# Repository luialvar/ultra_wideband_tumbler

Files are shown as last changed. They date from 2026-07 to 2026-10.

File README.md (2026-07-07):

# Tumbler UWB Subsystem Workspace

This repository organizes the hardware, mechanical-design, power-analysis, embedded-driver, and firmware material for the Tumbler UWB node in the AMADEE-27 university robotics project. The software migration from the older SKITH/DWM1000 platform to a newer STM32L4/DWM3000 PCB is a central part of the work, but it is not the whole project: the repository also captures the PCB, mechanical-integration, power-budget, and bring-up context needed to make the Tumbler subsystem usable.

The project is intentionally split by layer. The legacy folders are kept as engineering references, while the new CubeMX firmware and the Tumbler PCB are the active migration target.

## Project Context: AMADEE-27

This work was developed in the context of a university robotics project preparing a contribution for AMADEE-27, an international Mars analog mission managed by the Austrian Space Forum (OeWF).

AMADEE-27 is designed to emulate selected aspects of a human-robotic Mars mission. The mission concept combines analog astronauts, robotic systems, field experiments, and a Mission Support Center in Austria to recreate operational constraints similar to planetary exploration. The official AMADEE-27 call focuses on areas such as engineering and robotics, planetary surface operations, geoscience, life sciences, and human factors.

Within that broader university project, my responsibility was the Tumbler UWB subsystem rather than only a code port. That included understanding the old UWB localization stack, contributing to mechanical design and integration ideas, helping around the new PCB by studying the schematic/layout and matching it to firmware pin names, learning the practical hardware constraints, documenting the PCB and power-budget context, and preparing the new STM32CubeMX/HAL firmware structure for the upgraded PCB.

External context:

- Austrian Space Forum AMADEE-27 overview: https://oewf.org/en/amadee-27/
- AMADEE-27 Announcement of Opportunity: https://oewf.org/en/2025/12/amadee-27-ao/

## Tumbler Subsystem Scope

The important object in this repository is the Tumbler UWB subsystem as an integrated robot component. In practice, that means the work spans several connected areas:

- mechanical design exploration for fitting the electronics into the Tumbler concept,
- support and learning around the new PCB design, including how schematic/layout choices become firmware pin definitions,
- power-budget tracking for tag and anchor operating assumptions,
- low-level STM32L4/DWM3000 bring-up,
- migration of the old UWB ranging ideas onto a new CubeMX/HAL and Qorvo DW3xxx base.

The firmware migration is therefore one part of a larger embedded-system integration effort.

## Migration Summary

| Layer | Legacy platform | New platform |
| --- | --- | --- |
| Hardware | DWM1000-based SKITH board | DWM3000-based Tumbler board |
| Microcontroller | STM32F407 | STM32L431 |
| Framework | RODOS and legacy board wrappers | STM32Cube HAL generated by CubeMX |
| UWB driver | Decawave DWM1000 API | Qorvo DW3xxx driver |
| Application | Legacy tag/anchor ranging code | New CubeMX firmware for the new PCB |

## Repository Map

| Folder | Purpose |
| --- | --- |
| `SKITH_old_PCB/` | Legacy PCB design for the old SKITH UWB node. It represents the old hardware side of the DWM1000/STM32F407 platform. |
| `Tumbler_new_PCB/` | New PCB design for the upgraded UWB node. It contains the KiCad project, schematic sheets, layout, 3D exports, and production outputs for the DWM3000/STM32L431 board. |
| `power_calculations/` | Spreadsheet-based power budgets. The files are grouped around the old and new PCB assumptions, including anchor/tag operating modes. |
| `old_uwb_reference_repo/` | Legacy university toolkit component used as a software reference. It contains the old embedded DWM1000 firmware plus robot-side ROS localization code. |
| `software_new_pcb/` | New STM32CubeMX/HAL firmware for the new PCB. This is the active new-board software area. |
| `tumbler_images/` | Mechanical concept images and visual material for the Tumbler integration work. |
| `useful_links.txt` | Extra project links and references collected during development. |

## What Is Reused

The useful software inheritance is at the protocol level, not at the low-level driver level. The legacy code is valuable because it already contains the tag/anchor ranging flow, message types, timestamp packing, and two-way-ranging state machine. Those concepts can be ported to the new firmware.

The old Decawave DWM1000 driver, the RODOS scheduling code, the old SPI/GPIO wrappers, and the old board calibration constants should not be copied directly into the new STM32L431/DWM3000 firmware.

## Current Engineering Focus

The new firmware is built around STM32Cube HAL and the Qorvo DW3xxx driver. CubeMX describes the real wiring from the new PCB, including SPI, IRQ, reset, wakeup, power-control, and BMS-related pins. The firmware then uses those generated names in the board-port layer so that the UWB driver can talk to the DWM3000 through the actual hardware connections.

The practical bring-up path is:

1. Validate the CubeMX pin map against the Tumbler PCB schematic.
2. Bring up SPI, reset, wakeup, chip-select, and IRQ in the STM32 port layer.
3. Read the DW3xxx device ID through the Qorvo driver.
4. Test raw TX/RX frames.
5. Port the old tag/anchor ranging logic onto the new driver and HAL base.
6. Recalibrate antenna delays and timing for the new board.

## Engineering Highlights

This repository demonstrates a full embedded migration across hardware, firmware, and tooling boundaries:

- connecting mechanical integration constraints with the electronics layout,
- helping translate the new PCB design into a firmware-facing pin map,
- translating real PCB wiring into CubeMX/HAL pin definitions,
- replacing a legacy DWM1000 driver stack with the Qorvo DW3xxx driver,
- separating reusable ranging logic from non-reusable board/framework code,
- keeping only the required DW3xxx driver sources inside the firmware tree instead of storing the full vendor SDK,
- connecting firmware operating modes to spreadsheet-based power estimates.

## Notes for Reviewers

This repository is a migration and integration workspace, so it intentionally contains both original references and new implementation work. The separation is important: hardware design files document the boards, the power spreadsheets document expected operating modes, and the CubeMX firmware is where the new embedded software and DW3xxx driver integration are implemented.

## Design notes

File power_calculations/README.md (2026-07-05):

# Power Calculations

This folder contains spreadsheet-based power estimates for the UWB node designs.

The files cover two hardware generations:

| Power-budget family | Hardware context | Notes |
| --- | --- | --- |
| Legacy/earlier calculations | Older SKITH-style UWB assumptions | Kept as reference material for the DWM1000/STM32F407 generation. |
| `AmadeePannel3000.ods` | New DWM3000/Tumbler PCB assumptions | Main reference for the new DWM3000/STM32L431 design and its tag/anchor modes. |

## Files

| File | Purpose |
| --- | --- |
| `AmadeePannel3000.ods` | Power budget for the newer DWM3000-based board. It includes operating-mode assumptions such as TX, RX, idle, and sleep, and separates tag-style and anchor-style behavior. |
| `AmadeePannel_1.ods` | Earlier power-calculation reference. |
| `AmadeePannel_2.ods` | Earlier power-calculation reference. |
| `Power Calculation.xlsx` | Additional spreadsheet reference for the power budget. |
| `.~lock.AmadeePannel.ods#` | LibreOffice lock/temporary file. It is not an engineering input and should not normally be committed. |

## How to Read the Estimates

The power model combines two things:

1. The current consumed by the hardware in each mode.
2. The amount of time the firmware expects to spend in each mode.

The basic calculation is:

```text
energy = voltage * current * time
```

For a complete day, the spreadsheet adds the energy of the relevant modes:

```text
total energy = TX energy + RX energy + idle energy + sleep energy
```

This matters because tag and anchor roles do not behave the same way. A tag can often sleep for most of the time and wake up only for ranging exchanges. An anchor usually consumes more because it must listen for incoming UWB messages for much longer periods.

## Link to Firmware

The firmware cannot change the physical current of the DWM3000 or STM32 by itself, but it can control how long the system stays in TX, RX, idle, and sleep. That is why the power spreadsheets and the embedded state machine need to be reviewed together.

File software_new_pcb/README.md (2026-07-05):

# New PCB Software

This folder contains the firmware work for the new Tumbler PCB. This is the active software area for the new board.

## Target Platform

| Layer | New target |
| --- | --- |
| Hardware | Tumbler PCB |
| UWB module | DWM3000 family |
| Microcontroller | STM32L431 |
| Framework | STM32Cube HAL generated from CubeMX |
| UWB driver | Qorvo DW3xxx driver |
| Application goal | Port the legacy tag/anchor ranging logic onto the new board |

## Folder

| Folder | Purpose |
| --- | --- |
| `stm32l4/` | STM32CubeMX/CMake firmware project for the STM32L431-based PCB. |

The firmware target is described in more detail in `stm32l4/README.md`.

## Relationship to the Other Folders

The new firmware uses:

- `../Tumbler_new_PCB/` as the hardware pinout and board-design reference.
- `stm32l4/Drivers/dwt_uwb_driver/` and `stm32l4/Drivers/dwt_uwb_src/` as the local DW3xxx driver integration.
- `../old_uwb_reference_repo/embedded_uwb/` as the old application/protocol reference.
- `../power_calculations/` to understand expected current draw for tag and anchor operating modes.

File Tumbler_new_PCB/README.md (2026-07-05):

# Tumbler New PCB

This folder contains the new PCB design for the upgraded UWB node. It is the hardware target for the STM32CubeMX/HAL firmware in `../software_new_pcb/`.

In the overall migration, this is the new hardware platform:

| Layer | Value |
| --- | --- |
| UWB module | DWM3000 family |
| Microcontroller | STM32L431 |
| Firmware stack | STM32Cube HAL plus Qorvo DW3xxx driver |
| Role in this repository | Active hardware target for the new firmware |

## Contents

| File or folder | Purpose |
| --- | --- |
| `Amadee.kicad_pro` | Main KiCad project entry point. Open this file first in KiCad. |
| `Amadee.kicad_sch` | Top-level schematic. |
| `mcu.kicad_sch` | Microcontroller schematic sheet. |
| `B2Bconn.kicad_sch` | Board-to-board connector sheet. |
| `bms.kicad_sch` | Battery-management subsystem sheet. |
| `buck.kicad_sch` | Buck-regulator/power-conversion sheet. |
| `usb.kicad_sch` | USB-related circuitry. |
| `back-to-back-fets.kicad_sch` | Power-path/protection FET sheet. |
| `Amadee.kicad_pcb` | PCB layout. |
| `AmadeeTumbler.step` | 3D mechanical export for CAD review. |
| `AmadeeTumbler.stl` | 3D mesh export. |
| `AmadeeTumbler.pdf` | PDF design export for quick review. |
| `production/` | Manufacturing outputs. |
| `PowerCalc/` | Power-calculation spreadsheets colocated with the PCB project. |
| `lib/` | KiCad footprint/library assets used by the board. |

## Firmware-Relevant Signals

The PCB defines the real electrical wiring. CubeMX must mirror that wiring so the firmware can use the correct MCU pins for:

| Signal group | Why it matters in firmware |
| --- | --- |
| SPI | Data path between the STM32L431 and the DWM3000. |
| Chip select | Selects the UWB chip during SPI transactions. |
| IRQ | Lets the DWM3000 notify the MCU about TX/RX events. |
| Reset | Allows the MCU to reset the UWB module during bring-up. |
| Wakeup | Lets the MCU bring the UWB module out of low-power states. |
| Power and BMS pins | Control and monitor board power behavior. |

This is why the PCB and CubeMX project must agree. The PCB is the physical truth; CubeMX translates that physical wiring into generated C names used by the HAL and by the Qorvo driver port layer.

## Relationship to the Old PCB

The old `../SKITH_old_PCB/` design represents the DWM1000/STM32F407 generation. This folder represents the DWM3000/STM32L431 generation.

The migration is therefore not just a source-code copy. It changes the radio module, the MCU, the framework, the low-level driver, and the board pinout.

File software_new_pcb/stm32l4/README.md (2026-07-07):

# STM32L4 Firmware for the New PCB

This is the STM32CubeMX/CMake firmware project for the new STM32L431-based UWB PCB. It is the active software target for the migration from the old SKITH/DWM1000 platform to the new DWM3000-based board.

<p align="center">
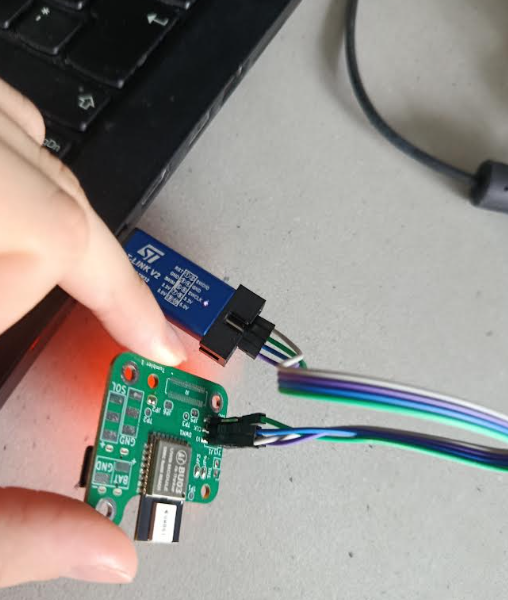
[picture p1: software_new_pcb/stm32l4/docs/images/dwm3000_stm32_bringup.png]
DWM3000 and STM32L4 bring-up wiring on the bench
  
</p>

<p align="center"><em>Bench wiring used while checking the DWM3000/STM32L4 bring-up path.</em></p>

## Migration Context

| Layer | Legacy stack | New stack in this folder |
| --- | --- | --- |
| Hardware | SKITH board with DWM1000 | Tumbler PCB with DWM3000 family module |
| Microcontroller | STM32F407 | STM32L431 |
| Framework | RODOS and legacy wrappers | STM32Cube HAL |
| UWB driver | Decawave DWM1000 API | Qorvo DW3xxx driver |
| Application | Old tag/anchor firmware | New CubeMX firmware for the new PCB |

The goal is to keep the useful ranging protocol concepts from the old firmware while replacing the hardware-dependent layers with CubeMX/HAL and the Qorvo DW3xxx driver.

## Project Structure

| Path | Purpose |
| --- | --- |
| `stm32l4.ioc` | CubeMX project file. It defines the STM32L431 device, clock tree, peripherals, and pin names. |
| `Core/` | STM32CubeMX-generated application skeleton and HAL initialization code. |
| `Drivers/CMSIS/` | ARM/ST CMSIS support generated/copied by STM32CubeMX. |
| `Drivers/STM32L4xx_HAL_Driver/` | STM32L4 HAL driver sources from the STM32Cube firmware package. |
| `Drivers/dwt_uwb_driver/` | Local Qorvo DW3xxx driver sources used by this firmware. |
| `Drivers/dwt_uwb_src/` | Local Qorvo support/example source files used by the DW3xxx driver integration. |
| `platform/` | Board-port layer connecting the Qorvo driver to STM32 HAL SPI, GPIO, reset, wakeup, and IRQ functions. |
| `Communication/` | Early send/receive helper functions for DW3xxx frame exchange. |
| `cmake/` | Toolchain and CubeMX CMake integration files. |
| `CMakeLists.txt` | Main firmware build definition. |

## CubeMX Pin Mapping

CubeMX translates the physical PCB wiring into generated C symbols. The important firmware-facing signals are:

| MCU pin | CubeMX label | Role |
| --- | --- | --- |
| `PA0` | `DWM_IRQ` | Interrupt from the UWB module. |
| `PA4` | `SPI1_NSS` | Software-controlled chip select for SPI. |
| `PA5` | `SPI1_SCK` | SPI clock. |
| `PA6` | `SPI1_MISO` | SPI data from DWM3000 to STM32. |
| `PA7` | `SPI1_MOSI` | SPI data from STM32 to DWM3000. |
| `PB0` | `EXTON` | External enable/control signal. |
| `PB1` | `WAKEUP` | Wakeup signal for the UWB module. |
| `PB2` | `DWM_nRST` | Reset line for the UWB module. |
| `PA9` | `BMS_SCL` | I2C clock for battery-management communication. |
| `PA10` | `BMS_SDA` | I2C data for battery-management communication. |

The PCB is the electrical source of truth. CubeMX mirrors that wiring, and the generated names are then used by `platform/port.c` so the Qorvo driver can access the real SPI and GPIO lines.

## Driver Integration

The Qorvo driver is not generated by CubeMX. The full DW3xxx/QM33 SDK is not stored as a separate folder in this repository; only the driver and support sources needed by this firmware are kept locally:

- `Drivers/dwt_uwb_driver/`
- `Drivers/dwt_uwb_src/`

The local project glue is mainly in:

- `platform/port.c`
- `platform/port.h`
- `platform/dw3000_config.c`
- `platform/dw3000_config.h`
- `Communication/communication.c`
- `CMakeLists.txt`
- `Core/Inc/main.h`
- `Core/Src/main.c`

## Current Bench and Debug Evidence

A recent GDB/OpenOCD debug capture shows the current firmware state:

- `build/stm32l4.elf` can be loaded in GDB and attached through `target extended-remote localhost:3333`, so the host debugger path is usable.
- Execution reaches `main()` and the current test loop in `Core/Src/main.c`.
- The firmware then spends time in the large `HAL_Delay(100000000000)` placeholder; this is bring-up scaffolding, not final runtime scheduling.
- A breakpoint reaches `send_msg_polling()` in `Communication/communication.c` with the test payload before `dwt_writetxdata(...)`, so the active firmware test surface is still raw DW3xxx frame transmission.
- Before treating TX/RX as validated, the communication helpers still need cleanup: `send_msg_polling()` should receive an explicit payload length instead of using `sizeof(msg)` on a pointer, and the receive path should clear the caller-provided buffer rather than the local pointer variable.

## Build

```shell
cmake -S . -B build -DCMAKE_TOOLCHAIN_FILE=cmake/gcc-arm-none-eabi.cmake -DCMAKE_UWB_CONFIG_OPTION=5
cmake --build build
```

## Flash

Flash the ELF with an ST-Link:

```shell
st-flash --reset write build/stm32l4.elf 0x8000000
```

If the `st-flash` version has issues with ELF flashing, convert the output to a binary first:

```shell
arm-none-eabi-objcopy -O binary build/stm32l4.elf build/stm32l4.bin
st-flash --reset write build/stm32l4.bin 0x8000000
```

## Debug

Start OpenOCD in one terminal:

```shell
openocd -f /usr/share/openocd/scripts/interface/stlink-v2.cfg -f /usr/share/openocd/scripts/target/stm32l4x.cfg
```

Open GDB in another terminal:

```shell
gdb build/stm32l4.elf
```

Connect to the OpenOCD GDB server:

```shell
target extended-remote localhost:3333
```

## Bring-Up Path

The recommended order is:

1. Confirm the CubeMX pin map against `../../Tumbler_new_PCB/`.
2. Validate SPI chip-select, reset, wakeup, and IRQ behavior in `platform/port.c`.
3. Read the DW3xxx device ID through the Qorvo driver.
4. Replace the placeholder delay/test loop and pass explicit message lengths through the communication helpers.
5. Send and receive a raw UWB frame.
6. Port the old tag/anchor protocol from `../../old_uwb_reference_repo/embedded_uwb/`.
7. Calibrate antenna delays and timing on the new PCB.

This keeps the migration clean: protocol logic is reused, but the hardware driver and board layer are native to the new DWM3000/STM32L431 platform.

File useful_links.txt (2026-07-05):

documentation chip:
http://galileo2.informatik.uni-wuerzburg.de/wiki/index.php/SKITH
http://galileo2.informatik.uni-wuerzburg.de/wiki/index.php/SKITH-Mainboard-STM32F4_Ver.2

Proposed Hardware:
https://voltaicsystems.com/1-watt-6-volt-solar-panel-etfe/
https://ydlbattery.com/products/3-7v-4000mah-606090-lithium-polymer-ion-battery-1
https://www.adafruit.com/product/390

Datasheets hardware:
https://voltaicsystems.com/content/P124_ds.pdf
https://www.honcell.com/Public/Uploads/uploadfile/files/20240628/DATASHEETHCP6060903.7V4000mAhCELL2024.pdf
https://cdn-shop.adafruit.com/datasheets/MCP73871.pdf

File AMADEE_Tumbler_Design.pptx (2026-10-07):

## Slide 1

Team: Tumbler Design

AMADEE-27

Tumbler
Design

Final semester meeting

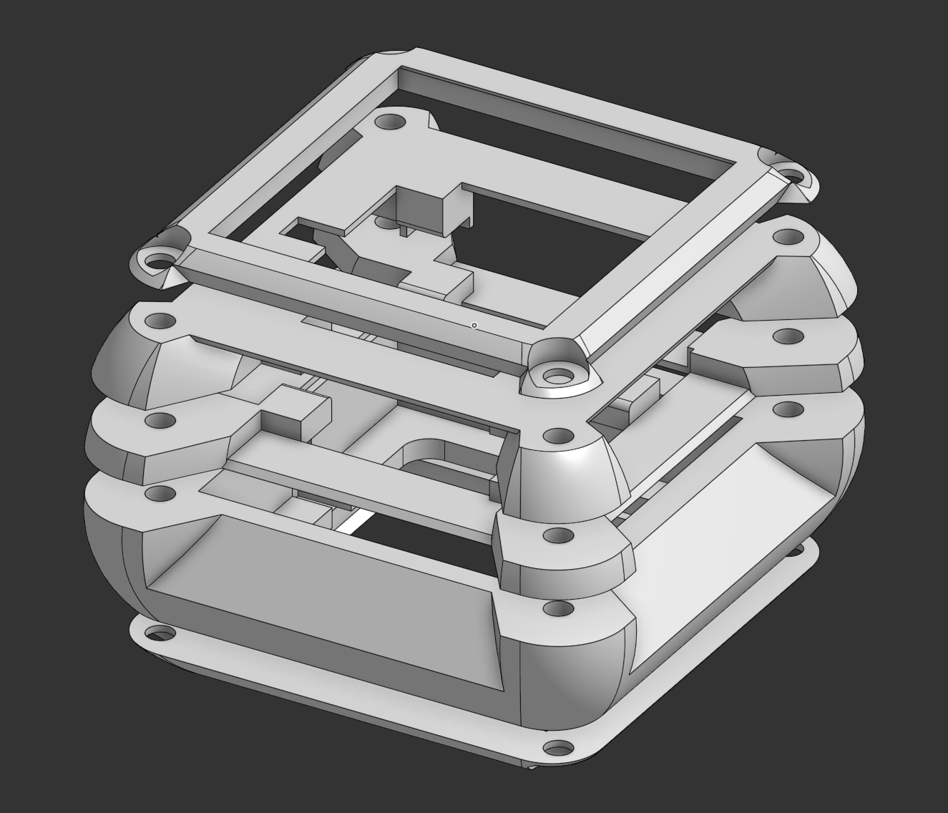
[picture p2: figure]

28 September 2026

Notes: Open the final meeting with a clear frame: team, work package, and format. Keep this under 15–20 seconds.

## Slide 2

TUMBLER DESIGN

What was the problem?

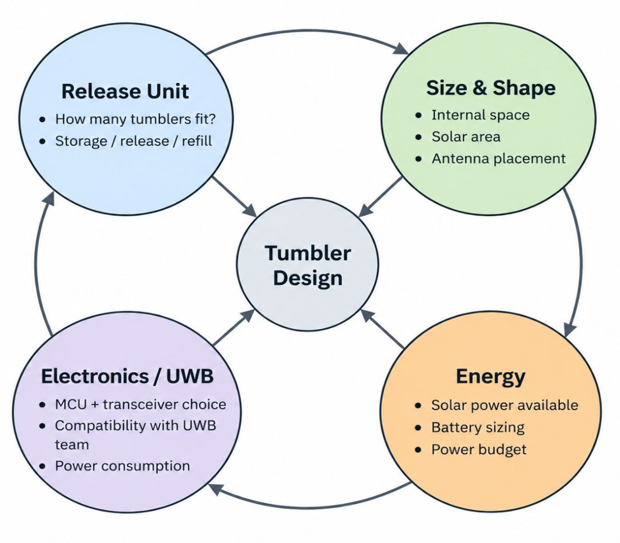
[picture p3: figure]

- autonomous Tumbler

- existing SKITH PCB

- STM32F407 + DWM1000

- RODOS-based UWB code

- Release Unit still open

Starting point

AMADEE-27 · Tumbler Design · Final Semester Meeting

2

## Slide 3

TUMBLER DESIGN

How did we structure the work?

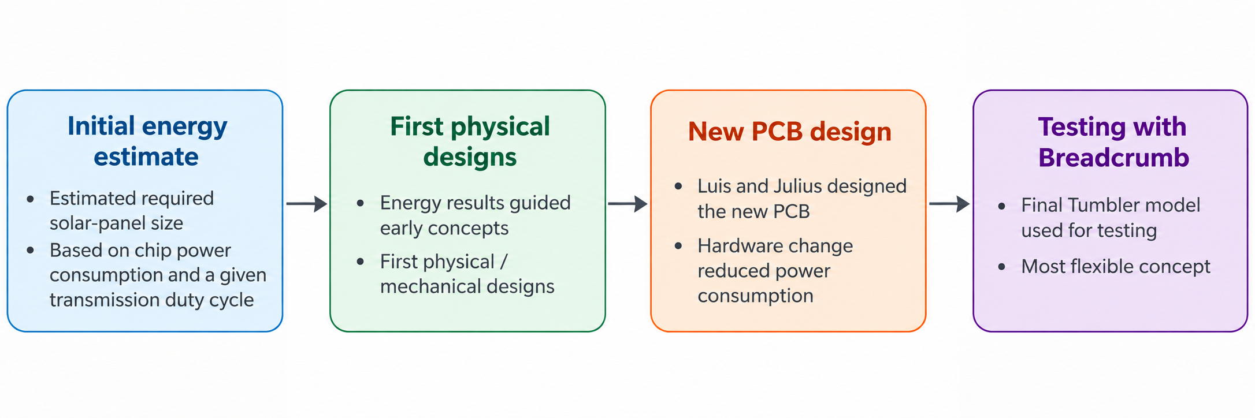
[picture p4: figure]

AMADEE-27 · Tumbler Design · Final Semester Meeting

3

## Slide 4

TUMBLER DESIGN

Power Requirement

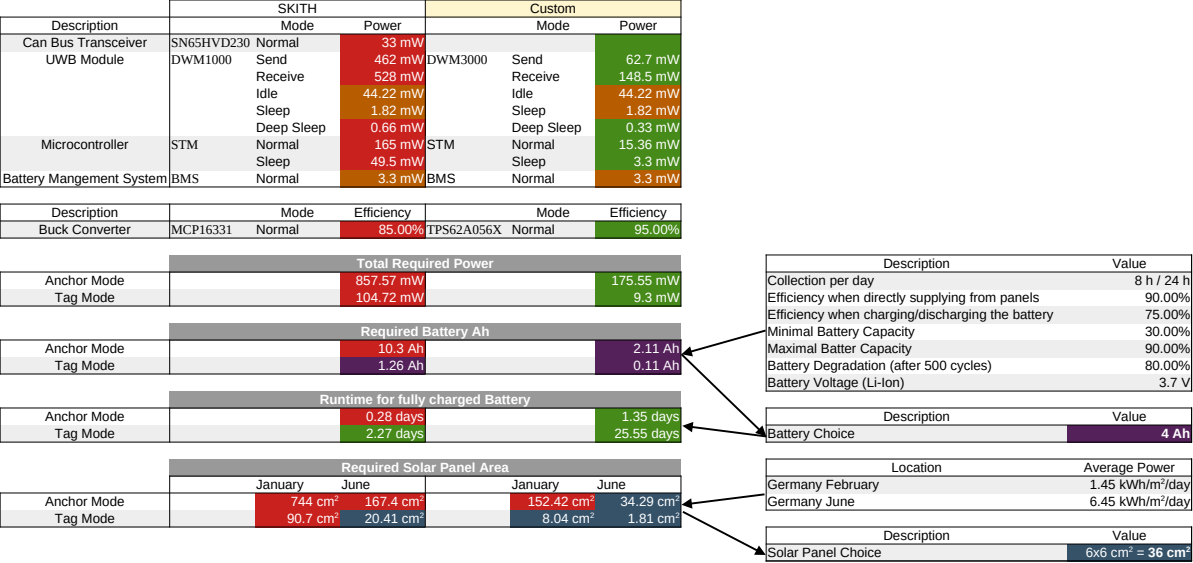
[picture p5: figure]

AMADEE-27 · Tumbler Design · Final Semester Meeting

4

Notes: Use this slide during the preparation call to decide the actual demo format.
For the final deck, either keep it as a short “Demonstration” slide or replace it with the actual demo material.
Assign responsibility: who brings the printed prototype, who opens CAD, who explains the test result.
Keep the demo short enough to leave time for Q&A.

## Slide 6

Tumbler Electronic Architecture

TUMBLER DESIGN

ETFE solar panel

a. P124 1.2W 6V ~ 5400 mm²
b. P122 0.3W 6V ~ 2500 mm²
- 24.4% high-efficiency
- Low friction, anti-dust surface
- IPX7 waterproof rated
Up to 5 panels can be soldered to the PCB
(in parallel)

Power Circuit

BQ25798 MPPT + Battery management
TPS62A056 High-Efficiency Buck Converter
4000mAh Lipo
Battery charging via USB-C interface

Microcontroller

STM32L431CCT6
- Ultra-low-power
- Arm Cortex-M4 MCU 80 MHz
- 256 Kbytes of Flash memory
- with FPU
- I2C and SPI
- standard ST-Link debugging

UWB Chip

DWM3000
Pin and pitch compatible with the DWM1000

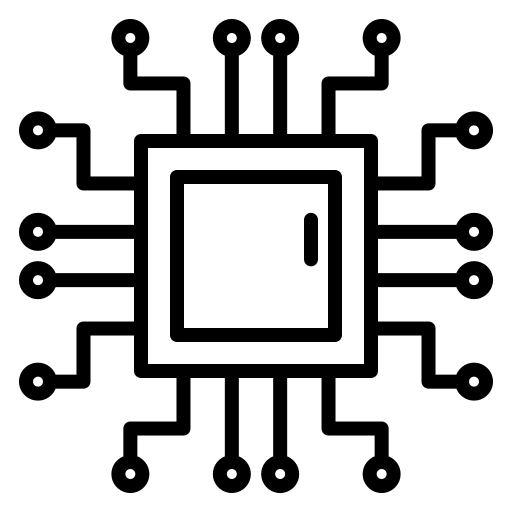
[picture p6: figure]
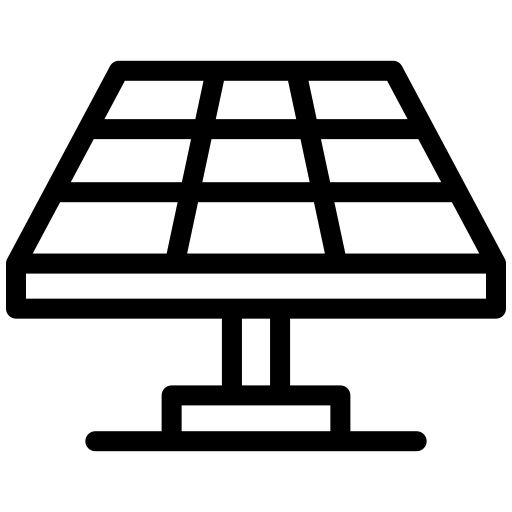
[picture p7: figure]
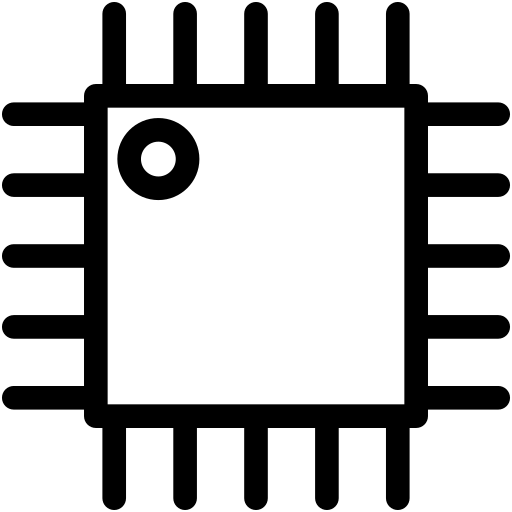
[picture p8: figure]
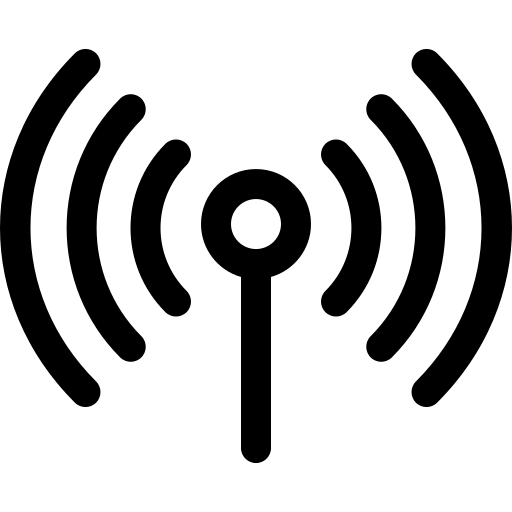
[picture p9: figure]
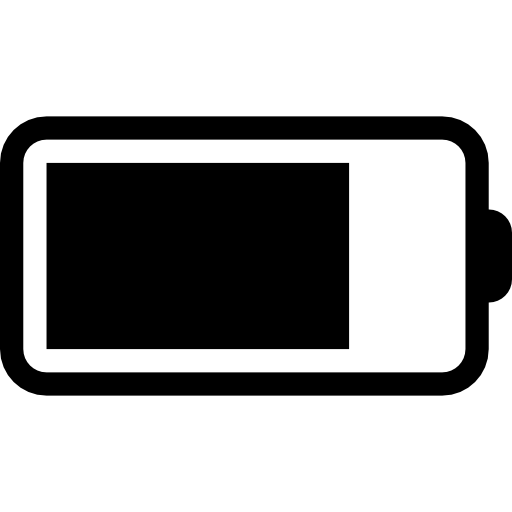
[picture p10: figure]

AMADEE-27 · Tumbler Design · Final Semester Meeting

5

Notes: Use this slide to show that the design was not arbitrary.
Mention that early discussions included release constraints, solar panel placement, internal layout and UWB signal considerations.
Do not overpromise exact requirements unless the team has numbers. Keep it qualitative unless someone fills in confirmed values.

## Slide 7

TUMBLER DESIGN

Tumbler PCB

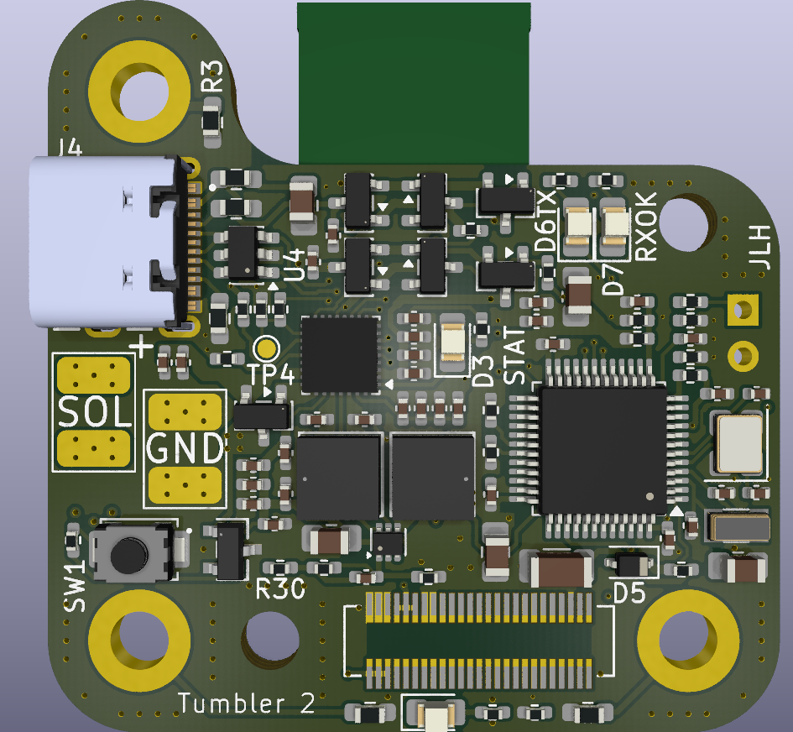
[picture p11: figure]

AMADEE-27 · Tumbler Design · Final Semester Meeting

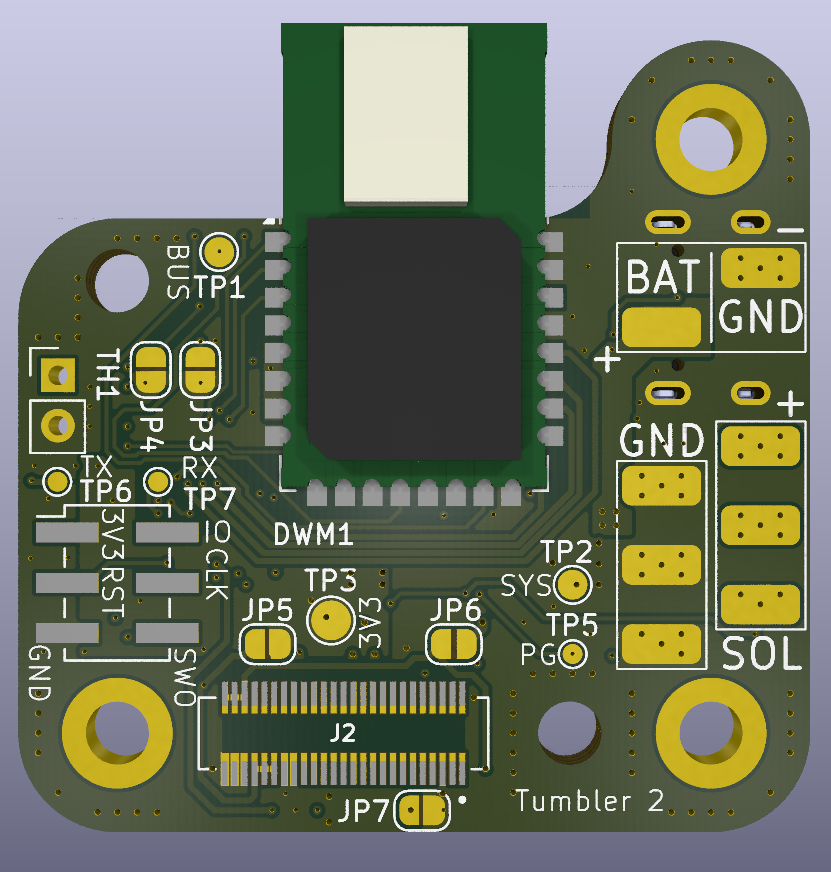
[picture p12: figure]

6

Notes: Use this slide to show that the design was not arbitrary.
Mention that early discussions included release constraints, solar panel placement, internal layout and UWB signal considerations.
Do not overpromise exact requirements unless the team has numbers. Keep it qualitative unless someone fills in confirmed values.

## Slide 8

Interface with the Release Unit

TUMBLER DESIGN

Release constraints

- stacking / pushing

- orientation-agnostic

Design response

- rigid alternatives

- release compatibility

AMADEE-27 · Tumbler Design · Final Semester Meeting

7

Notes: Mention that the release mechanism influenced the outer shape and handling of the Tumbler.
In the Release Unit chat, the initial assumption was that a compressible/foldable Tumbler might need to be held compressed and released by a mechanism.
I clarified that our group had also discussed rigid alternatives where compression would not be necessary.
Important message: the Tumbler was treated as part of a deployable system, not only as an isolated housing.
“Because the Tumbler is not an isolated object, the release mechanism was one of the first external interfaces we had to align with.”
Early interface alignment changed the design discussion from “one isolated housing” to a deployable sytsme component.
The Tumber geometry was iterated together with external deployment contraints – not chosen only for appearance.

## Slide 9

Concept comparison

TUMBLER DESIGN

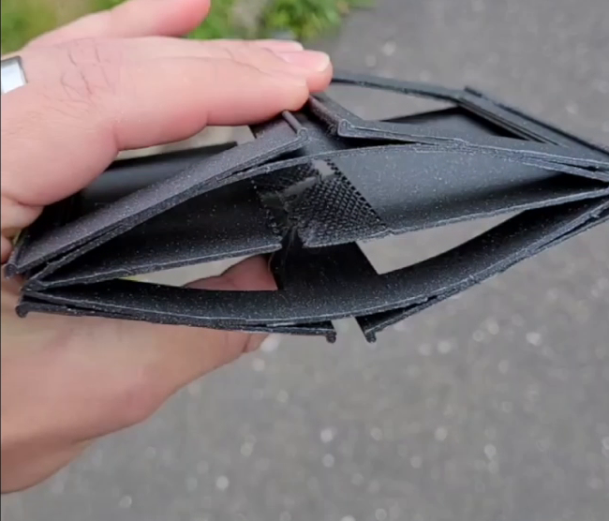
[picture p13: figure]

Flex / folded

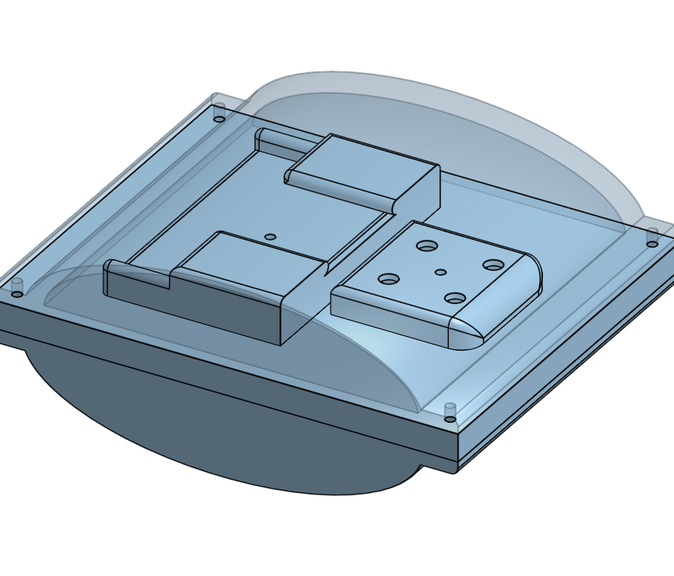
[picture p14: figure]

Oval

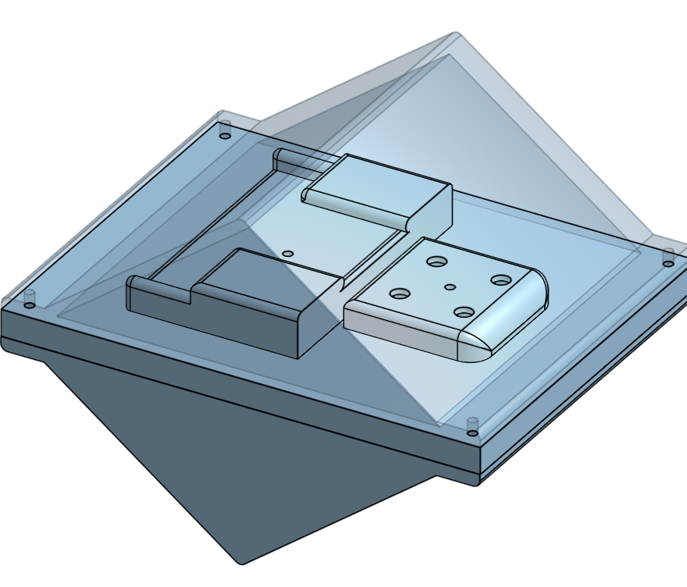
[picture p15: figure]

Prism

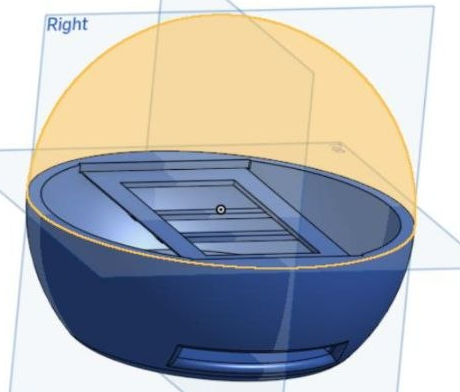
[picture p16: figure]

Sphere

AMADEE-27 · Tumbler Design · Final Semester Meeting

8

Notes: The designs developed in parallel and were compared as different solution directions, not as a competition between people.
Flex/folded: compact storage and compression idea, but more mechanically complex.
Oval/prism: rigid alternatives that avoided compression and were easier to reason about for release.
Spherical design: later became the basis for the current Breadcrumb direction.
The main selection dimensions were release compatibility, storage, solar-panel placement, internal volume, robustness and feasibility.
“We did not want to decide immediately on one perfect shape. Instead, we compared multiple concepts against the main constraints.”
Mention that the early rigid concepts helped clarify that a non-compressed, orientation-agnostic Tumbler would be easier for release.
The early phase intentionally kept several geometries open so the team could evaluate trade.offs before converging on the current Breadcrumb design.
The final direction was not a single first idea”; it results from the comparing deployment, panel area, internal layout, robustness and testability.

Nicht Sphere to breadcrumb, sondern Trends bei dem Prototyping die dann in Richtung Breadcrumb gingen.

Üvbergang zu dem Finalen Design:
Several issues were investigated during the semester; some became part of the final design, others were resolved through later geometry updates.
The design evolved through prototype-driven decisions. The geometry issue noticed during print preparation was trace to a wrong prat/revision selection and is fixed ion the current revision.
This slide should explain the real evolution: we did not start by picking one final design.
First, the group continued to work on all four directions in parallel.
Then the team focused on an improved spherical design because it combined strengths from the other approaches.
The sphere was flattened to improve storage in the Release Unit and make the geometry more space-efficient. This led to the Breadcrumb concept.

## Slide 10

TUMBLER DESIGN

Final mechanical design

Requirements:
- Compatible with the designs of the Tumbler release Unit..
- Ease of assembly in large numbers.
- Capable of good message reception and transmission.

AMADEE-27 · Tumbler Design · Final Semester Meeting

9

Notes: Likely owner: CAD/mechanical design owners.
Visible slide is intentionally clean: add final CAD images only.
Suggested content: what are the final parts, how are they assembled, how do solar panels sit in the housing, what changes were made after previous iterations.
If seals are no longer needed, explain calmly: “The updated geometry reduces/removes the sealing need that we had previously considered.”

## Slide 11

Status and next steps

TUMBLER DESIGN

completed / ready

- Tumbler geometry final

- PCB revision ordered

- mass-print ready

before next semester

- mass print: requested quantity

- order missing parts

- stock check

- storage preparation

before shipment

- final assembly

- handover

AMADEE-27 · Tumbler Design · Final Semester Meeting

10

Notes: The Tumbler design is finalized and can be mass-printed depending on the desired quantity.
The new PCBs have been ordered.
Before the next semester, the team should finish printing the required number of Tumbler parts, order any components that are not yet available in the required quantity, and store everything properly: Tumbler parts, batteries, solar panels and PCBs.
Before the hardware is shipped for the mission or later integration phase, the Tumblers can either be assembled by us, or if desired, an assembly guide could be provided so that assembly can happen later.
Avoid overclaiming: say the design work package is largely complete; the remaining tasks are procurement, production/storage and later assembly/integration.
The design work package is largely complete; the remaining work is focused on printing, procurement, storage and later assembly/integration.
The main design phase is finished; the next phase is turning the finalized parts into stroed, ready-to-assemble hardware for later AMADEE integration stage.
Mention the updated status: new PCBs are ordered and the Tumblers are finalized, so they can be printed in quantity.
Next concrete steps before the semester starts: final print, final orders, store components (Tumbler parts, batteries, solar panels, PCBs).
Later assembly is expected around November/December when the parts are actually needed.

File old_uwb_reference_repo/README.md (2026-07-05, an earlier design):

# Old UWB Reference Repository

This folder is the legacy UWB localization repository used as a reference for the migration. It comes from a university toolkit around UWB localization and includes both embedded firmware for the old SKITH boards and robot-side localization software.

It is not the target firmware for the new PCB. Its value is that it documents the old system architecture and contains reusable application-level ranging logic.

## Historical Context

This project gathers code connected to the UWB localization approach introduced in the included master-thesis PDF:

`An EKF-SLAM based Ultra Wideband Localization Approach for Unknown Anchor Distributions.pdf`

The repository is structured in two main parts:

| Folder | Purpose |
| --- | --- |
| `embedded_uwb/` | Embedded firmware for the old SKITH UWB boards. This is the main reference for the legacy tag/anchor ranging flow. |
| `robot/` | Robot-side ROS code, including UWB localization and EKF integration. |

## Role in the Migration

The old stack belongs to this generation:

| Layer | Legacy value |
| --- | --- |
| Hardware | SKITH board with DWM1000 |
| Microcontroller | STM32F407 |
| Framework | RODOS and legacy wrappers |
| Driver | Decawave DWM1000 API |
| Application | Tag/anchor ranging firmware and robot-side localization |

The new target is:

| Layer | New value |
| --- | --- |
| Hardware | Tumbler PCB with DWM3000 |
| Microcontroller | STM32L431 |
| Framework | STM32Cube HAL |
| Driver | Qorvo DW3xxx driver |
| Application | New CubeMX firmware for the new PCB |

## What Is Reusable

The useful reusable material is the application/protocol logic:

- tag/anchor message flow,
- `POLL`, `RESP`, `FINAL`, and distance-message structure,
- timestamp packing and unpacking,
- double-sided two-way-ranging timing math,
- node-state transitions and sequencing.

The old DWM1000 driver, RODOS scheduling code, ROS bridge, board wrappers, SPI/GPIO/reset plumbing, and antenna-delay constants are legacy-platform specific and should not be copied directly into the new STM32L431/DWM3000 firmware.

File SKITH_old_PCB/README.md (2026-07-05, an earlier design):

# SKITH Old PCB

This folder contains the legacy PCB design for the older SKITH UWB node used as the starting point of the migration.

In the overall project, this is the old hardware reference:

| Layer | Value |
| --- | --- |
| UWB module | DWM1000 |
| Microcontroller family | STM32F407 |
| Firmware stack used with this board | RODOS, legacy wrappers, Decawave DWM1000 API |
| Role in this repository | Hardware reference for the legacy platform |

## Contents

| File or folder | Purpose |
| --- | --- |
| `skithSTMv2.kicad_pro` | KiCad project entry point. Open this file in KiCad to inspect the board. |
| `skithSTMv2.kicad_pcb` | PCB layout. |
| `skithSTMv2.sch` | Legacy schematic file. |
| `Schaltplan_Skith_STM_2.pdf` | PDF schematic export for quick review. |
| `skithSTMv2.brd` | Board file from the older design flow. |
| `sym-lib-table` | KiCad symbol-library configuration. |
| `skithSTMv2.kicad_dru` | KiCad design-rule settings. |
| `skithSTMv2.kicad_prl` | KiCad local/session state; useful for KiCad, but not part of the engineering design itself. |

## How This Fits the Migration

This board is not the firmware target for the new implementation. It is included so the old DWM1000/STM32F407 hardware can be compared against the new DWM3000/STM32L431 design.

The old firmware associated with this hardware is kept separately in `../old_uwb_reference_repo/embedded_uwb/`. The PCB files here describe the electrical design: connectors, MCU pins, UWB module wiring, power rails, and board layout.

For the new board, see `../Tumbler_new_PCB/`.

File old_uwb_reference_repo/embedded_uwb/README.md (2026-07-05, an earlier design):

# Legacy Embedded UWB Firmware

This folder contains the embedded firmware for the old SKITH UWB boards. It is included as a reference for the new DWM3000/STM32L431 firmware, not as code that should be copied directly.

## Hardware

The original target is the SKITH UWB board from the University of Wuerzburg environment. The board combines:

| Part | Legacy platform |
| --- | --- |
| Microcontroller | STM32F4 family, specifically the STM32F407 generation in this project context |
| UWB transceiver | Decawave DWM1000 |
| Programming/debug | ST-Link over SWD |
| Framework | RODOS plus legacy board wrappers |

The hardware design files for the old board are stored separately in `../../SKITH_old_PCB/`.

## Software Structure

| Folder | Purpose |
| --- | --- |
| `decadriver/` | Legacy Decawave DWM1000 driver code. |
| `wrapper/` | Board-support wrappers around the old driver and platform. |
| `rodos/` | RODOS framework sources used by the old firmware. |
| `ros_lib/` | RODOS/ROS bridge support. |
| `include/` | Shared headers for the UWB application. |
| `src/common/` | Shared protocol, timestamp, and state-machine logic. |
| `src/anchor/` | Anchor role implementation. |
| `src/tag/` | Tag role implementation. |
| `src/id/` | Utility firmware for publishing/reading the chip identity. |
| `src/monitor/` | Monitoring firmware for observing UWB messages and bridging selected messages to ROS. |

## Reuse Boundary

Reusable for the new firmware:

- tag/anchor state-machine design,
- UWB message layout,
- `POLL`, `RESP`, `FINAL`, and `DISTANCE` sequencing,
- timestamp extraction and packing,
- double-sided two-way-ranging math.

Not reusable as-is:

- DWM1000 driver code,
- RODOS scheduling and thread structure,
- ROS bridge code,
- old SPI/GPIO/reset wrappers,
- old antenna-delay calibration constants.

The new firmware should port the application concepts onto the STM32Cube HAL and Qorvo DW3xxx driver base in `../../software_new_pcb/stm32l4/`.

## Legacy Build Notes

These commands describe the historical build flow for the old firmware:

```bash
sudo apt install -y apt-utils
sudo apt install -y clang clang-format clang-tools gdb
sudo apt install -y gcc-multilib g++-multilib
sudo apt install -y gcc-arm-none-eabi binutils-arm-none-eabi libnewlib-arm-none-eabi
sudo apt install -y cmake
```

```bash
cd build
cmake -DCMAKE_TOOLCHAIN_FILE=../rodos/cmake/port/skith.cmake ..
make all
```

Flashing was done over SWD with an ST-Link. The old workflow depends on the SKITH hardware setup and university-local documentation, so it should be treated as legacy reference material.

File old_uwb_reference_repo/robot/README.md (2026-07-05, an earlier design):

# Legacy Robot-Side UWB Localization

This folder contains the PC/robot-side software from the old UWB localization toolkit. It is included as context for the original system, especially the ROS-side localization and evaluation pipeline.

It is not part of the new STM32L431/DWM3000 firmware target.

## Runtime Entry Point

The `launch/robot.launch` file starts the robot-side stack and exposes several arguments:

| Argument | Purpose |
| --- | --- |
| `useRiegl` | Enables nodes for the Riegl scanner. Default: `false`. |
| `useHectorMapping` | Enables Hector SLAM. Default: `false`. |
| `useUwb` | Enables the UWB localization nodes, including `rosserial_server` and the EKF launch path. Default: `false`. |

The UWB serial setup includes configurable ports such as `/dev/UWB-back`, `/dev/UWB-front-right`, and `/dev/UWB-front-left`, with a default baud rate of `115200`.

## Package Map

| Package | Purpose |
| --- | --- |
| `lms100` | Interfaces with the SICK LMS100 2D laser scanner. |
| `rclock`, `riegl`, `riegl_scan_retriever`, `rivlib` | Interface with the Riegl VZ-400 laser scanner. |
| `rosserial_server` | Serial bridge to the UWB embedded boards. |
| `turtlesim_representation` | Python/turtlesim-based live visualization of localization systems. |
| `uwb` | UWB localization implementation and evaluation. |
| `volksbot` | Base robot code. |

## Migration Relevance

For the new PCB firmware, this folder is mainly useful for understanding how UWB measurements were consumed by the larger localization stack. The embedded migration itself should focus on `../embedded_uwb/` for the old tag/anchor protocol and on `../../software_new_pcb/stm32l4/` for the new firmware implementation.

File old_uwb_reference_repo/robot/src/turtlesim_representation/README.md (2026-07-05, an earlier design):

# Turtlesim Visualization

This package includes two real time visualization scripts, that use the python Turtle library.
The [anchorPoints](scripts/anchorPoints.py) script plots the position of the determined anchor positions for a given number of anchors. It also plots the mean and an ellipse representing the standard deviation along the x- and y-axis.
The [scenario](scripts/scenario.py) script plots varying localization methods in different colors (blue: only wheel odom, red: only UWB measurements, black: EKF, yellow: Hector-SLAM). It also shows a fixed ground truth for the location of the laser scans and the position of the anchors. This data must be manually written into the variable `truth_pos` in the script.

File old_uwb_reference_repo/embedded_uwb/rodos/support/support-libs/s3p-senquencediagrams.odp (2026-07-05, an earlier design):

## Synchronous mode

The application triggers the actions

When sending

Control Flow from Application to UART

Data Flow from Application to UART (Send & put)

When receiving

Control Flow from Application to UART

Data Flow from UART to Application (get)

## Send Synchronously

Triggered from Application. Data flow from application to UART (send*/put*)

S3P-Synchonous-Interface

S3pSenderSyncrhonous

UART/Radiolink

Driver

Application

sendMsg()

Waiting sendMsg() to conclude

putCommand(BOM)

putByte()

putDataByte(c)

putByte()

putDataByte(c)

putByte()

putCommand(EOM)

putByte()

sendMsg()

putCommand(BOM)

putByte()

putDataByte(c)

putByte()

## Receive Synchronously

Triggered from Application. Data flow from UART to application (get*)

S3P-Synchonous-Interface

S3pReceiverSyncrhonous

UART/Radiolink

Driver

Application

getMsg()

Waiting getMsg() to conclude

getByte()

getByte()

getByte()

getByte()

## Asynchronous mode

The UART/Radiolink triggers the actions

When sending

Control Flow from UART to Application

Data Flow from Application to UART (Send & put)

When receiving

Control Flow from UART to Application

Data Flow from UART to Application (Request & get)

## Receive Asynchronously

Triggered from UART. Data flow from UART to application (request*/put*)

S3P-Synchonous-Interface

S3pReceiverAsyncrhonous

UART/Radiolink

Driver

Application

putByte()

Interrupt

requestBufferToWrite()

BOM

Interrupt

data

Interrupt

Interrupt

endOfMessage()

data

data

EOM

Interrupt

requestBufferToWrite()

BOM

## Send Asynchronously (byte for Byte)

Triggered from UART. Data flow from application to UART (get*)

S3P-Synchonous-Interface

S3pSenderAsyncrhonous

Application

UART/Radiolink

Driver

Interrupt

getByteOrNODATA()

getByteOrNODATA()

Interrupt

respond BOM

getDualByte()

getDualByte()

respond data

getByteOrNODATA()

Interrupt

getDualByte()

respond data

getByteOrNODATA()

Interrupt

getDualByte()

Interrupt

respond EOM

getByteOrNODATA()

getDualByte()

Warning! When the UART stops sending

e.g. no data to send then we will get no more interrupts

from UART when ready to send! Solutions:

1. A timer interrupt checks periodically

2. The application calls retriggerSend() and we simulate an Interrupt

respond BOM

## Send Asynchronously (by messages)

Triggered from UART. Data flow from application to UART (request*/get*)

S3P-Synchonous-Interface

S3pMsgSenderAsyncrhonous

S3pSenderAsyncrhonous

UART/Radiolink

Driver

Application

getByteOrNODATA()

Interrupt

getDualByte()

getByteOrNODATA()

Interrupt

requestBufferToSend()

doing some thing else

BOM

Interrupt

data

getByteOrNODATA()

data

getDualByte()

getByteOrNODATA()

Interrupt

getDualByte()

Interrupt

EOM

getByteOrNODATA()

requestBufferToSend()

getDualByte()

Warning! When the UART stops sending

e.g. no data to send then we will get no more interrupts

from UART when ready to send! Solutions:

1. A timer interrupt checks periodically

2. The application calls retriggerSend() and we simulate an Interrupt

BOM

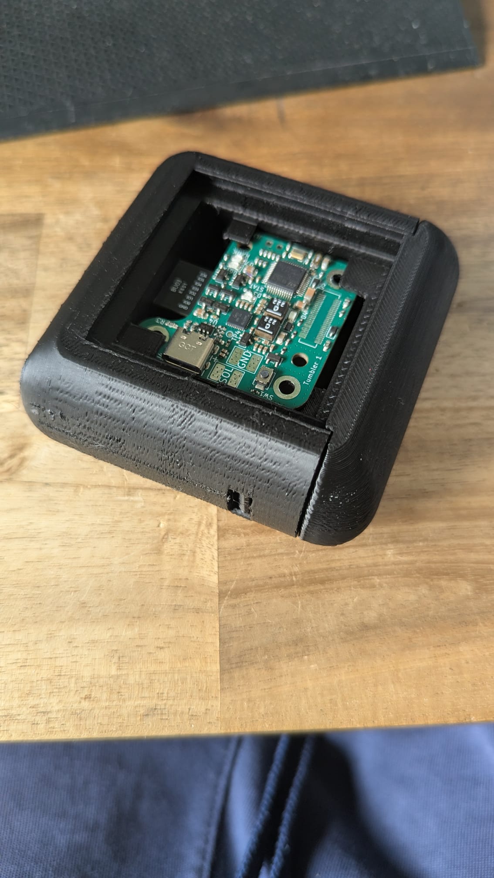
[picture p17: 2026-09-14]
tumbler_images/final_design_holes_2.jpg

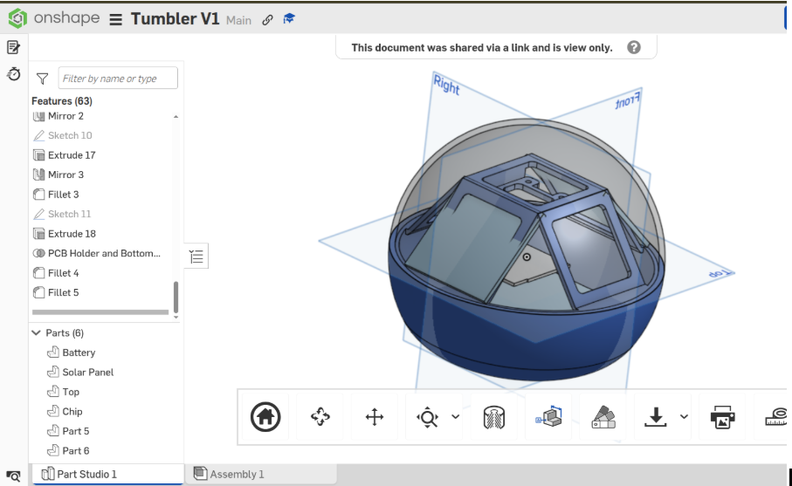
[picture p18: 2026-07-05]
tumbler_images/tumbler_design_2.png

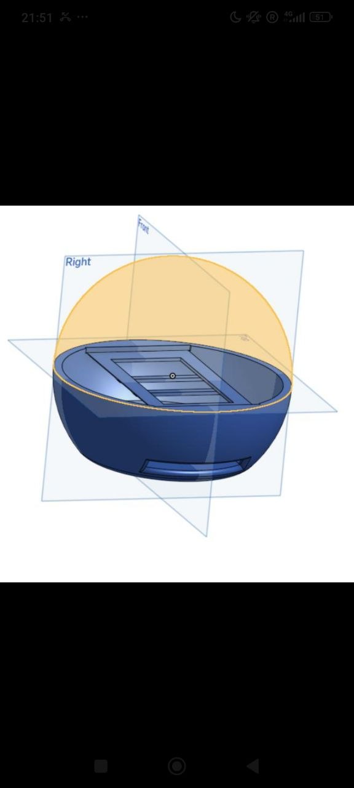
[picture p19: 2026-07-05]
tumbler_images/tumbler_design_3.jpg

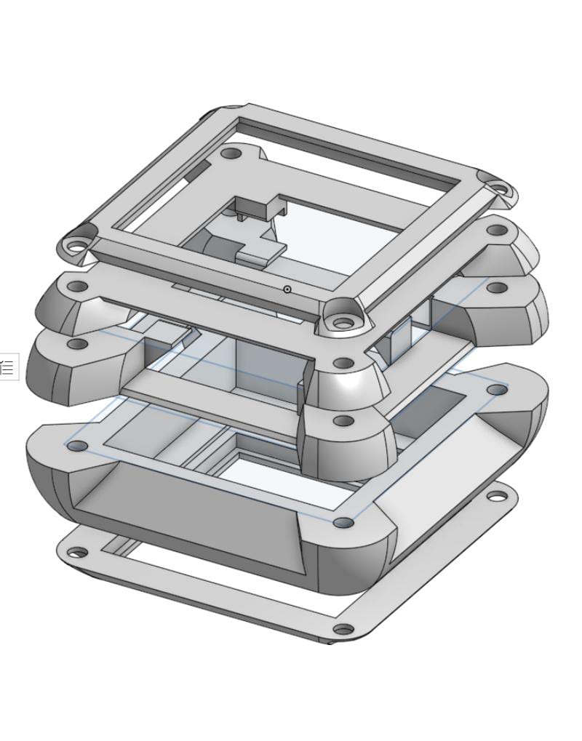
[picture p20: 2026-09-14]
tumbler_images/final_design_holes_1.jpg

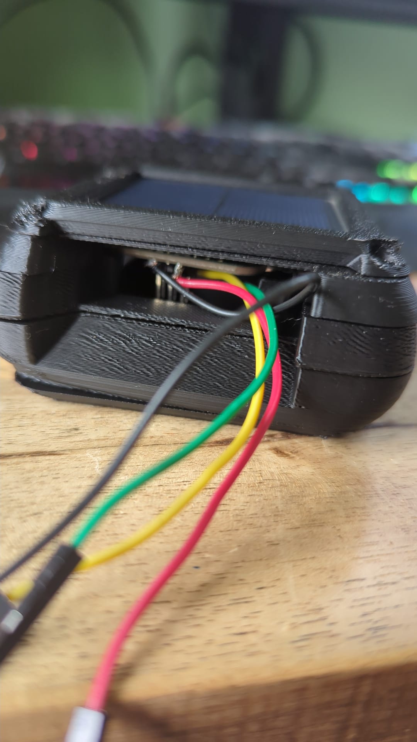
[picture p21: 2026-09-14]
tumbler_images/final_design_holes_3.jpg

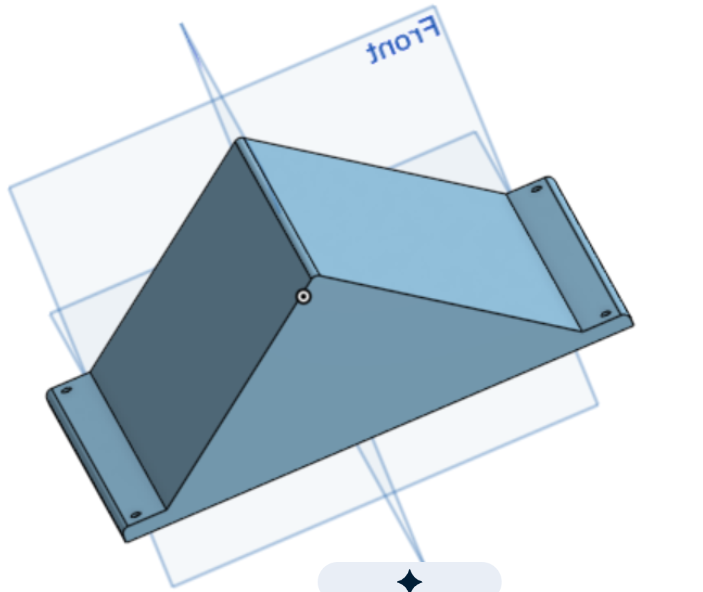
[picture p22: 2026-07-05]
tumbler_images/tumbler_design_1.png

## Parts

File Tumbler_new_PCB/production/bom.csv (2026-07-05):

Designator | Footprint | Quantity | Value | LCSC Part #
C1, C15, C2, C28, C31, C33, C34, C35, C38, C5, C9 | 0402 | 11 | 100nF
C10, C11, C12, C13, C14, C16, C17, C18, C19, C20, C3, C37, C4 | 0402 | 13 | 10uF
C21 | 0805 | 1 | 4.7uF X7R
C22, C36 | 0402 | 2 | 47pF
C23, C24 | 0805 | 2 | 22uF X7R
C25, C26 | 0402 | 2 | 15pF
C27 | 1206 | 1 | 100uF
C29 | 0805 | 1 | 4.7uF
C30, C32 | 0402 | 2 | 10pF
C39 | 0805 | 1 | 2.2uF
C6, C7 | 0402 | 2 | 47nF
C8 | 0402 | 1 | 4.7uF 10V
CR1 | CR_SOT-23_PTD | 1 | PSM712-LF-T7 | C32677
D1, D2 | SOT-23 | 2 | BZX84C10A | C5155278
D3, D4, D6, D7 | 0805 | 4 | LED 0805 | C2296
D5, D8 | D_SOD-323 | 2 | 1N5819WS
DWM1 | DWM1000 | 1 | DWM3000 | C42419011
J2 | HRS_DF12NC-50DS-0.5V_51_ | 1 | DF12NC-50DS-0.5V_51_ | C3647189
J3 | HRS_DF12NC_5.0_-50DP-0.5V_51_ | 1 | DF12NC_5.0_-50DP-0.5V_51_ | C3644230
J4 | GCT_USB4105-GF-A-120 | 1 | USB4105-GF-A-120 | C5184243
L1, L2 | IND_XGL4020_COC | 2 | XGL4020-222MEC
P1, P10, P11, P12, P2, P3, P4, P5, P6, P7, P8, P9 | SolderPad_4mm_2mm | 12 | SolderPad_4mm_2mm
Q1, Q2, Q3, Q4, Q5 | SOT-23 | 5 | AO3400A | C20917
R1, R2, R3 | 0603 | 3 | 1M
R10 | 0402 | 1 | 5.23k
R11 | 0402 | 1 | 30.1k
R12, R17 | 0402 | 2 | 100R
R13 | 0402 | 1 | 2k2
R14 | 0402 | 1 | 450k
R15, R25 | 0402 | 2 | 100k
R16, R24, R26 | 0402 | 3 | 510R
R18, R21, R22, R23 | 0402 | 4 | 10k
R19, R20, R4 | 0402 | 3 | 1M
R27, R28 | 0603 | 2 | 5.1k
R29 | 0603 | 1 | 2.2R
R5, R6 | 0402 | 2 | 300R
R7 | 0402 | 1 | 320k
R8 | 0402 | 1 | 680k
R9 | 0402 | 1 | 4.7k 1%-2%
SW1 | SW_SPST_TS-1088-xR020 | 1 | SW_Push | C720477
TP1, TP2, TP3 | TestPoint_Pad_D1.5mm | 3 | TestPoint
TP4 | TestPoint_Pad_D1.0mm | 1 | TestPoint
U1 | Texas_RQM0029A_VQFN-29_4x4mm_P0.4mm | 1 | BQ25798
U2 | SOT-563 | 1 | TPS62A056x
U3 | LQFP-48_7x7mm_P0.5mm | 1 | STM32L431CCT6 | C486681
U4 | SOT-23-6 | 1 | WE-TVS-82400102
Y1 | Crystal_SMD_3215-2Pin_3.2x1.5mm | 1 | 32.768kHz Q13FC13500004 | C32346
Y2 | Crystal_SMD_3225-4Pin_3.2x2.5mm | 1 | 16MHz X322516MLB4SI | C13738

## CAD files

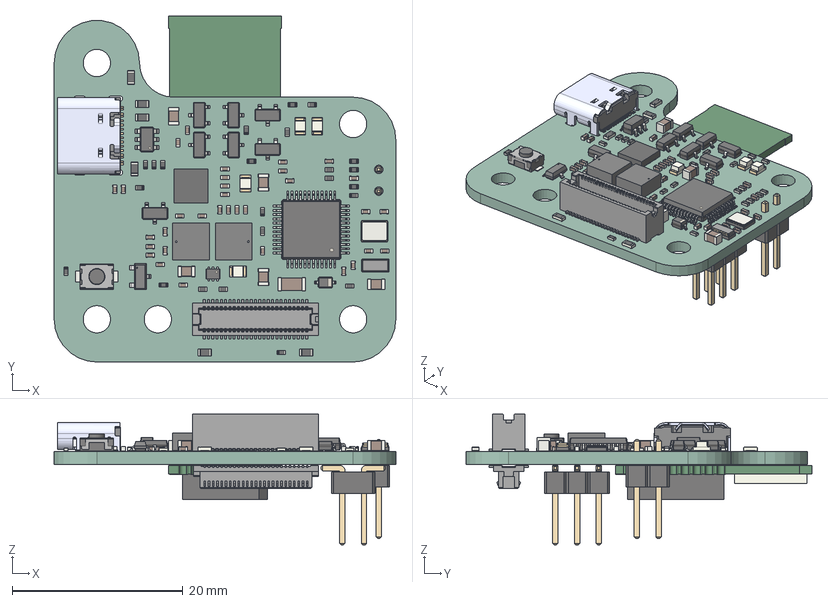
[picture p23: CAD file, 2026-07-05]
Tumbler_new_PCB/AmadeeTumbler.step
40.0 x 40.5 x 15.3 mm
C_0402_1005Metric x 33
SOT-23-6
C_0805_2012Metric x 5
LQFP-48_7x7mm_P0.5mm
R_0402_1005Metric x 23
R_0603_1608Metric x 6
SOT-23 x 7
LED_0805_2012Metric x 4
D_SOD-323
MOLD
C_1206_3216Metric
USB4105xxx_USB4105-GF-A-120
Crystal_SMD_3215-2Pin_3.2x1.5mm
SW_SPST_TS-1088-xR020
SOT_563
Crystal_SMD_3225-4Pin_3.2x2.5mm
DF12NC_5_0_-50DP.prt
PinHeader_2x03_P254mm_Vertical_SMD
DWM1000
PinHeader_1x02_P254mm_Vertical
DF12NC-50DS.prt
Amadee_PCB

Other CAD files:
Tumbler_new_PCB/AmadeeTumbler.stl

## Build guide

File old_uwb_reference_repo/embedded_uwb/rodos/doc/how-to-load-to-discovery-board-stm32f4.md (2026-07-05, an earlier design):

How to load compiled programs to discovery board
================================================

Compile your program using the rodos tools and target stm32f4 
If you are using the shell scripts you will get a **tst** file.
If your .elf file has another name than use the right name :)

Extract the binary data from tst and write for example tst.bin

```
   arm-none-eabi-objcopy -O binary tst tst.bin
```

Plug the discovery board to an USB port. You will get a file-manager window
(eg. Thunar). Now copy tst.bin to the new opened file-manager window.

To execute plug the USB out and in again. 
Else the programmer keeps the reset line active!

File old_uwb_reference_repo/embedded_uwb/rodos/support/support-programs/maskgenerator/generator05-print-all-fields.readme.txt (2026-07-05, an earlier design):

Generates a function to print all fields in the mask
BUT...

before you include your generated file you have to
add defines to say what is each field.
for example
#define NOW  getTime()
#define CNT  myInternalCounter

and define what is PRINTMASK
for example
#define PRINTMASK  printf

please note, it expected an integer for each field
and generates in the printf format with the maximal length
eg %6d

_______________________________________________________________ From

+---------------------------------+
| time now [NOW   ] counter [CNT] |
+---------------------------------+

_______________________________________________________________ generates

nst char* screen[] = {
"",
"+---------------------------------+",
"| time now [      ] counter [   ] |",
"+---------------------------------+",
"",
 0 };

#define CLEAR_MASK "\x1B[2J\x1B[1;1H"
#define INIT_MASK() PRINTMASK("%s", CLEAR_MASK); for(int i = 0; screen[i] != 0; i++) PRINTMASK("%s\n", screen[i]);

void printMaskContent() {
    PRINTMASK("\x1B[3;13H%6d", NOW);
    PRINTMASK("\x1B[3;30H%3d", CNT);
}

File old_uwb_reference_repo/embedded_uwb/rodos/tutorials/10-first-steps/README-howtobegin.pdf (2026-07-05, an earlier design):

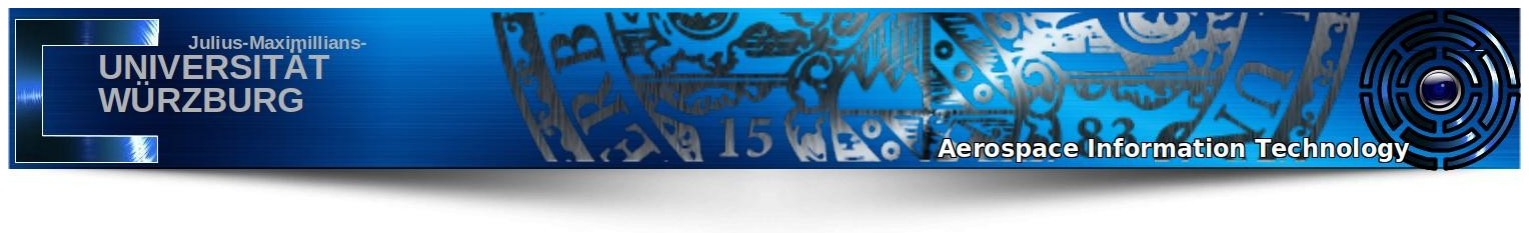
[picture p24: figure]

## RODOS

## How to get started with RODOS in 9 easy steps

Version: | 2.1
Date: | March. 2020
Author: | S. Montenegro

## 1. Before start

### 1.1. Notes on this tutorials

- A “$” means that the following command has to be executed in a terminal

### 1.2. RODOS directory structure

- | api | API and implementations for many different hardware platforms
- | build | Compiled libraries
- | doc | Documentation
- | scripts | Scripts for compilations on many different hardware platforms
- | src | Implementations for various platforms
- | support | Programmes and libs often used in space applications
- | tutorials | Examples, for you

### 1.3. Steps to compile and execute a RODOS program

1. Open a Terminal using the bash shell
2. Enter the RODOS root directory
3. Set some shell variables that are needed by the compile scripts $ source setenvs.sh
It has to be executed every time when opening a new terminal!
4. Compile the RODOS library for a Linux x86 PC
$ rodos-lib.sh linux-makecontext
(shell completion with tab shows the alternatives)

README-howtobegin-02.odt
Before start

2 / 20

Has to be done only once for every RODOS version, unless something in folder src or api has been modified.
5. Enter the folder with the user program
$ cd tutorials/10-first-steps
6. You may use different ports and target architectures. In these examples we will use linux-make-context (linux-makecontext). To see the list of alternatives, see in the build-scrtips directory the files in set-vars.
7. Compile the user programme
$ rodos-executable.sh linux-makecontext usercode1.cpp usercode2.cpp…
or/and, read and execute the scripts execute-example-*.sh
8. Execute the binary
$ ./tst
9. Exit the program with Ctrl+C
As a shortcut, a file has been created for every example that compiles the necessary code-files and executes it (e.g. execute-example-01.sh for the example in chapter 1). Attention: Don't forget to do step 1 to 5 beforehand.
At the end of the paper, there is a short summary about all programmes.

## 2. Hello World

The Hello World tutorial is the most simple RODOS program. It only prints the string “Hello World!” in one thread.

### 2.1. Used RODOS functions

- PRINTF( )
basically the same as the standard C printf() function – prints characters and numbers to terminal

### 2.2. Programme helloworld.cpp

#include "rodos.h"

class HelloWorld : public StaticThread<> {

void run(){
PRINTF("Hello World!\n");
}
} helloworld;

includes the RODOS API

defines a Thread named HelloWorld

implements the code for the main task of the thread
In this case: print “Hello World!” instantiates one thread of type HelloWorld

Hello World

3 / 20

### 2.3. Compiling

Compile the tutorial as described in chapter 2, in the following steps:
1. Open a Terminal
2. Enter the RODOS root directory
3. Set some shell variables that are needed by the compile scripts $ source setenvs.sh
It has to be executed every time when opening a new terminal!
4. Compile the RODOS library for a Linux x86 PC
$ rodos-lib.sh linux-makecontext
Has to be done only once for every RODOS version, unless something in folder src or api has been modified.
5. Enter the folder with the hello world tutorial
$ cd tutorials/10-first-steps
6. Compile the user program
$ rodos-executable.sh linux-makecontext helloworld.cpp
7. Execute the binary called tst
$ ./tst
8. Exit the program with Ctrl+C

### 2.4. Console output

After some RODOS Information:
--------------- application running ------------Hello World!

### 2.5. Several Threads

Try now helloworld-multiple.cpp. Do you see the difference?

### 2.6. Annotation

For several programmes exist shell scripts that compile and execute their programme. Just have a look into the scripts.

printout of run() method

Basic structure

4 / 20

## 3. Basic structure

The Basic structure tutorial is an extension to the Hello World tutorial. It prints the string “Hello World!” and implements the basic structure of a RODOS program consistent of one application and one thread.

### 3.1. Used RODOS functions

- PRINTF( )
basically the same as the standard C printf() function – prints characters and numbers to terminal

### 3.2. Programme basic.cpp

#include "rodos.h"

static Application appHW("HelloWorld");

class HelloWorld : public StaticThread<> {

public:

HelloWorld() : StaticThread<>("HelloWorld") { }

void init() {
PRINTF("Printing Hello World");
}

void run(){
PRINTF("Hello World!\n");
}
}

static HelloWorld helloworld;

### 3.3. Compiling

Compile the tutorial as described in 2.3, in the following steps:
1. Open a Terminal
2. Enter the RODOS root directory
3. Set some shell variables that are needed by the compile scripts $ source setenvs.sh

includes the RODOS API

defines a thread named HelloWorld

thread constructor with definition of the thread name

is called before the scheduler starts

implements the code for the main task of the thread
In this case: print “Hello World!”

instantiates one thread of
type HelloWorld

application that wraps all threads, events,... in this file

Basic structure

5 / 20

It has to be executed every time when opening a new terminal!
4. Compile the RODOS library for a Linux x86 PC
$ rodos-lib.sh linux-makecontext
Has to be done only once for every RODOS version, unless something in folder src or api has been modified.
5. Enter the folder with the hello world tutorial
$ cd tutorials/10-first-steps
6. Compile the user program
$ rodos-executable.sh linux-makecontext basic.cpp
7. Execute the binary
$ ./tst
8. Exit the program with Ctrl+C
9. Modify the run() method in basic.cpp 10.Repeat step 6 to 8 and see the difference

### 3.4. Console output

RODOS RODOS-100.0 OS Version RODOS-linux-8 Loaded Applications:
10 -> 'Topics & Middleware' 1000 -> 'HelloWorld'
Calling Initiators
Distribute Subscribers to Topics
List of Middleware Topics:
CharInput Id = 28449 len = 12. | -- Subscribers:
SigTermInterrupt Id = 16716 len = 4. | -- Subscribers:
UartInterrupt Id = 15678 len = 4. | -- Subscribers:
TimerInterrupt Id = 25697 len = 4. | -- Subscribers:
gatewayTopic Id = 0 len = 12. | -- Subscribers:

Event servers:
Threads in System:
Prio = | 0 Stack = 32000 IdleThread: yields all the time
Prio = | 100 Stack = 32000 HelloWorld: Printing Hello World
BigEndianity = 0, cpu-Arc = x86, Basis-Os = baremetal, Cpu-Speed (K-Loops/sec) = 350000
Default internal MAIN
--------------- application running ------------Hello World!

shows defined threads and printout of init method

RODOS version

all applications in this programm

printout of run() method

Time

6 / 20

## 4. Time

This tutorial shows how time dependent processes can be modelled in RODOS. It demonstrates how to do something at a specific point in time, after a defined amount of time and periodically. While the thread waits for the defined time, other threads can be executed. Time in RODOS is defined with a long long type “TTime” and represents the number of nanoseconds elapsed since start-up.

### 4.1. RODOS time functions

- NOW()
Returns the current time (in nanoseconds)
- SECONDS_NOW()
Returns the current time in seconds
- AT(time)
Suspends (interrupts) the thread that has called this method, until the given point in time is reached
- TIME_LOOP(firstExecution, Period) { … }
Almost each control loop has a start time and a period. This macro provides this loop with no end.

### 4.2. Time macros

In order to use the time functions comfortably there are some time macros defined: NANOSECONDS , MICROSECONDS , MILLISECONDS , SECONDS , MINUTES, HOURS , DAYS , WEEKS , END_OF_TIME
To use them, just multiply them to the amount of time, e.g. AT(3*SECONDS) . END_OF_TIME is the highest time possible (about 293 years).

### 4.3. Programme time.cpp

PRINTF("waiting until 3rd second after start\n"); AT(3*SECONDS);
PRINTF("after 3rd second\n");

PRINTF("waiting until 1 second has pased\n"); AT(NOW()+1*SECONDS);
PRINTF("1 second has pased\n");

PRINTF("print every 2 seconds, start at 5 seconds\n"); TIME_LOOP(5*SECONDS, 2*SECONDS){
PRINTF("current time: %3.9f\n", SECONDS_NOW());
}

waits for the point in time: 3 seconds after start

waits for 1 second
code in the loop will
be executed every 2
seconds; the first
execution will be at
5 seconds after start

Time

7 / 20

### 4.4. Compiling and console output

Compile the tutorial time.cpp in tutorials/10-first-steps as described in 2.3 and execute it. The output should be the following:
waiting until 3rd second after start
after 3rd second
waiting until 1 second has pased
1 second has pased
print every 2 seconds, start at 5 seconds
current time: | 5.000003995
current time: | 7.000004191 ...

Thread Communication

8 / 20

## 5. Thread Communication

The communication between two threads can bee realized via a CommBuffer or a FiFo (First in first out). For that a CommBuffer or a FiFo has to be defined outside a thread so that both threads can access it.

### 5.1. CommBuffer

A CommBuffer is a double buffer with only one writer and only one reader. Both can work concurrently. The writer may write at any time. The reader gets the newest consistent data (eg. the last complete written record). The type of the CommBuffer can be defined. Not using a CommBuffer is risky, because maybe the data is half written in the shared variable while the thread is interrupted. In this case the receiver thread gets inconsistent data.

### 5.1.1. Programme commbuffer.cpp

CommBuffer<int> buf;

class Sender : public StaticThread<> { ...
PRINTF("Writing %d\n", cnt); buf.put(cnt);
}

class Receiver : public StaticThread<> { ...
buf.get(cnt);
PRINTF("Reading %d\n", cnt);
}

Compile the tutorial commbuffer.cpp in tutorials/first-steps as described in 2.3 and execute it.

### 5.2. FiFo

A FiFo is used for synchronous communication from one single writer to one single reader. Writing to a full FiFo has no effect and returns 0. Reading from an empty FiFo returns 0. The first value inserted into the FiFo will be the first value to be read.

CommBuffer of type Integer

thread puts local counter data into the CommBuffer

thread gets counter data from the CommBuffer and saves it into local variable

Thread Communication

9 / 20

### 5.2.1. Programme fifo.cpp

Fifo<int, 10> fifo;

class Sender : public StaticThread<> { ...
bool ok = fifo.put(cnt);
}

class Receiver : public StaticThread<> { ...
bool ok = fifo.get(cnt);
}
Compile the tutorial fifo.cpp in tutorials/first-steps as described in 2.3 and execute it.

### 5.3. Synchronous FiFo

A SyncFiFo is basically the same as FiFo, but in this case the sender will be suspended if the FiFo is full and the receiver will be suspended until data is ready. Compile the tutorial fifo_sync.cpp in tutorials/10-first-steps as described in 2.3 and execute it.

### 5.4. Which is best for what?

If the receiver needs only the latest data a Commbuffer should be used. If the receiver needs all the data from the sender and in the right order, a FiFo is the way to do it. A SyncFiFo is a good option if the data has to be processed short times after sending it, but take notice that the thread cannot do anything until new data is available.

FiFo for 10 Integer values

receives the current counter value from the fifo and checks whether the fifo is empty

puts the current counter value into the fifo and checks whether the fifo is full

Critical sections

10 / 20

## 6. Critical sections

To avoid concurrent access of critical sections semaphores have to be used. To enter a semaphore use sema.enter() and to leave use sema.leave(). I

### 6.1. RODOS functions

- Semaphore::enter()
Makes a thread enter a semaphore. All other threads trying to enter the same semaphore will wait until it has been left again.
- Semaphore::leave()
Leaves the semaphore and allows other threads entering it.
- { PROTECT_IN_SCOPE(sema); … }
A macro entering the semaphore "sema" when entering in the current scope (between surrounded { and } ). and leaving it when leaving the scope, It is only a short cut, which may be useful .... or maybe not.
- yield()
Interrupts the current thread and calls the scheduler that looks for a thread to execute. If no other thread wants to be executed, the thread continues.

### 6.2. Programme semaphore.cpp

Semaphore onlyOne;
onlyOne.enter();
PRINTF(" only one, I am -- %02d -- ,", myId); yield();
PRINTF("time %3.9f\n", SECONDS_NOW()); onlyOne.leave();

### 6.3. Programme semaphore_macro.cpp

The same functionality but using the macro short cut. ...
{
PROTECT_IN_SCOPE(onlyOne);
PRINTF(" only one, I am -- %02d -- ,", myId); yield();
PRINTF("time %3.9f\n", SECONDS_NOW());
}

protection with semaphore “onlyone” semaphore definition outside the threads

printout interrupted by
yield, but because of the
semaphore no other
thread can print between
the id and the time printout enters semaphore “onlyone”

leaves semaphore “onlyone”

end of the chritical section

Critical sections

11 / 20

### 6.4. Compiling and console output

Compile the tutorial semaphore.cpp in tutorials/10-first-steps as described in 2.3 and execute it. The output should be the following:
only one, I am -- A -- ,time | 3.000056382
only one, I am -- B -- ,time | 3.000077366
only one, I am -- C -- ,time | 3.000094338
only one, I am -- D -- ,time | 3.000111110
only one, I am ---E -- ,time | 3.000128005
only one, I am -- F -- ,time | 3.000157338
only one, I am -- G -- ,time | 3.000180353

Remove the protection in semaphore.cpp, compile again and see the difference.

### 6.5. Attention: A deadlock may occur!

Compile and have a look at the tutorial semaphore_deadlock.cpp. The programme will stop when a deadlock has occurred.

Events

12 / 20

## 7. Events

Events can be used to react to interrupts from timers and signals from devices. Do not use them for complex actions, because they cannot be interrupted. Just use them to trigger threads that handle the interrupts. Implement them as short as possible. An event has basically two methods: The init() method similar to threads and the handle() method in which the code is defined that handles the event.

### 7.1. RODOS functions

- activatePeriodic(startTime, period)
Activates an event periodically after the first activation at startTime.
- activateAt(time)
Activates an event at the given point in time.
- thread.resume()
Resumes a thread that is suspended.

### 7.2. Programme event.cpp

class TestWaiter: public StaticThread<> {
PRINTF("Suspend and wait until some one resumes me\n"); AT(END_OF_TIME);
PRINTF("testwaiter running again at %3.9f\n", SECONDS_NOW()); ...
}

class TimeEventTest : public TimeEvent {
public:
void handle(){
xprintf(" Time Event at %3.9f\n", SECONDS_NOW()); testWaiter.resume();
xprintf(" Testwaiter resumed from me\n");
}

void init() { activatePeriodic(5*SECONDS, 3*SECONDS); } };

### 7.3. Compiling and console output

Compile the tutorial event.cpp in tutorials/10-first-steps as described in 2.3 and execute it. The output should be the following:

suspends the thread forever

defines an event

defines when the event is beeing raised could also use activateAt(time)

handles the event

resumes the suspendend thread

Events

13 / 20

Suspend and wait until some one resumes me Time Event at 5.000107974
Testwaiter resumed from me
testwaiter running again at 5.000135475 Suspend and wait until some one resumes me Time Event at 8.000168306
Testwaiter resumed from me
Try the example with activateAt(time) instead of activatePeriodic(startTime, period).

Middleware

14 / 20

## 8. Middleware

Up to here, we had "normal" programming. Now assume we are in a big team with a big project. You do not know the details of what others are programming, just the format of the data you need from them or you produce for them. Now you have to get and distribute this data without notion of the other side of this generic interface which we call the middleware.
The middleware is used to communicate between tasks and even between tasks of different RODOS nodes. This communication is based on a publisher/subscriber protocol and there is no connection from a sender to a receiver.
Any thread can publish messages under a given topic, while subscribers of the same topic receive the published data.
There can be 0, 1 or many publishers for one topic. The same goes for subscribers.

### 8.1. Required files

For this example you will need flowing files:
sender.cpp | The one who sends test message: a publisher
topics.h, topics.cpp | communication channels to send and receive data
receiver_* | different methods to subscribe and get data: Subscribers
You will need to compile several source files together. Every compilation needs to include the file topics.cpp
for example:
$ rodos-executable.sh linux-x86 topics.cpp sender.cpp receiver_commbuff.cpp
or another receiver:
$ rodos-executable.sh linux-x86 topics.cpp sender.cpp receiver_putter.cpp
or all receivers together:
$ rodos-executable.sh linux-x86 topics.cpp sender.cpp receiver_*.cpp

### 8.2. Topic, program topics.cpp

A topic is a pair of a data-type and the topic id, e.g.:
Topic<long> counter1(10, "counter1");

If the topic id is “-1” the id will be generated.

data type of
published
messages

name of the topic

topic id

Middleware

15 / 20

### 8.2.1. Sample topics

Some sample topics are defined in topics.cpp. To use these topics in a RODOS programme include topics.h.

### 8.3. Publisher

A publisher is easy to implement. To publish data under the topic “counter” just use counter.publish(data) in any thread.

### 8.3.1. Programme sender.cpp

#include "topics.h"

TIME_LOOP(3*SECONDS, 3*SECONDS) { PRINTF("Publisher01 sending Counter1 %ld\n", ++cnt); counter1.publish(cnt);
}

### 8.4. Subscriber

There are many possibilities to implement a receiver of middleware data.

### 8.4.1. Subscriber put() method, program receiver_simple.cpp

Define a new subscriber by inheriting from “Subscriber”:
class SimpleSub : public Subscriber {
public:
SimpleSub() : Subscriber(counter1, "simplesub") { }

long put(const long topicId, const long len, const void* data, ...) { PRINTF("SimpleSub - Length: %ld Data: %ld ...
return 1;
}
} simpleSub;

Compile the tutorial receiver_simple.cpp in tutorials/first-steps as described in chapter 2 and execute it. Do not forget to compile it with topics.cpp and sender.cpp: $ rodos-executable.sh linux-x86 topics.cpp sender.cpp receiver_simple.cpp

### 8.4.2. Subscriber and a CommBuffer, program receiver_combuf.cpp

Define a CommBuffer that is going to be filled by a Subscriber. The thread gets periodically the latest data from the CommBuffer.

includes the topics

publishes every 3 seconds the incremented counter

subscribing for counter1

the put function is called everytime new data has been published; receive the data in this method and send it to a thread via CommBuffer or Fifo (it is also possible to resume a thread when new data is available)

Middleware

16 / 20

static CommBuffer<long> buf;
static Subscriber receiverBuf(counter1, buf, "receiverbuf");

class ReceiverBuf : public StaticThread<> {
void run () {
long cnt;
TIME_LOOP(0, 1.1*SECONDS) {
buf.get(cnt);
PRINTF( "ReciverComBuffer - counter1: %ld\n",cnt); }
}
} recbuf;
Compile the tutorial receiver_commbuff.cpp in tutorials/10-first-steps as described in chapter 2 and execute it. Do not forget to compile it with topics.cpp and sender.cpp: $ rodos-executable.sh linux-x86 topics.cpp sender.cpp receiver_commbuff.cpp
To get synchronised data transfer use a SyncFiFo like in tutorial receiver_sync.cpp

### 8.4.3. Putter, program receiver_putter.cpp

Define a new Putter by inheriting from “Putter”:
class JustPrint : public Putter {
bool putGeneric(const long topicId, unsigned int msgLen, ...) { PRINTF("%d %ld %ld\n", msgLen, *(long*)msg, topicId); return true;
}
} justPrint;

static Subscriber nameNotImportant01(counter1, justPrint, "justprint01"); static Subscriber nameNotImportant02(counter2, justPrint, "justprint02");

Compile the tutorial receiver_putter.cpp in tutorials/first-steps as described in chapter 2 and execute it. Do not forget to compile it with topics.cpp and sender.cpp:
$ rodos-executable.sh linux-x86 topics.cpp sender.cpp receiver_putter.cpp
To receive two counters, implement a sender of the second counter.

### 8.4.4. Which subscriber is best for what?

If the receiver needs only the latest data and has to be executed periodically, the CommBuffer solution should be used. For synchronized communication the subscriber put method in combination with resuming a thread is the way to do it. A SyncFiFo is also good for this. To receive from multiple topics with one method a subscriber that filles the CommBuffer with values from topic counter1

the thread gets the latest value

is called every time new data is available on defined topics

subscriber with topic definition – both, counter1 and counter2 will call the putter method of “justprint”

Middleware

17 / 20

Putter should be used.
For more information and tutorials about the middleware check out the folders tutorials/30-communication-and-bbs20-/middleware and tutorials/30-communication/10-alice_bob_charly

## 9. More Middleware

To see a little more about using the middleware and multicasting, please have a look at the example in the directory tutorials/10-first-steps/middleware. Here, we have an example of topics with more than one subscribers and of subscribers of more than one topic. A position sensor measures and publishes data of the position (3D) of a flying object. A speed calculator receives those data and calculates and publishes the object's speed. Finally, a display subscribing both topics, position and speed, and prints the data.
Executeit.sh: | shell script to compile and execute the whole example
topics.h: | interface of the topics
topics.cpp: | definition of the topics position and speed
positionsensor.cpp generates and publishes random postion data
speedcalc.cpp | subscribes position topic and publishes speed data
display.cpp | subscribes position and speed topic and prints the data
Compile all *cpp and see the execution.
Then try to compile without speedcalc.cpp. Do you see the difference?

### 9.1. Programme positionsensor.cpp

class PositionSensor : public StaticThread<> { ...
TIME_LOOP(2*SECONDS, 3*SECONDS) {
p.x+= (randomTT800Positive() % 40)*0.05-1; p.y+= (randomTT800Positive() % 40)*0.05-1; p.z+= (randomTT800Positive() % 40)*0.05-1; position.publish(p);
}

calculate random movement
publish new position in topic „position”

More Middleware

18 / 20

### 9.2. Programme speedcalc.cpp

class SpeedCalc : public Subscriber {
public:
SpeedCalc() : Subscriber(position, "SpeedCalc") { } Pos p0,p1;
long put(...) {
p0=p1;
p1=*(Pos*)data;
double v = sqrt((p0.x-p1.x)*(p0.x-p1.x)+...); speed.publish(v);
return 1;
}
} speedCalc;

### 9.3. Programme display.cpp

static CommBuffer<Pos> posbuf;
static CommBuffer<double> speedbuf;
static Subscriber namenotimportant1(position, posbuf, | "posreceiverbuf");
static Subscriber namenotimportant2(speed, | speedbuf,
"speedreceiverbuf");

class Display : public StaticThread<> {
void run () {
TIME_LOOP(1*SECONDS, 1*SECONDS) { Pos p;
double v;
posbuf.get(p);
speedbuf.get(v);
PRINTF( "Position (%3.2f;%3.2f;%3.2f) speed %3.2f\n",.....); }
}
} display;

subscribe topic position

calculate and publish speed whenever new position data is published

fill buffers with published data

get data from buffers

print data

More Middleware

19 / 20

## 10. Deprecated HelloWorld

The deprecated Thread class is still available. If you have used RODOS before you will find the direct usage of the Thread class (instead of the new StaticThread<>).

This deprecated usage is shown in helloworld-old-fashioned.cpp. You can still build and execute it, but will get a deprecate warning while building the project.

### 10.1. Programme

#include "rodos.h"

class HelloWorld : public Thread {

void run(){
PRINTF("Hello World!\n");
}
} helloworld;

includes the RODOS API

defines a Thread named HelloWorld

implements the code for the main task of the thread
In this case: print “Hello World!” instantiates one thread of type HelloWorld

Summary

20 / 20

## 11. Summary

File name | Content
basic.cpp | A basic ‘Hello World!’ programme
commbuffer.cpp | A simple example for thread communication
event.cpp | A suspended thread is restarted
helloworld-multiple.cpp | Prints several ‘Hello World!’ at once
helloworld-old-fashioned.cpp | Prints ‘Hello World!’. This is deprecated!
helloworld.cpp | Prints ‘Hello World!’
mem-test.cpp | Prints memory location of some variables
priority-ceiling.cpp | 2 threads print at the same time
priority.cpp | 2 threads print at the same time (a bit different)

All other file names should be self explaining

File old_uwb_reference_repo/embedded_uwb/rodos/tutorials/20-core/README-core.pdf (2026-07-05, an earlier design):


## RODOS

## Tutorial REAME Core

Version: | 2.0
Date: | Sept. 2019
Author: | S. Montenegro

## 1. How to begin

First compile the RODOS core. Go to the RODOS root directory and execute: % source setenvs.sh
% rodos-lib.sh linuxMC

Then go to the Tutorials.
use
% rodos-executable.sh linuxMC <list of sources>
to compile and
% tst

Control-C to terminate (Control programmes normally do not terminate... never)

If you want to terminate the execution automatically, add the programm terminate-test.cpp
to you source code list then it will be terminated after 20 seconds.
eg.
% rodos-executable.sh linuxMC timewaitfor.cpp terminate-test.cpp

to execute – e.g.
% rodos-executable.sh linuxMC timewaitfor.cpp
% tst

Or to combine two applications:
% rodos-executable.sh linuxMC timewaitfor.cpp timewaitbeats.cpp % tst

README-core.odt
How to begin

2 / 8

For each example programme please first read and understand the code, then compile and execute and see if it acts as expected. Then modify and continue trying. Try to combine different programs together.

## Useful to know:

Time unit = nanoseconds, stored in 64 bits (int64_t).
Threads implement co-operative switch (yield) and pre-emption.
Priorities begin with 1 (lowest) up to 2^31, stored in long.
Compile and execute the following programmes. Be aware of the prints before your application begins. You will see there the configuration of the system and the list of loaded modules. Then take a look to the sources and try to modify them to add more functionality.

We have very few macros and only for operations which are used very often. We recommend to use such macros: (to find examples use for example %grep PROTECT_WITH *)

How to begin

3 / 8

NOW() | Returns the current time (nanoseconds counter)
AT(time) | Because very often we have to wait a time point, AT is a short cut for suspendCallerUntil(time)
TIME_LOOP(firstExecution, Period) { … } | Almost each control loop has a start time and a period. This macro provides this loop with no end.
PROTECT_WITH_SEMAPHORE(semaphore) { … } | Critical blocks which shall be protected by semaphores, have almost always such structure. This macro uses the given semaphore to protect the region in { … }
PRIORITY_CEILING { … } | To deactivate scheduling for a very short time to protect very short critical section.

## 2. Programmes

### 2.1. Threads and Time

timewaitfor.cpp

This is a thread which waits for a time point. It loops and waits 2 seconds in each loop.
Check to see if the time difference of each execution is more than 2 seconds, because of the time consumed in the thread execution.
% rodos-executable.sh linuxMC timewaitfor.cpp

timewaitbeats.cpp
Periodic threads. It loops and prints in beats of 2 seconds. The beat shall have a minimal delay and no shifts as in timewaitfor.cpp

Programmes

4 / 8

% rodos-executable.sh linuxMC timewaitbeats.cpp Now try to combine both together
% rodos-executable.sh linuxMC timewaitbeats.cpp timewaitfor.cpp

Observe the time shift.
For exact beats use waitUntilNextBeat().

timewaitbeats_shortcut.cpp

A shortcut for timebeats using macros.
Compare with timewaitbeats
% rodos-executable.sh linuxMC timewaitbeats.cpp

timeevents.cpp:

Reaction to pre-defined time points without using threads. Instead it uses event handlers.
The event handler can react to internal events, interrupts and time events.
% rodos-executable.sh linuxMC timeevents.cpp
Combine it with other threads
% rodos-executable.sh linuxMC timewaitfor.cpp timeevents.cpp

timeevent_resumer01.cpp & timeevent_resumer02.cpp

timeevent_resumer.cpp shows how a time event resumes a waiting thread. This other thread waits in a time-loop. Despite extra resumes, the beat does not get lost.

utctest.cpp

Shows how to use UTC time (time 0 is 1th of jan 2000 at 0:00) and calendar time. (Calendar time is useless for internal computations but nice to communicate with people)

Programmes

5 / 8

timepoints.cpp

Used to manage a (small) log file of time points and print them. Usable for debug and time tuning.

### 2.2. Priorities

preemptiontest.cpp
Two threads, one with a high priority which is executed very shortly every 3 seconds and one with a low priority which is executed constantly. The high priority thread (printing “*”) shall assume the CPU when it needs it even if the low priority thread (Printing “.”) does not suspend or yield.

See the application definition, which now uses an application ID (2000) to use the application discovery protocol with other applications (see ceiler).
% rodos-executable.sh linuxMC preemptiontest.cpp
% tst

ceiler.cpp
This is a demonstrator of priority ceiling to keep the CPU for a critical block. It will search for pre-emption application (using the application ID 2000). If not found it reports a warning.
Try:
% rodos-executable.sh linuxMC ceiler.cpp
% tst
% rodos-executable.sh linuxMC preemptiontest.cpp ceiler.cpp
% tst
% rodos-executable.sh linuxMC preemptiontest.cpp timeevents.cpp
% tst

Even if ceiler has a low priority it keeps the CPU when it is inside of the critical block in PRIORITY_CEILING ( ... ). It will not be interrupted by other threads when it is inside of this block.

Programmes

6 / 8

But time events and other events can not be blocked. They always run.

### 2.3. Local Communication

Local communication uses shared memory. To provide consistency in a concurrent system some means of synchronisation has to be used or else objects which can guarantee concurrent access without blocking threads. These objects are the means of communication between eventhandlers, and between eventhandlers and threads, because there we cannot suspend events.

commbufftest.cpp
Is a double buffer with only one writer and only one reader. Both can work concurrently.
The writer may write at any time. The reader gets the newest consistent data (eg. The last complete written record)

commbufftest-struct.cpp
Like commbufftest.cpp, but using more complex structures than just integers.

fifotest.cpp

For synchronous communication from one single writer to one single reader. Neither will be suspended. Writing to a full FiFo has no effect and returns 0. Reading from an empty FiFo returns 0.

### 2.4. Thread synchronisation

Thread synchronisation deals with suspending and resuming threads to synchronise their activities. To avoid concurrent access of critical sections semaphores must be used. To synchronise threads on data transfer use SyncFiFos.

syncfifotest.cpp
A sender and a receiver which wait until data is ready.

Programmes

7 / 8

semaphoretest.cpp
Many threads try to access a protected area. Only one is allowed to enter at a time.

semaphore_worm.cpp
A (semi) graphical demonstration of semaphores. Several threads move with random speeds each a letter in a screen area (30x30 Characters). The right part of the screen is protected by a semaphore. Only one thread may move its letter in the right part, all other which want to enter have to wait until the one which occupies the semaphores exits the protected area.
Note: The terminal size has to be at least 30x30 characters (check the lower limit).

### 2.5. Events/Interrupts

With events you may react to interrupts like timers and signals from devices. You may need this when programming I/O drivers.
resumefromevent.cpp
A thread can be suspended and will wait until another thread that knows him resumes him. For example an event handler.
Following examples for interrupts: See tutorials/70-network-and-io/30-interrupts

externalevents01.cpp

It reacts to external interrupts. In the Linux simulation we have only one external interrupt and it is simulated by the Linux command “kill” or “killall”. Using kill we can generate an signal number 15 (Linux stuff).
Use two Linux windows. In one compile and execute externalevents01.cpp. Execute tst. In the other window call
% killall tst

externalevents02.cpp
Like externalevents01.cpp, but it uses the default event::handle, which searches for a thread waiting for this signal and resumes it.

### 2.6. Test programmes

yieldtime.cpp
Example how to use co-operative threads. It measure the time for thread switches in

Programmes

8 / 8

nanoseconds.
% rodos-executable.sh linuxMC yieldtime.cpp Now add some more threads and see the difference
% rodos-executable.sh linuxMC yieldtime.cpp yieldtime_extra.cpp
or try just
% rodos-executable.sh linuxMC yieldtime_extra.cpp

## 3. Summary

File name | Content
ceiler.cpp | Use with preemptiontest.cpp, thread communication
gets-async-minimal.cpp | Receives data from interrupt
gets-async.cpp | Receives data
getsnowiat.cpp | Also receives data
helloworld-minimalistic.cpp | Prints ‘Hello World!’
preemption* | Several examples about pre-emption
resumefromevent.cpp | Thread gets resumed after short time
resumer.cpp | Similar to above
timeevent-resumer* | Thread gets resumed after some time

All other file names should be self explaining.

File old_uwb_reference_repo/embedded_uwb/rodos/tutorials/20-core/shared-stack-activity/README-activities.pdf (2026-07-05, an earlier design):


## RODOS

## RODOS activity tutorial

Version: | 2.0
Date: | Sept. 2019
Author: | S. Montenegro

If your application would require may threads and you are working with small micro controller, which have very limited memory, then it could be difficult to allocate a stack for each thread. In this case and if your threads could work sequentially, then you can use instead of thread something like the activities defined and implemented in this tutorial. Activities are time triggered like normals threads, but they will be called sequentially using a single common stack for all of them, which is located in the activity-scheduler which is a real RODOS thread. Activities are just like function calls. Each activity shall implement a step() method which will be called by the activity scheduler according to the (from user) requested timings. The step() method has to return before another activity may take control. All activities are managed in a static linked list (like threads). The constructor of the activities will register each of them in the activity linked list. So the user does not needs to register them any where. The activity scheduler will go trough this list, and compare the next execution time of each activity with the current time. If the time to be executed has arrived then the scheduler will call the step method of the corresponding activity.
This is very efficient and consumes very little memory, but it has following main drawbacks:
1. No Pre-emption. The step method of any activity has to return before the next activity may be executed. Therefore do not use things like suspendCallerUntil(). There are alternative constructs like YIELD_UNTIL(time) which may be used instead.
2. You may not use semaphores. Because all activities are executed by a single thread (the activity scheduler) a semaphore would block all activities and not just the calling one. The lack of semaphores is not a big problem, because if all activities are executed sequentially and we have no pre-emption, then we do not need to protect common objects (between activities). If really required we could implement an activity semaphore which is based on the activity YIELD.
3. You may not keep values/variables on the stack. Because the stack will be shared among all activities, after you return from step, other activity will overwrite you stack (that is normal by function calls). Use a Context object instead to store your data.

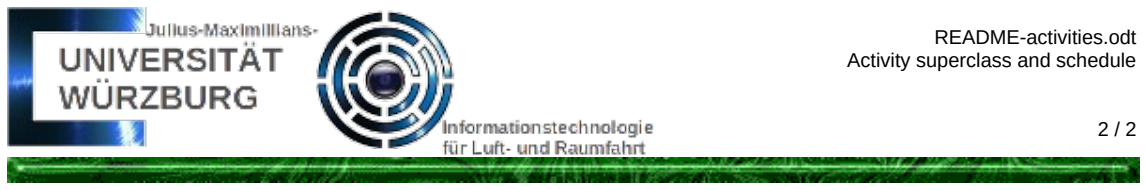
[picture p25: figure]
README-activities.odt Activity superclass and schedule

## 1. Activity superclass and schedule

activity.h is the superclass for your activities.
To be able to return from anywhere form your step() method and continue from the same place (like if it were a thread) we define C-macros YIELD and YIELD_UNTIL, which were inspired by the protothreads from:
http://dunkels.com/adam/pt/

"Protothreads are extremely lightweight stackless threads designed for severely memory constrained systems, such as small embedded systems or wireless sensor network nodes. Protothreads provide linear code execution for event-driven systems implemented in C/C++. Protothreads can be used with or without an underlying operating system to provide blocking event-handlers. Protothreads provide sequential flow of control without complex state machines or full multi-threading."

Both C-macros YIELD and YIELD_UNTIL store the line number where they are called and then return. The macro GOTO_LAST_YIELD will jump to the place where we were before the last return (YIELD)
activity.cpp contains the activity scheduler and executer. It goes though the activities list and calls the step() method of all due activities. If the time for an activity has arrive and it has defined a period (a cycle time) then the scheduler will compute and update the next time to execute the activity. This is done before the step method is called, because the step could set by its own another execution time. This is the case for example when using YIELD_UNTIL(time).

## 2. Examples

example-simple.cpp is the most simple implementation of two independent activities. In the initiator they define their timing properties. The step() method will be called respectively. step() has to run without interruption until its end. Only after step() concludes (or returns) the next activity may be called.
example-with-yield.cpp is a little more complex using constructs like YIELD and YIELD_UNTIL. The step() method will be interrupted before it reaches its end by calling YIELD or YIELD_UNTIL(time). Then the step() method will be called again at the corresponding time and continue from the place where it called YIELD. It works because YIELD hides a return. YIELD protocols the line where it was called and returns. By the next call we reach the statement GOTO_LAST_YIELD which jumps to the line stored by YIELD. It uses a C switch construct. Inside of step() we can even create an infinity loop (while(1)), if it contains YIELD or YIELD_UNTIL.

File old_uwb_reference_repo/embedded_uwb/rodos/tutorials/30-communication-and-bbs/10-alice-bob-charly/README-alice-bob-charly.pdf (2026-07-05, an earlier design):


## RODOS

## RODOS tutorial ABC (Alice Bob Charly)

Version: | 1.0
Date: | 10.10.2009
Author: Sergio Montenegro

This tutorial shows how to build bigger systems using very simple components (building blocks).

## 1. How to begin

Read and understand first the RODOS-Tutorial and then the RODOS-Middleware tutorial. Use
% rodos-executable.sh linuxMC <list of sources>
to compile and
% tst
to execute – e.g.
% rodos-executable.sh linuxMC alice-bob-charly.cpp
% tst
For each example programme please first read and understand the code, then compile and execute and see if it acts as expected. Then modify and continue trying.

## 2. Useful to know

The middleware communication is based on a publisher/subscriber protocol. This is a multicast protocol. There is no connection from a sender to a receiver (connectionless). Publishers make messages public under a given topic.
Subscribers to a given topic get all messages which are published under the given topic. To establish a transfer path, both the publisher and subscriber have to share the same topic.

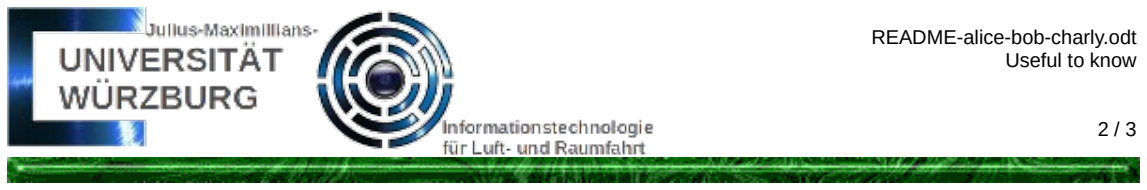
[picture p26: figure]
README-alice-bob-charly.odt Useful to know

A Topic is a pair - data-type and an integer representing a topic identifier.
To match a communication pair, both data-type and topic identifier must match. For a topic there may be zero, one or several subscribers. A message which is published under a topic will be distributed to 0 or more subscribers.
Each subscriber has a reference to the associated topic and a “putter” to store messages. Or in this more simple example threads may be waiting for messages. If a message is published while a thread is waiting for it, the thread will get a copy of the message else not.
All subscribers are registered in a list. Each time a message is published the list of all subscribers will be searched and for each subscriber where the topic matches the associated putter will be called to store a copy of the published message.
Using a network interface and the corresponding gateways, the middleware may make the node borders transparent. Applications running on different computers may communicate as if they were on the same computer (not in this example).

## 3. Examples

alice_bob_charly.cpp : This is a short demonstration of threads communicating by publishing messages and threads waiting for them. To see more elaborated publisher/Subscriber communication please refer to tutorial_middleware.

% rodos-executable.sh linuxMC alice-bob-charly.cpp % tst

Alice, Bob and Charly share communication topics:

Bob publishes a message after 2 seconds (see #define VALENTINE_DAY 2*SECONDS, line 13) and Alice waits for it.
After Bob publishes the message (line 41), Alice can receive the message (line 54) she is waiting for.
Charly only receives the second message (sent in line 45) as Charly is only a

Figure 1: Example topic with a struct

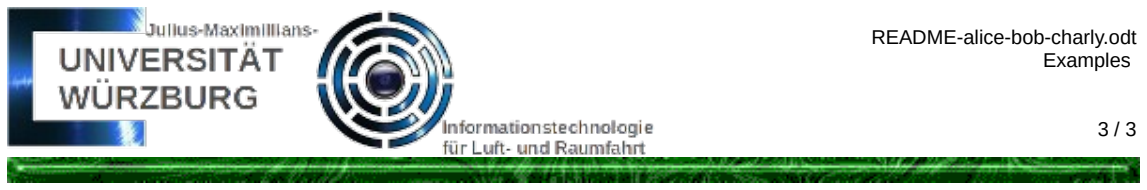
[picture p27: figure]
README-alice-bob-charly.odt Examples

TopicFilter and not a subscriber. Charly only receives messages after set as a TopicFilter for valentine in line 44.
A topic may not have more than one filter. After the message is published, the prolog (line 20) is called, then all subscribers (here only Alice), then the epilog (line 24).

Figure 2: Sequence of events after a Topic is published

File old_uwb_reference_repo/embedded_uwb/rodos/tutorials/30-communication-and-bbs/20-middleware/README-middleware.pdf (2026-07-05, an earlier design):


## RODOS

## RODOS Middleware

Version: | 2.0
Date: | Sept. 2019
Author: | S. Montenegro
1. How to begin.

Read and understand first the RODOS-Tutorial and then the RODOS-Middleware tutorial.

use
% rodos-executable.sh linuxMC <list of sources>
to compile and
% tst

to execute – e.g.
% rodos-executable.sh linuxMC sender01.cpp
% tst

For each example program please first read and understand the code, then compile and execute and see if it acts as expected. Then modify and continue trying.
Try to combine different programmes together.

## 2. Useful to know:

For output in masks we use the support/support_programms/maskgenerator. Please first take a look to mask.txt, you will find the same macro names [NAME ] in all programs.

README-middleware.odt
Useful to know:

2 / 4

The middleware communication is based on a publisher/subscriber protocol. This is a multicast protocol. There is no connection from a sender to a receiver (connectionless).
Publishers make messages public under a given topic.
Subscribers to a given topic get all messages which are published under the given topic.
To establish a transfer path, both the publisher and subscriber have to share the same topic.
A Topic is a pair - data-type and an integer representing a topic identifier.
To match a communication pair, both data-type and topic identifier must match. For a topic there may be zero, one or several subscribers. A message which is published under a topic will be distributed to 0 or more subscribers.
Each subscriber has a reference to the associated topic and a “putter” to store messages.
All subscribers are registered in a list. Each time a message is published the list of all subscribers will be searched and for each subscriber where the topic matches the associated putter will be called to store a copy of the published message.
Using a network interface and the corresponding gateways, the middleware may make the node borders transparent. Applications running on different computers may communicate as if they were on the same computer.

## 3. Stabilising common topics

demo_topics.h declares all topics and data structures used for communication for the tutorial. These topics and data structures shall be known by all communicating applications.
Therefore it has to be declared globally and all applications must include this file.

demo_topics.cpp allocates all topics. For each topic declaration the corresponding (exactly one) object has to be created. There may not be replications of topic objects.
Try to replicate topic objects or topic identifiers. You shall get an error message.

First try to compile the topics:
% rodos-executable.sh linuxMC demo_topics.cpp
% tst

This programme does nothing, but you can get error messages if you replicate

Stabilising common topics

3 / 4

topics.
Publisher / Sender

There are some examples of senders:
sender01.cpp is a simple publisher with a thread to send simple messages. sender02.cpp-antiexample.cpp is a publisher which sends simple messages from an event handler. No thread is needed.
senderPosition.cpp sends more complex messages using an extra data structure. You may compile one or more of them together. Each compilation has to have the demo_topics.cpp

% rodos-executable.sh linuxMC demo_topics.cpp sender01.cpp % tst

% rodos-executable.sh linuxMC demo_topics.cpp sender02.cpp-antiexample.cpp
% tst

% rodos-executable.sh linuxMC demo_topics.cpp sender02.cc-antiexample.cpp sender01.cpp
% tst

% rodos-executable.sh linuxMC demo_topics.cpp sender02.cc senderPosition.cc
% tst

% rodos-executable.sh linuxMC demo_topics.cpp sender*.cpp % tst

Compile and execute different combinations. You will see the reports of each sender each time it publishes in a topic. There is no subscriber, therefore no message will be received.

## Subscribers/Receivers

There are several examples of subscribers. You may compile one or more together, but as for the publisher, each compilation has to have the demo_topics.cpp. receiverthread.cpp is the most simple receiver, a thread waits on a topic until

Stabilising common topics

4 / 4

something arrives. But his method can loose messages if the thread is not waiting when the message arrives.
receiverputter.cpp is subscriber which creates an own putter to handle messages to topics conunter1 and counter2. You man try to add or remove topics. No Thread is required to access the messages.
receivercommbuf.cpp has a CommBuffer as a putter, to store the last published message. It provides a thread which look periodic to the buffer.
receiverasync.cpp has a asynchronous FiFo to store the messages. It provides a Thread which look periodic to the FiFo.
receiversync.cpp has a synchronous FiFo to store the messages. It provides a thread which is activated each time some one (a publisher) has written data to the FiFo (as a putter).

Try to compile one or more of them together. There is no publisher, therefore no subscriber will get data.

% rodos-executable.sh linuxMC demo_topics.cpp receiverputter.cpp
% tst

% rodos-executable.sh linuxMC demo_topics.cpp receiver*.cpp
% tst

## Publishing and receiving

Now we may combine publishers and receivers.
See which publisher publishes which topic and see which subscriber receives which topic.
Try different combinations or all senders and all receivers.
Eg:
% rodos-executable.sh linuxMC demo_topics.cpp receiverputter.cpp sender01.cpp
% tst

or
% rodos-executable.sh linuxMC *.cpp % tst

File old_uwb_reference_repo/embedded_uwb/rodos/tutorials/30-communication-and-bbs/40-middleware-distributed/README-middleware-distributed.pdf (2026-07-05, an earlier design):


## RODOS

## RODOS tutorial Middleware Distributed

Version: | 2.0
Date: | Sept. 2019
Author: | S. Montenegro

From the middleware tutorial you have learned the procedures of how to communicate using the middleware. The communication described in that tutorial is only for local applications - all communicating units were running in the same node of the computer and in the same memory space.
The same programs – without modification – can be distributed to different computers and to different memory spaces. Each compilation only has to add a gateway.

## 1. How to use

Start several xterm (or other terminals like Konsole) windows.
In one window (at least 80x40 chars) start the network (or the network_silent) found in the directory support_programs.
You may try to read and understand the network implementation. It is not required for the tutorial as it is not as simple as the tutorial programs.
Keep the network running.

You may start with the already well-known application from tutorial_middleware. See the gateway.cpp. It just created an object called gateWayUdp.
You may copy it to tutorial_middleware.
Compile in one window all senders + demo_topic.cpp + gateway.cpp and start it.
In another window compile all receivers + demo_topic.cpp + gateway.cpp and start it. The receivers shall get the messages from the senders, even if they are different Linux processes. At the network window you can view the message transfer activities.

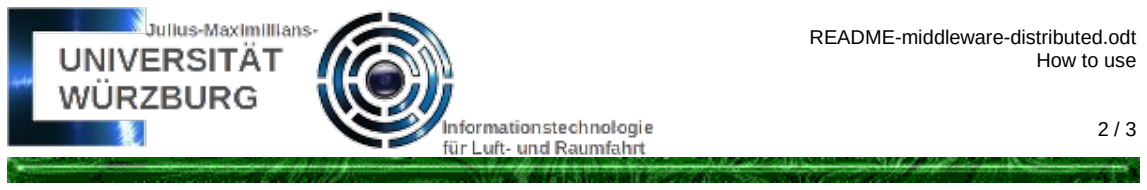
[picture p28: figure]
README-middleware-distributed.odt How to use

You may start several senders and receivers in different windows. All of them shall communicate using the network simulator. Try to terminate some applications (using control-C) and after 2 or 3 seconds the network shall recognize the (simulated) “failure” and remove the corresponding node from the list.

You may start more than one network simulator at a time. One will work and the other will wait until the running network terminates (using control-C). Then another network will take control and the communicating nodes will continue their operation (fault tolerant).

## 2. Programmes

See mask.txt and support_programs/maskgenerator.
In this directory you will find:
a topic definition, for 6 very similar topics (demo_topic.h & demo_topic.cpp) 6 senders (sender11.cc to sender 16.cpp)
6 receivers (receiver11.cc to receiver16.cpp)
mask.tst -> maks.h
All senders and receivers are very similar, they just use different topics, print on different positions on the screen and have different timing. The rest is practically the same.

There may be different gateways to different networks. But in this case we have only one gateway. It uses udp messages to communicate with the network simulator.

Sender11 corresponds to receiver11 and both use topicId 11.
It is the same for sender12 through 16 and the corresponding receivers and topics. In every compilation you have to include the demo_topics.cc.

First try one sender and one receiver in the same window:

% rodos-executable.sh linuxMC sender11.cpp receiver11.cpp demo_topics.cpp % tst

See how the receiver gets the messages from the sender and prints them,

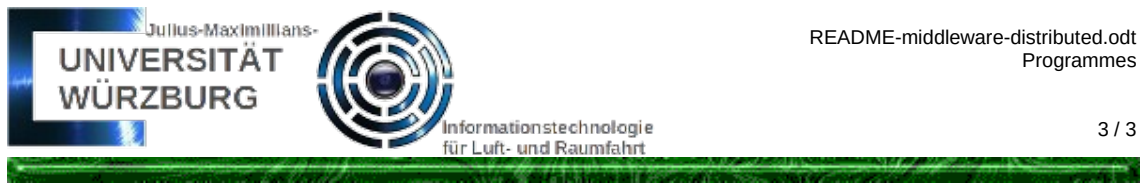
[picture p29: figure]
README-middleware-distributed.odt Programmes

now do the same in two different windows and a gateway (do not forget, the network shall be running in other window).
To execute it distributed on different Windows (Linux processes) please see the shell script
% executeit.sh

The receiver in Window B shall get the messages from the sender in window A.

Now try different senders and receivers in many different windows.
Combine different senders and receivers in the same window.
Stop and restart different windows.
Do not forget: After each compilation tst will be overwritten. Compile and execute for each combination.

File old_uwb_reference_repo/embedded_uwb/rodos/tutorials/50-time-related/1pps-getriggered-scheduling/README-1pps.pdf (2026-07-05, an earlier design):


## RODOS

## 1PPS triggered scheduling

Version: | 2.0
Date: | Sept. 2019
Author: | S. Montenegro

In may distributed systems, like for example in satellite applications, we have the situation where software modules running on different hardware units have to work synchronized. A very often solution is to have an global and external beat signal which comes very precisely once per seconds, the so called One Pulse Per Second (1PPS). Very often comes this 1PPS from the GPS receiver, which have a very accurate time notion.
In RODOS Threads and all kind of time events are synchronized and scheduled using a node internal clock. This method will not work globally if we have several nodes each having its own clock (the clocks will drift very fast).
In this tutorial we show a scheduler which is triggered by an external 1PPS. We define a class Activity1PPS. Instances of this class shall be activated relatively to the external 1PPS and not to the internal clock. Each Activity1PPS defines an offset and a frequency. The frequency says how often the activity shall be executed in each seconds. Other in other words: How often this activity shall be executed after each 1PPS.
The offset (in nanoseconds) says how long to wait to execute the activity for the first time after each 1PPS.
Restrictions:
Activities1PPS shall be executed at least once per second. Frequency >= 1
The offset has to be less than 1*SECOND/frequency

The scheduler will then trigger all activities which are registered in the activity list, like the normal RODOS scheduler does with all threads registered in the Thread List.
The first execution will be after “offset” nanoseconds after each 1PPS.
Subsequent executions will be separated by 1*SECOND/frequency.
No activity will be activated after one second after the last 1PPS.
If no 1PPS arrives, no activity will be executed.

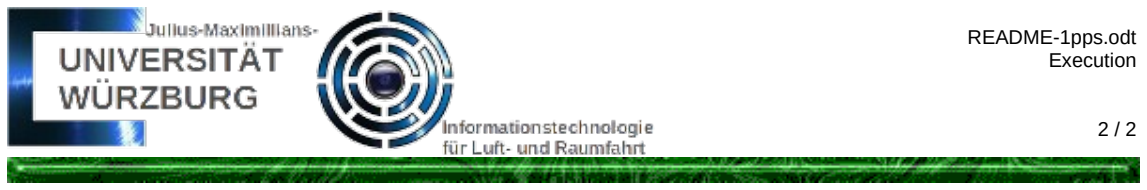
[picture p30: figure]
README-1pps.odt Execution

## 1. Execution

In this example we generate the 1PPs using the Linux signals and the RODOS interrupt distribution.
RODOS distributes “termInterrupts” which can be generated using the kill shell command, (eg “killall tst”) using the topic interruptSigterm.
Our scheduler subscribes interruptSigterm and uses them to trigger the activities. The example-activities1pps.cpp are some very simple examples how to implement activities1PPS.
Use the shell scripts to compile and execute the files.
Execute the RODOS program by calling
% tst
On other terminal generate the 1PPS signals using
% killall tst
Or to generate it periodically use the delivered shell script
% generate-1pps.sh

Please note: The generated 1PPS signals take a little longer than 1 second. So you will notice a time drift. The script “generate-1pps.sh” aims to be simple and not to be accurate.

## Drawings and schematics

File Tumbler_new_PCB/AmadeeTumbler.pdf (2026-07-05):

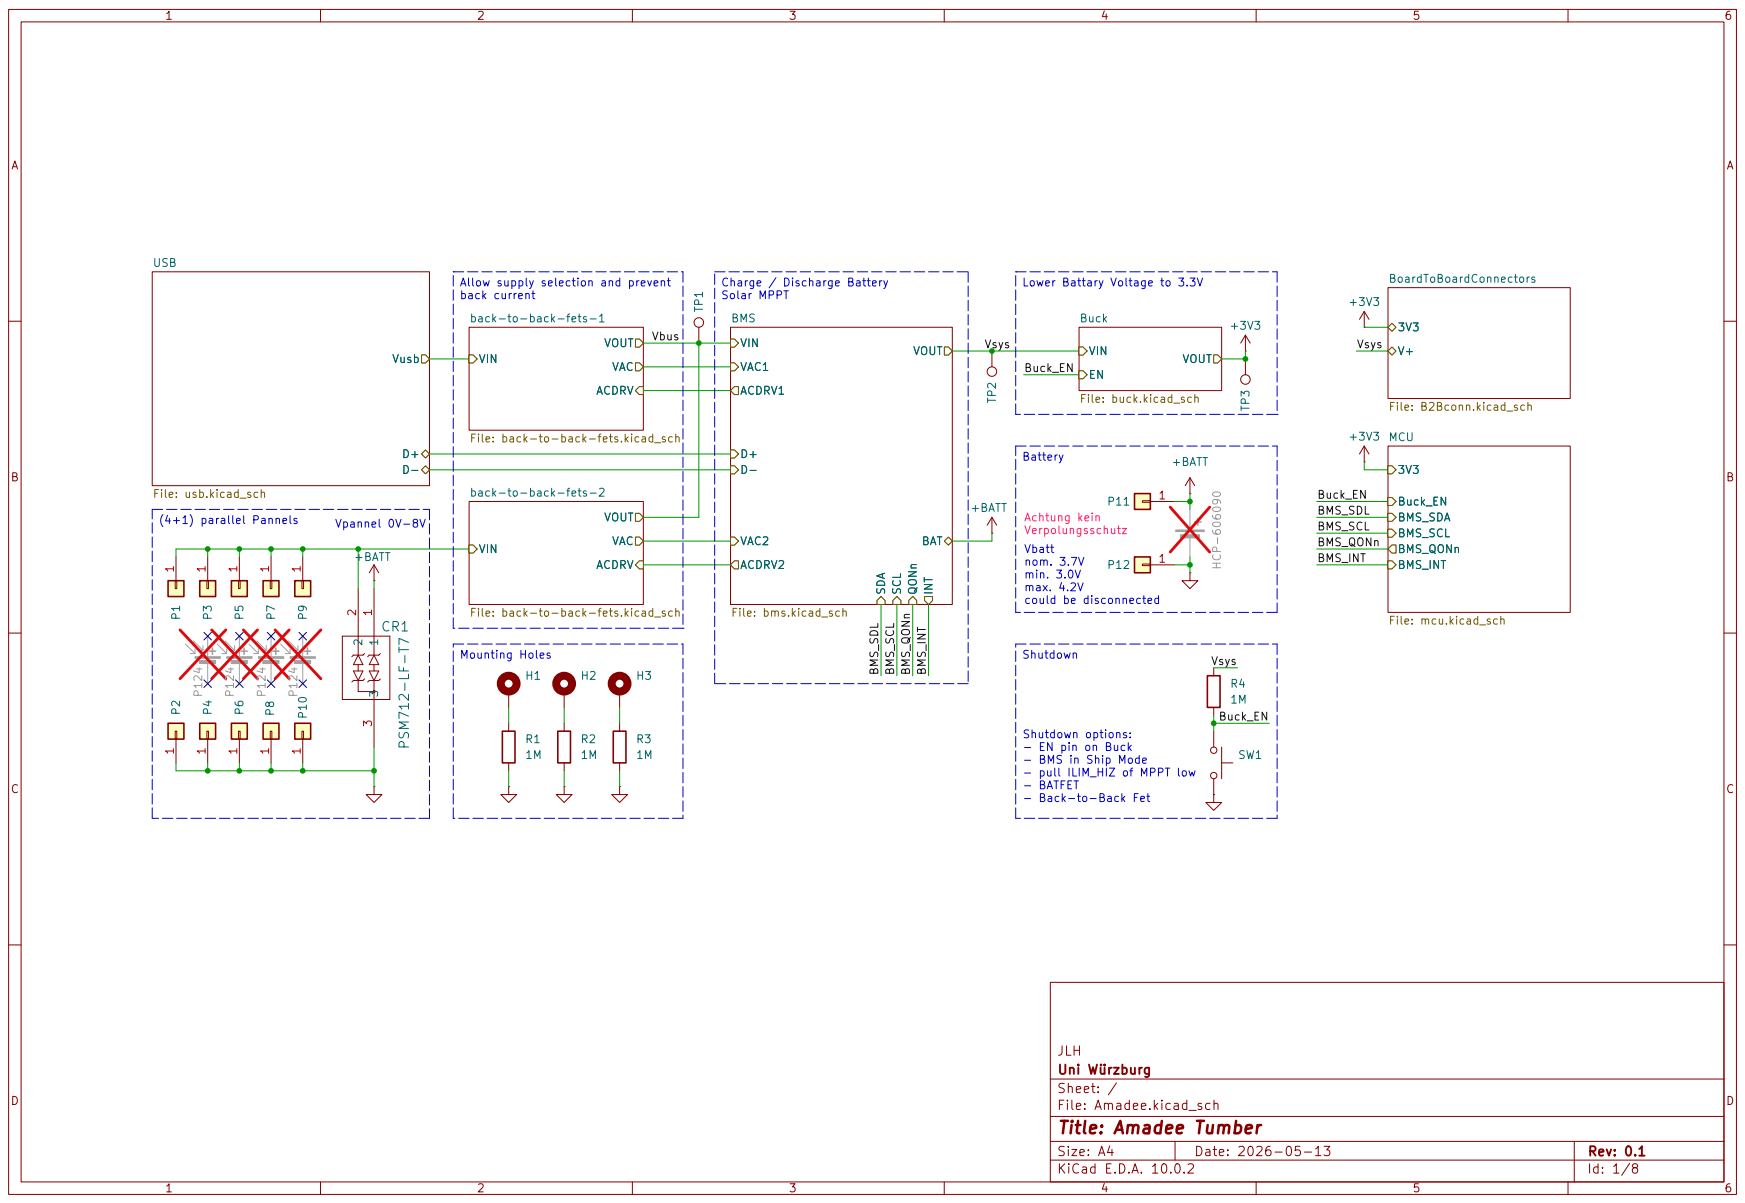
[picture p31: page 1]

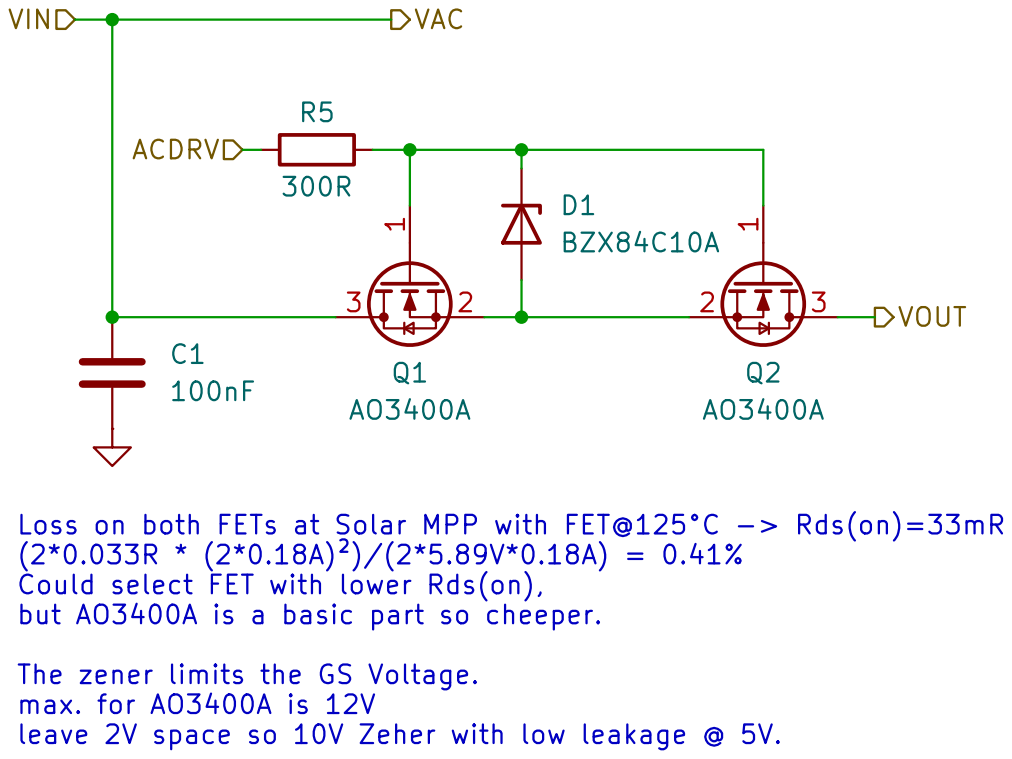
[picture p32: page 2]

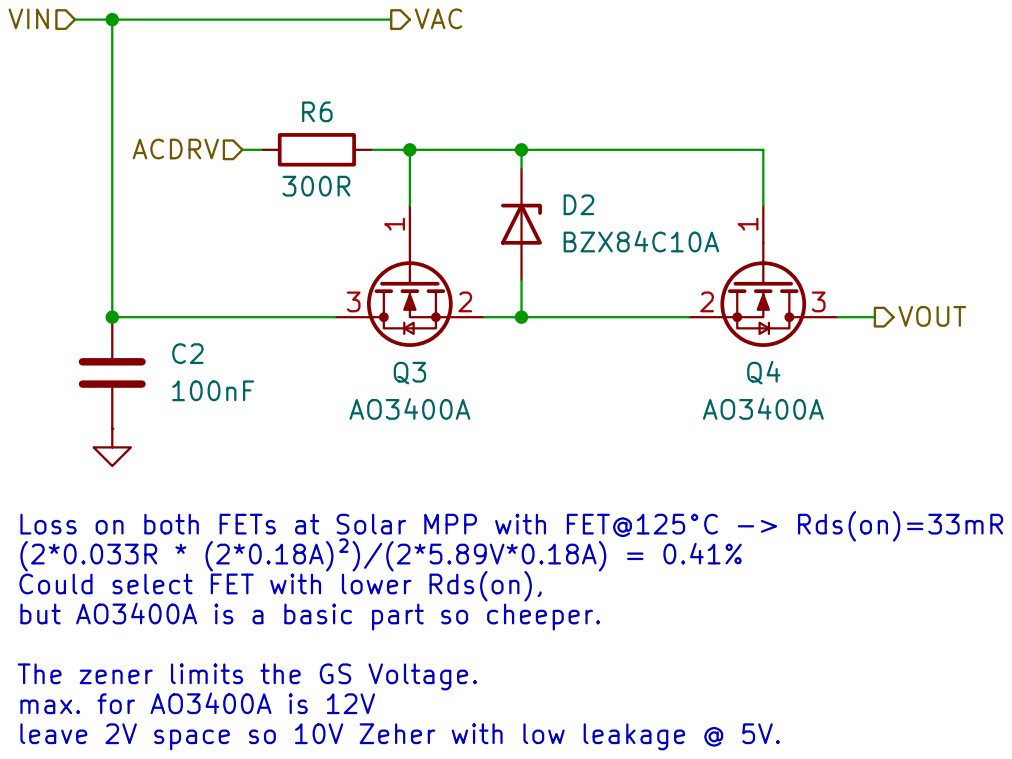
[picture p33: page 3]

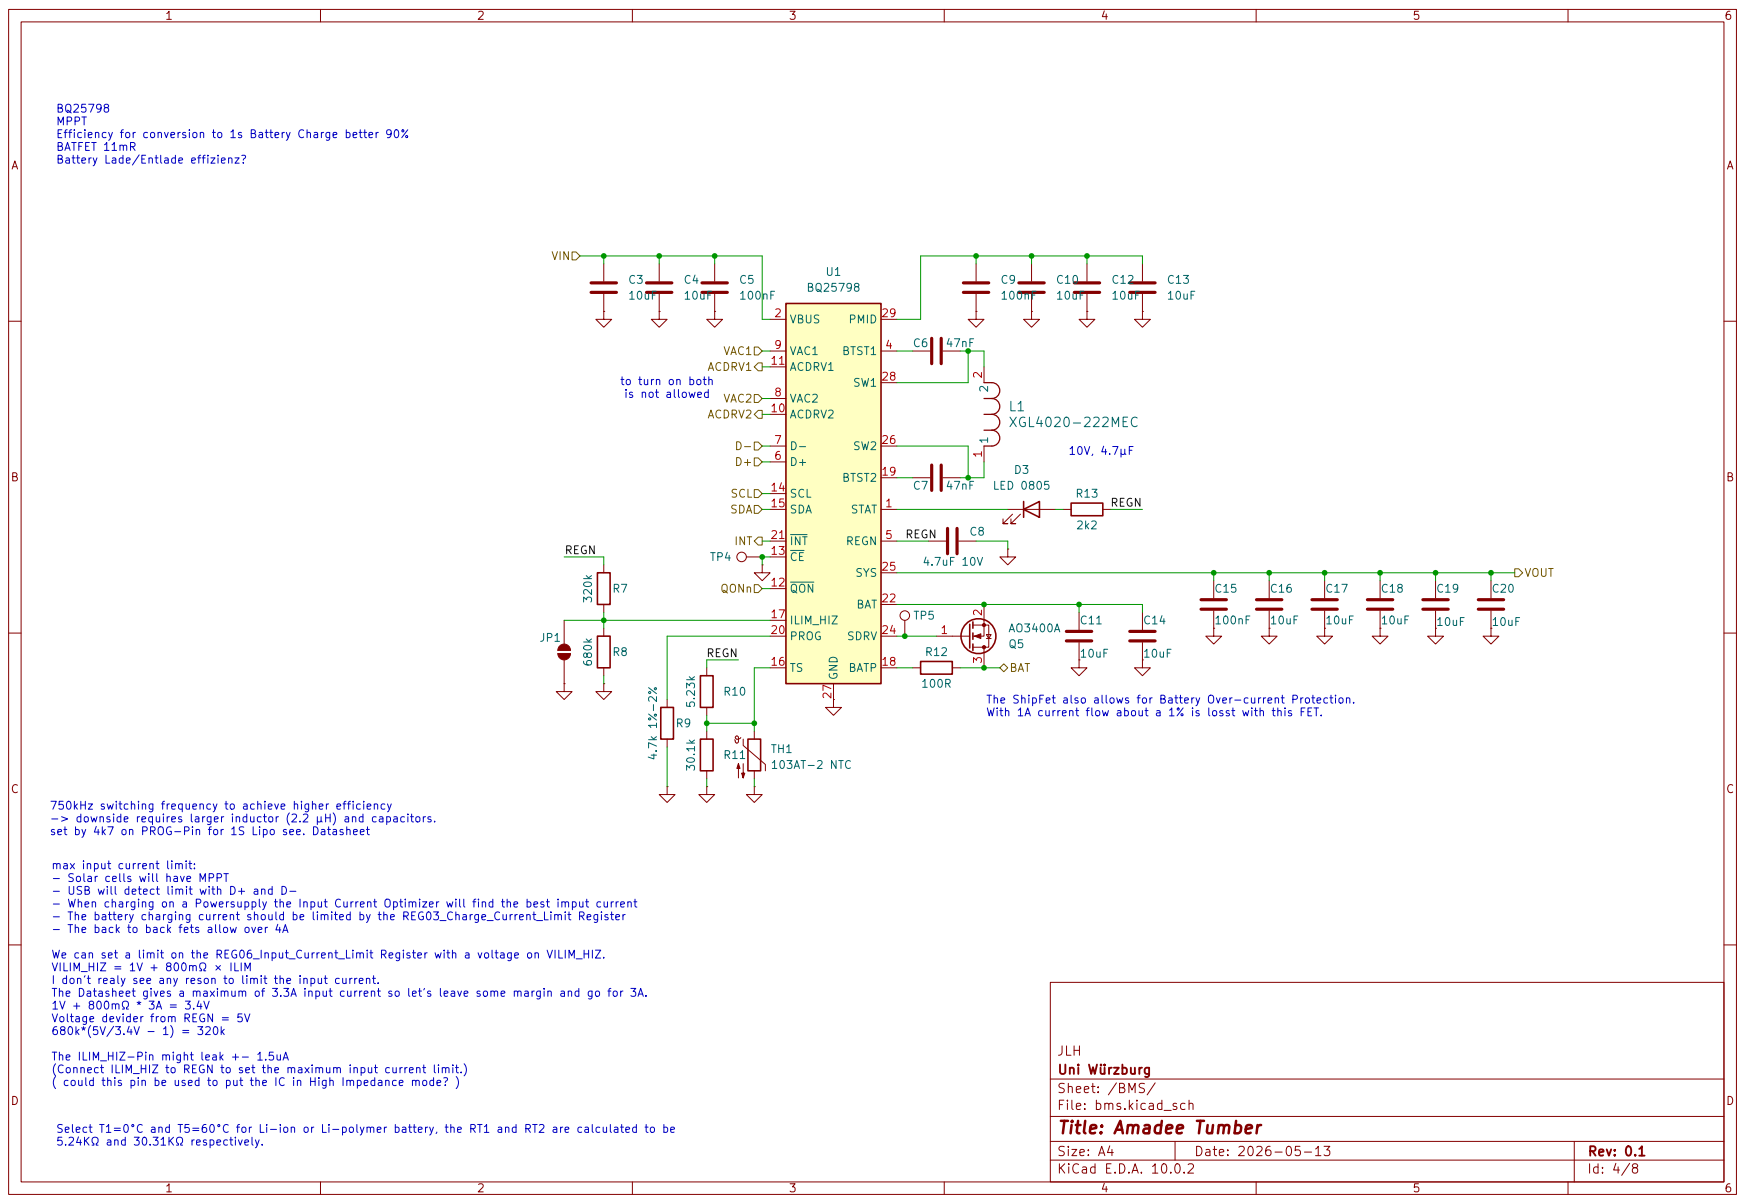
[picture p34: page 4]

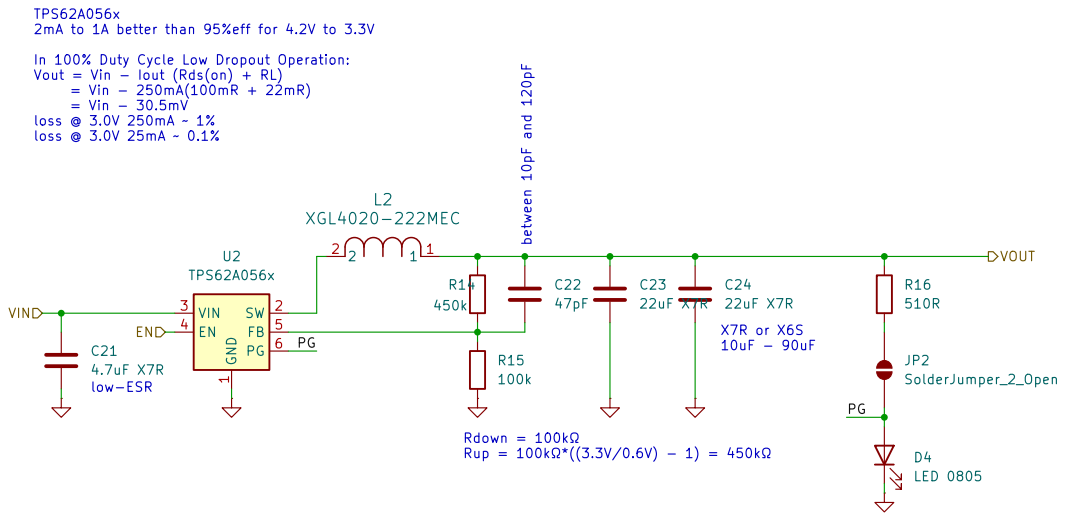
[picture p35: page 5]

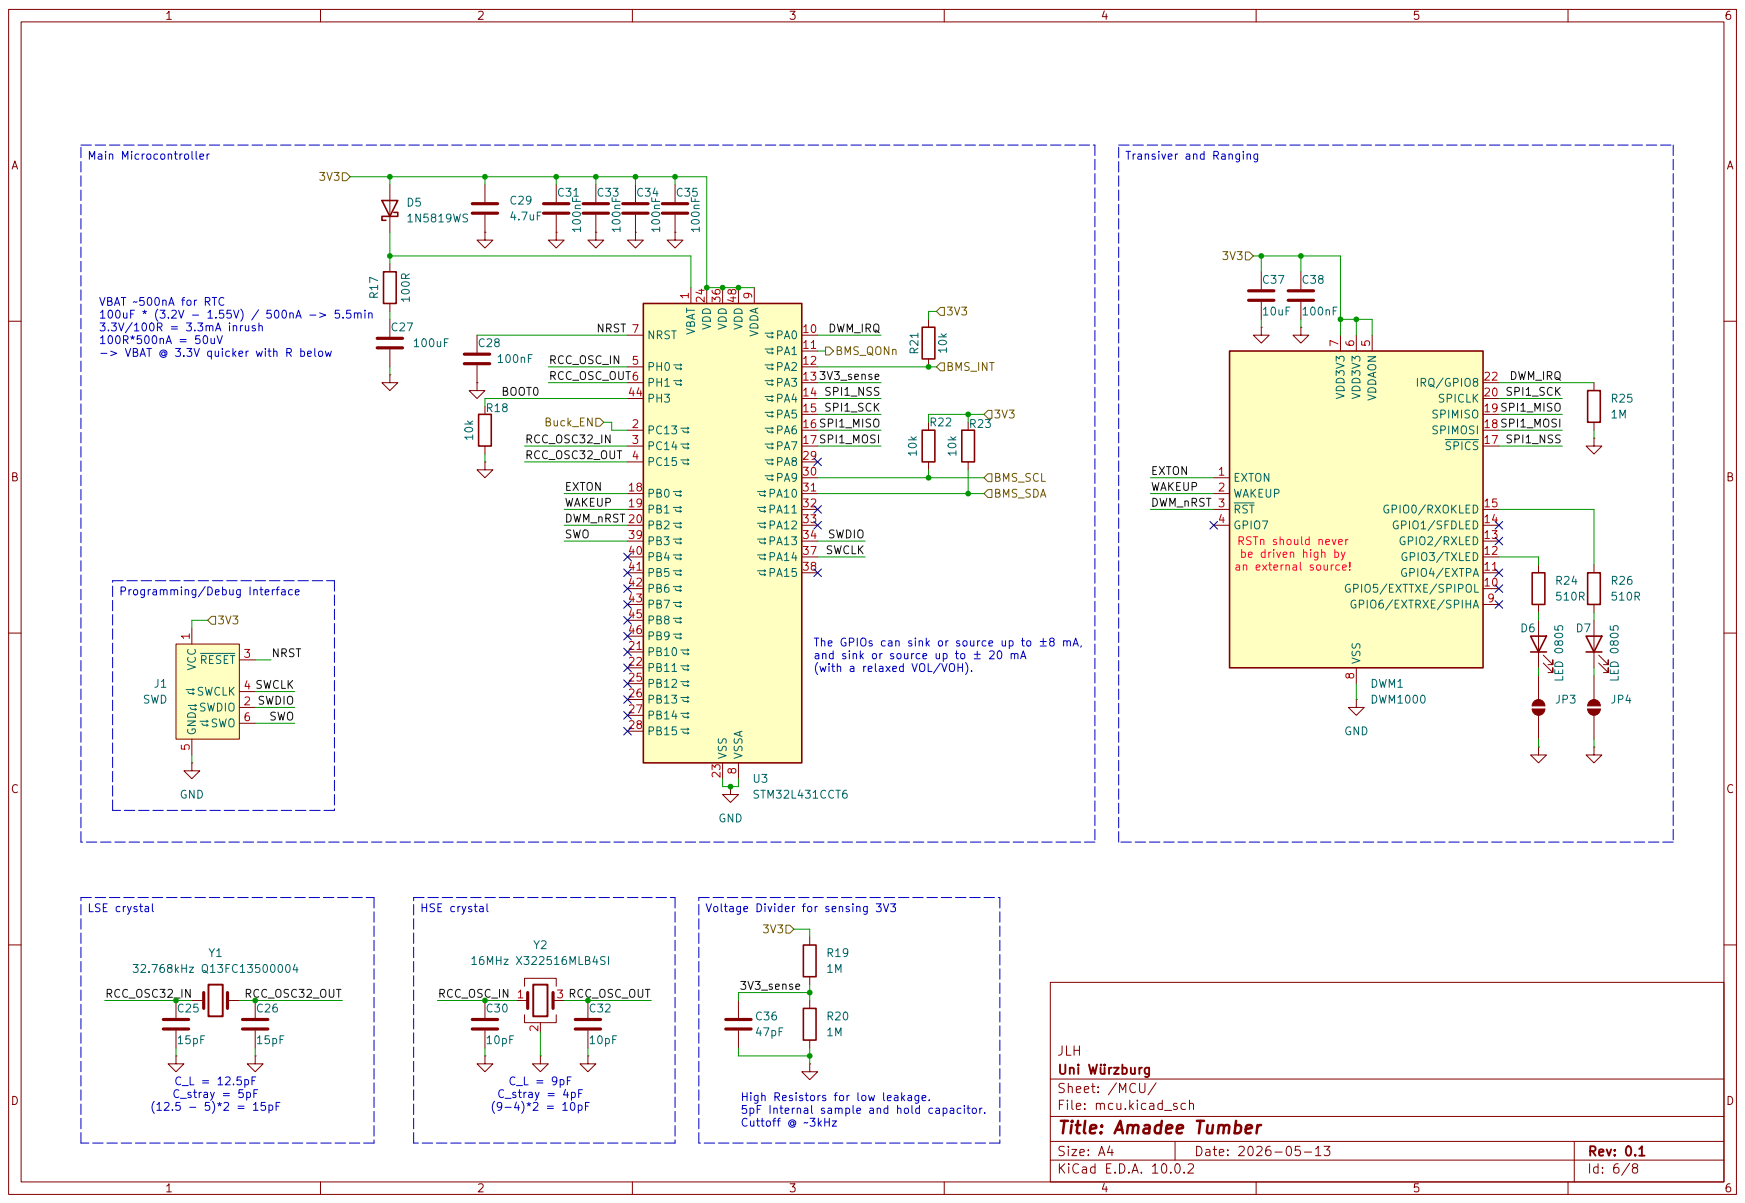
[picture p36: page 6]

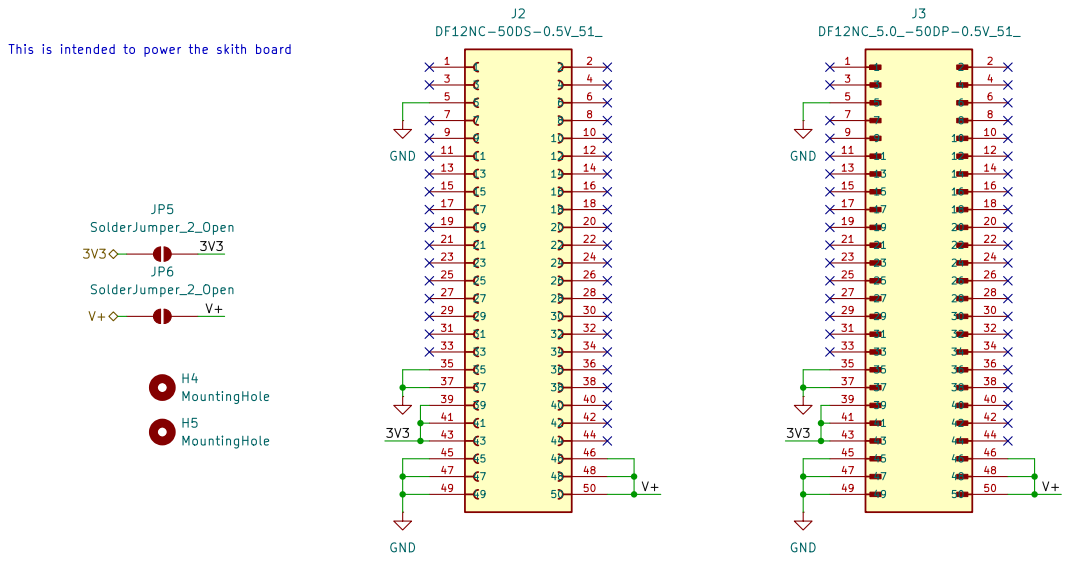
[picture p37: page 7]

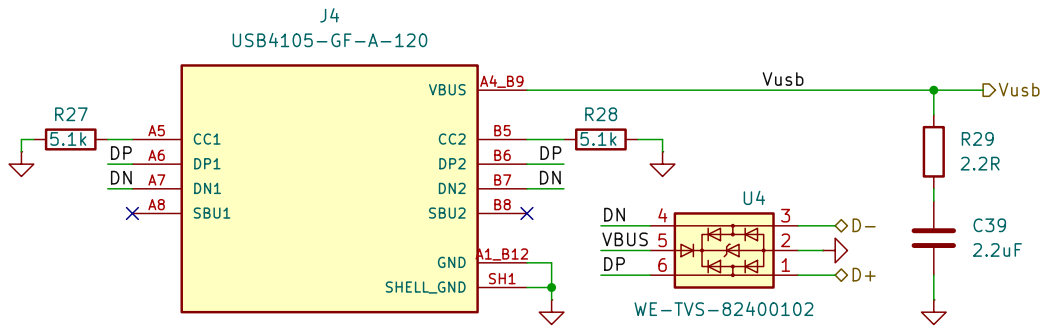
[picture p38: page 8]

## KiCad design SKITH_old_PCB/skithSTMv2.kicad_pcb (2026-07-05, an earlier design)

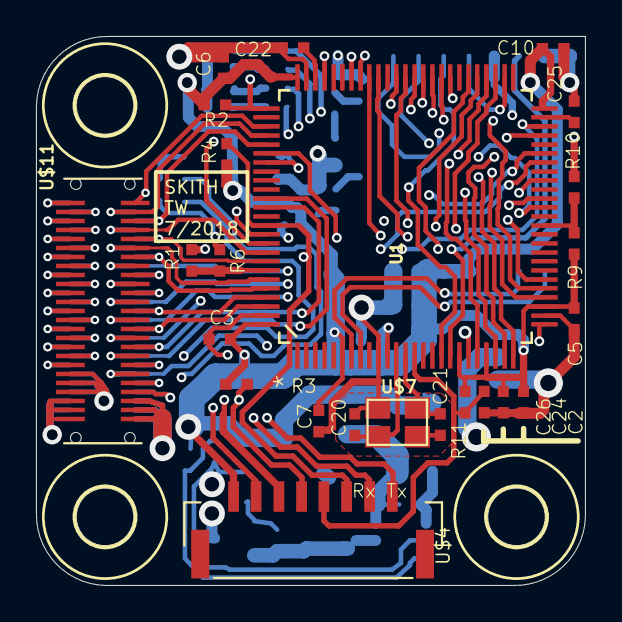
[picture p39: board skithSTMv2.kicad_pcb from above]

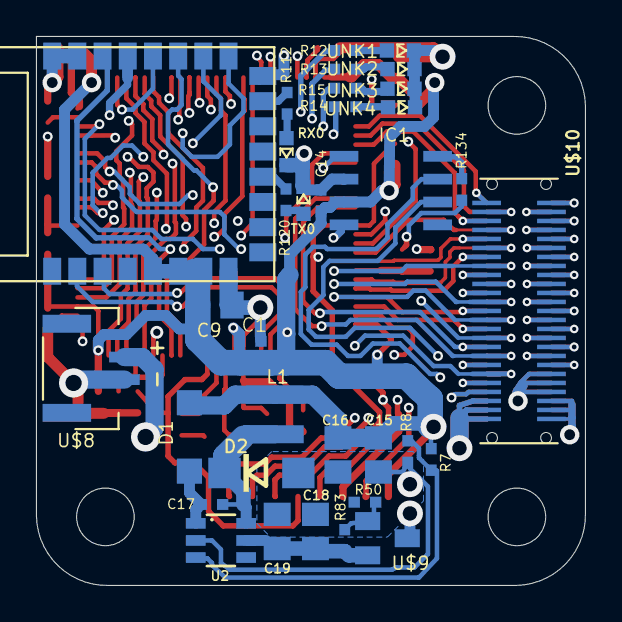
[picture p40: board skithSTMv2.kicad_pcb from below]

Board: 4 copper layers, 30.5 x 30.5 mm, 61 parts (34 on the bottom side), 79 nets.

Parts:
C1, C2, C3, C5, C6, C7, C10, C14, C17, C24, C26: 100n; C0402
C9, C15, C16, C18, C19: 10µ; C0805
C20, C21: 22p; C0402
C22, C25: 2,2µ; C0402
D1: 1N4148W-7-F; SOD123
D2: DO214AC
IC1: SN65HVD231D; SO8
L1: WE-TPC_2828
R1, R2, R3, R4, R6, R8, R9, R10, R11: 10k; R0402
R7: 31,6K; R0402
R12, R13, R14, R15, R112, R120, R134: 270; R0402
R50, R83: 1Meg; R0402
RX0: grün; SML0603
TX0: rot; SML0603
U1: STM32F407VGT6; QFP50P1600X1600X160-100N
U2: MCP16331; SOT23-6
U$1, U$5, U$6: 3,2
U$3: DWM1000
U$4: SM08B-GHS-TB
U$7: QC3CA16.0000F12B23M; LFXTAL055998
U$8: SM02B-GHS-TB
U$9: SI2369DS-T1-GE3; SOT23
U$10: DF12A-50DS-0.5V
U$11: DF12D(5.0)-50DP-0.5V
UNK1: grün; SML0603
UNK2: gelb; SML0603
UNK3: rot; SML0603
UNK4: blau; SML0603

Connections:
+3V3: C1.1, C2.1, C3.1, C5.1, C6.1, C7.1, C9.1, C10.1, C14.2, C15.1, C16.1, C24.1, D1.A, IC1.3, L1.2, R1.2, R2.2, R3.2, R4.1, R7.2, R9.2, R11.2, U1.6, U1.11, U1.19, U1.22, U1.28, U1.50, U1.75, U1.100, U$3.5, U$3.6, U$3.7, U$4.1, U$10.20, U$10.21, U$10.22, U$11.20, U$11.21, U$11.22
+24V: C18.1, C19.1, R83.2, U2.5, U$9.2
AD0: U1.23, U$10.8, U$11.8
AD1: U1.24, U$10.7, U$11.7
AD2: U1.25, U$10.6, U$11.6
AD3: U1.26, U$10.5, U$11.5
AD4: U1.29, U$10.4, U$11.4
AD5: U1.30, U$10.1, U$11.1
AD_REF: U1.21, U$10.2, U$11.2
BOOT1: R9.1, R10.2, U1.37
CAN1_RX: IC1.4, U1.81
CAN1_TX: IC1.1, U1.82
CAN_H: IC1.7, U$10.15, U$11.15
CAN_L: IC1.6, U$10.16, U$11.16
DEBUG_UART_RX: U1.69, U$4.7
DEBUG_UART_TX: U1.68, U$4.8
GND: C1.2, C2.2, C3.2, C5.2, C6.2, C7.2, C9.2, C10.2, C14.1, C15.2, C16.2, C18.2, C19.2, C20.2, C21.2, C22.2, C24.2, C25.2, C26.1, D2.A, IC1.2, R6.1, R8.1, R10.1, R50.1, R134.2, RX0.C, TX0.C, U1.10, U1.20, U1.27, U1.74, U1.99, U2.2, U$3.8, U$3.16, U$3.21, U$3.23, U$3.24, U$4.3, U$7.2, U$7.4, U$8.2, U$10.3, U$10.18, U$10.19, U$10.23, U$10.24, U$10.25, U$11.3, U$11.18, U$11.19, U$11.23, U$11.24, U$11.25, UNK1.C, UNK2.C, UNK3.C, UNK4.C
I2C_SCL: U1.47, U$10.17, U$11.17
I2C_SDA: U1.48, U$10.35, U$11.35
JTCK: R2.1, U1.76, U$4.2
JTMS: R3.1, U1.72, U$4.4
LED_BLAU: R12.2, U1.62
LED_GELB: R15.2, U1.60
LED_GRUEN: R14.2, U1.59
LED_ROT: R13.2, U1.61
unnamed: C22.1, U1.73
unnamed: R112.2, U$3.15
unnamed: R7.1, R8.2, U2.3
unnamed: C17.1, D1.C, U2.1
unnamed: C17.2, D2.C, L1.1, U2.6
unnamed: R12.1, UNK1.A
unnamed: R13.1, UNK2.A
unnamed: R14.1, UNK4.A
unnamed: R1.1, R6.2, U1.94
unnamed: R15.1, UNK3.A
unnamed: C25.1, U1.49
unnamed: IC1.8, R134.1
unnamed: R112.1, RX0.A
unnamed: R120.1, TX0.A
unnamed: R120.2, U$3.12
unnamed: R50.2, R83.1, U$9.1
NRST: C26.2, R11.1, U1.14, U$4.5
P0: U1.78, U$10.50, U$11.50
P1: U1.79, U$10.49, U$11.49
P2: U1.80, U$10.48, U$11.48
P3: U1.92, U$10.47, U$11.47
P4: U1.93, U$10.46, U$11.46
P5: U1.95, U$10.45, U$11.45
P6: U1.96, U$10.44, U$11.44
P7: U1.67, U$10.43, U$11.43
P8: U1.63, U$10.37, U$11.37
P9: U1.98, U$10.36, U$11.36
PH0: C20.1, U1.12, U$7.1
PH1: C21.1, U1.13, U$7.3
PWM0: U1.40, U$10.40, U$11.40
PWM1: U1.42, U$10.41, U$11.41
PWM2: U1.44, U$10.39, U$11.39
PWM3: U1.45, U$10.42, U$11.42
SPI0_CS0: U1.31, U$10.13, U$11.13
SPI0_CS1: U1.66, U$10.14, U$11.14
SPI0_CS2: U1.64, U$10.9, U$11.9
SPI0_CS3: U1.97, U$10.38, U$11.38
SPI0_MISO: U1.90, U$10.10, U$11.10
SPI0_MOSI: U1.91, U$10.11, U$11.11
SPI0_SCK/SWO: R4.2, U1.89, U$4.6, U$10.12, U$11.12
SPI_CS_DWM1000: U1.39, U$3.17
SPI_MISO_DWM1000: U1.17, U$3.19
SPI_MOSI_DWM1000: U1.54, U$3.18
SPI_SCK_DWM1000: U1.52, U$3.20
UART0_RX: U1.87, U$10.34, U$11.34
UART0_TX: U1.86, U$10.33, U$11.33
UART1_CTS: U1.58, U$10.29, U$11.29
UART1_RTS: U1.53, U$10.30, U$11.30
UART1_RX: U1.56, U$10.32, U$11.32
UART1_TX: U1.55, U$10.31, U$11.31
UWB_INT: U1.18, U$3.22
UWB_RESET: U1.7, U$3.3
UWB_WAKEUP: U1.8, U$3.2
V+: U$8.1, U$9.3, U$10.26, U$10.27, U$10.28, U$11.26, U$11.27, U$11.28

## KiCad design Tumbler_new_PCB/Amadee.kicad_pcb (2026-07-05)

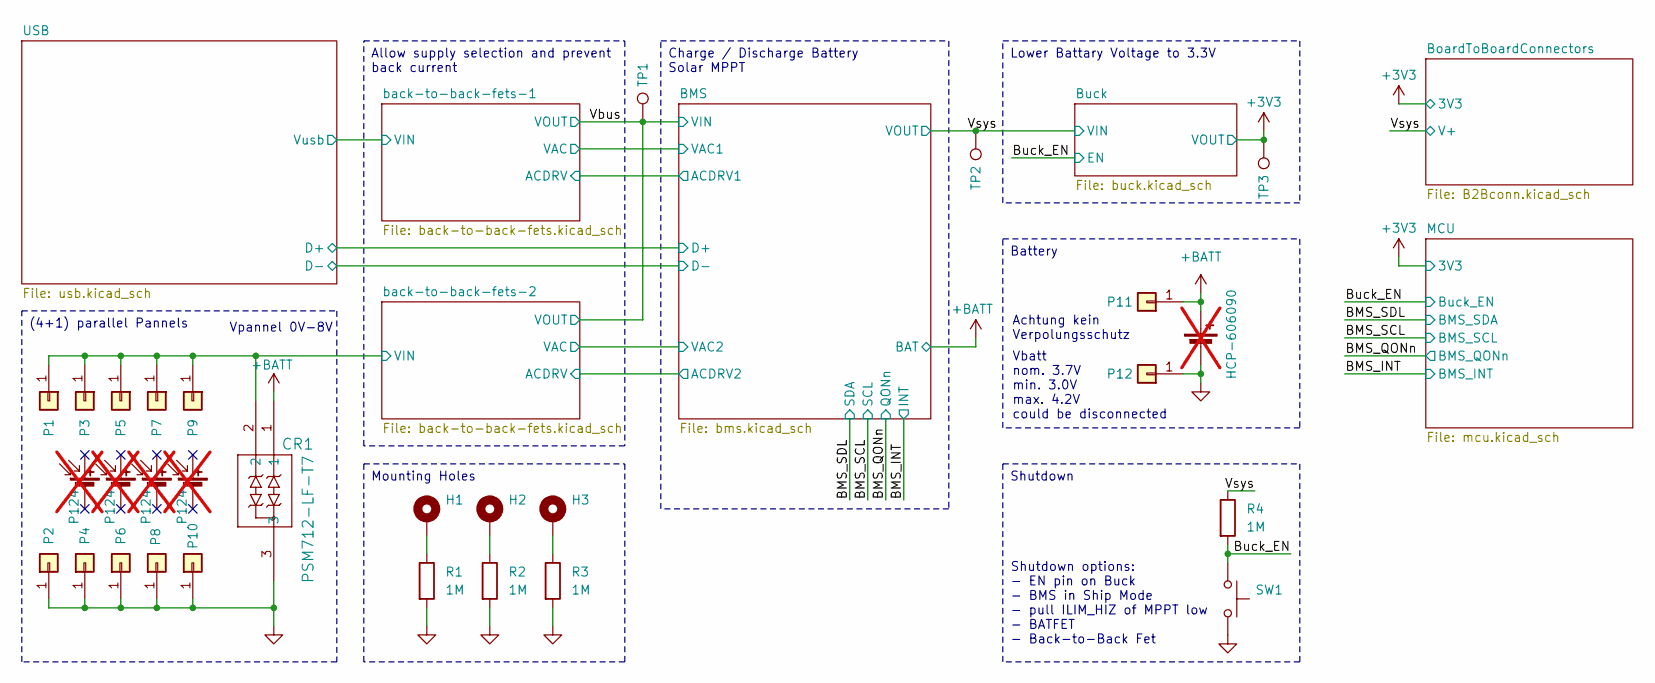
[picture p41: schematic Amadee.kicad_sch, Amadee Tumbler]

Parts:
BT1: HCP-606090; not fitted
CR1: PSM712-LF-T7; CR_SOT-23_PTD; LCSC C32677
H1, H2, H3: MountingHole_Pad; MountingHole_3.2mm_M3_DIN965_Pad
P1, P2, P3, P4, P5, P6, P7, P8, P9, P10, P11, P12: SolderPad_4mm_2mm
R1, R2, R3: 1M; R_0603_1608Metric_Pad0.98x0.95mm_HandSolder
R4: 1M; R_0402_1005Metric_Pad0.72x0.64mm_HandSolder
SC1, SC2, SC3, SC4: P124; not fitted
SW1: SW_Push; SW_SPST_TS-1088-xR020; LCSC C720477
TP1, TP2, TP3: TestPoint; TestPoint_Pad_D1.5mm

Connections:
+3V3: TP3.1 (1_1); also elsewhere on the board
+BATT: BT1.1 (+), CR1.1, P11.1 (Pin_1_1); also elsewhere on the board
/BMS/VAC2: CR1.2, P1.1 (Pin_1_1), P3.1 (Pin_1_1), P5.1 (Pin_1_1), P7.1 (Pin_1_1), P9.1 (Pin_1_1); also elsewhere on the board
/Buck_EN: R4.2, SW1.1; also elsewhere on the board
/Vbus: TP1.1 (1_1); also elsewhere on the board
/Vsys: R4.1, TP2.1 (1_1); also elsewhere on the board
GND: BT1.2 (-), CR1.3, P2.1 (Pin_1_1), P4.1 (Pin_1_1), P6.1 (Pin_1_1), P8.1 (Pin_1_1), P10.1 (Pin_1_1), P12.1 (Pin_1_1), R1.2, R2.2, R3.2, SW1.2; also elsewhere on the board
unnamed: H1.1 (1_1), R1.1
unnamed: H2.1 (1_1), R2.1
unnamed: H3.1 (1_1), R3.1

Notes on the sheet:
Vpannel 0V-8V
Vbatt nom. 3.7V min. 3.0V max. 4.2V could be disconnected
Shutdown options: - EN pin on Buck - BMS in Ship Mode - pull ILIM_HIZ of MPPT low - BATFET - Back-to-Back Fet
Achtung kein Verpolungsschutz
Battery
Lower Battary Voltage to 3.3V
Charge / Discharge Battery Solar MPPT
Shutdown
Allow supply selection and prevent back current
(4+1) parallel Pannels
Mounting Holes

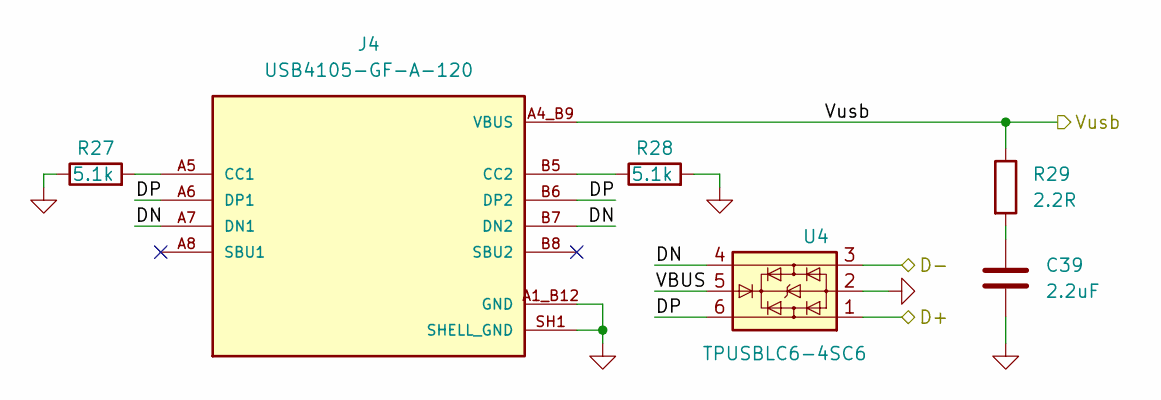
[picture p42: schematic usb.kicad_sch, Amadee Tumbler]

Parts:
C39: 2.2uF; C_0805_2012Metric_Pad1.18x1.45mm_HandSolder
J4: USB4105-GF-A-120; GCT_USB4105-GF-A-120; PARTREV B3; LCSC C5184243
R27, R28: 5.1k; R_0603_1608Metric_Pad0.98x0.95mm_HandSolder
R29: 2.2R; R_0603_1608Metric_Pad0.98x0.95mm_HandSolder
U4: TPUSBLC6-4SC6; SOT-23-6; LCSC C558419

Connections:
/BMS/D+: U4.1; also elsewhere on the board
/BMS/D-: U4.3; also elsewhere on the board
/USB/DN: J4.A7 (DN1), J4.B7 (DN2), U4.4
/USB/DP: J4.A6 (DP1), J4.B6 (DP2), U4.6
GND: C39.2, J4.A1_B12 (GND), J4.B1_A12 (GND), J4.SH1 (SHELL_GND), J4.SH2 (SHELL_GND), J4.SH3 (SHELL_GND), J4.SH4 (SHELL_GND), R27.1, R28.2, U4.2; also elsewhere on the board
unnamed: C39.1, R29.2
unnamed: J4.A5 (CC1), R27.2
unnamed: J4.B5 (CC2), R28.1
VBUS: J4.A4_B9 (VBUS), J4.B4_A9 (VBUS), R29.1, U4.5; also elsewhere on the board

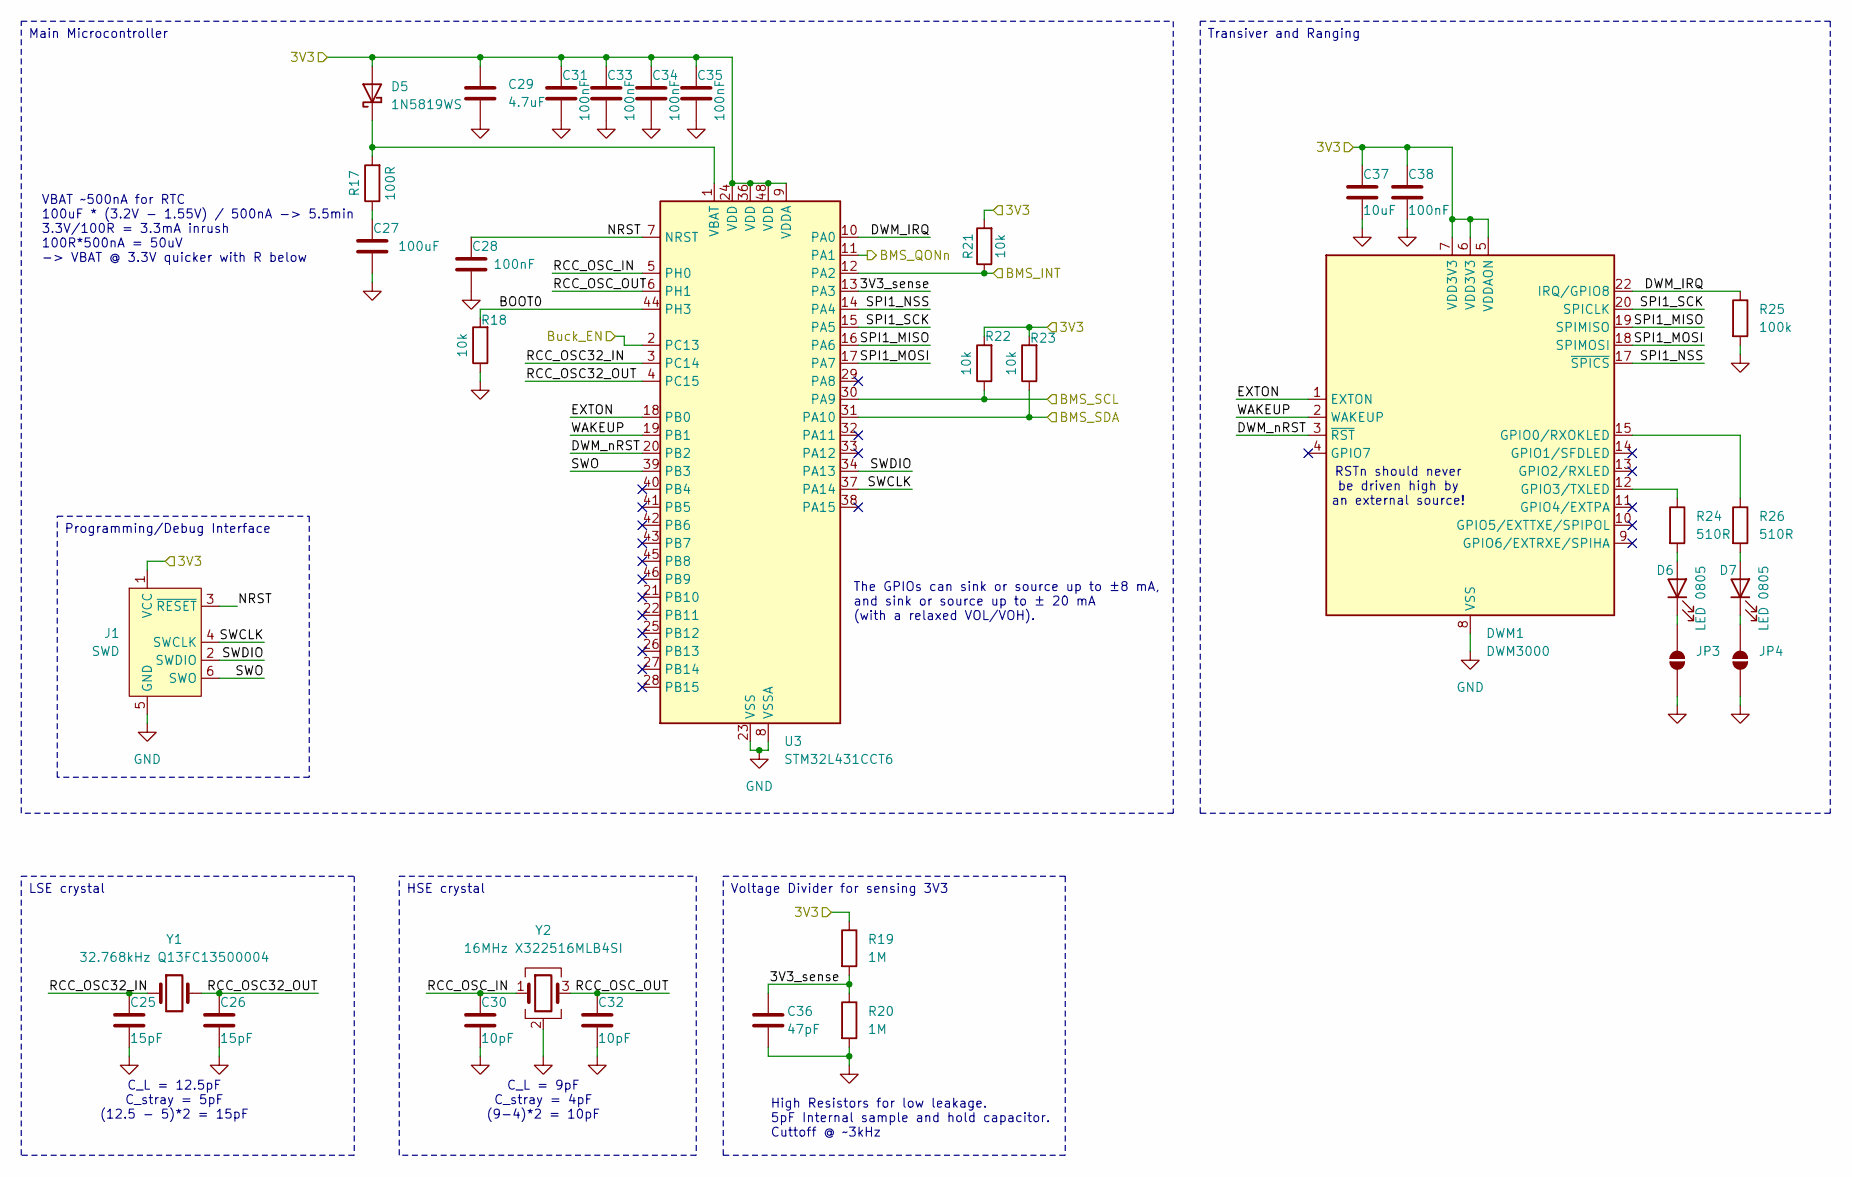
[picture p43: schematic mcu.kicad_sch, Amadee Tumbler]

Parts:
C25, C26: 15pF; C_0402_1005Metric
C27: 100uF; C_1206_3216Metric
C28, C31, C33, C34, C35, C38: 100nF; C_0402_1005Metric_Pad0.74x0.62mm_HandSolder
C29: 4.7uF; C_0805_2012Metric_Pad1.18x1.45mm_HandSolder
C30, C32: 10pF; C_0402_1005Metric
C36: 47pF; C_0402_1005Metric_Pad0.74x0.62mm_HandSolder
C37: 10uF; C_0402_1005Metric_Pad0.74x0.62mm_HandSolder
D5: 1N5819WS; D_SOD-323
D6, D7: LED 0805; LED_0805_2012Metric_Pad1.15x1.40mm_HandSolder; LCSC C2296
DWM1: DWM3000; DWM1000; LCSC C42419011
J1: SWD; PinHeader_2x03_P2.54mm_Vertical_SMD; LCSC C192301
JP3, JP4: SolderJumper_2_Open; SolderJumper-2_P1.3mm_Open_RoundedPad1.0x1.5mm
R17: 100R; R_0402_1005Metric_Pad0.72x0.64mm_HandSolder
R18, R21, R22, R23: 10k; R_0402_1005Metric_Pad0.72x0.64mm_HandSolder
R19, R20: 1M; R_0402_1005Metric_Pad0.72x0.64mm_HandSolder
R24, R26: 510R; R_0402_1005Metric_Pad0.72x0.64mm_HandSolder
R25: 100k; R_0402_1005Metric_Pad0.72x0.64mm_HandSolder
U3: STM32L431CCT6; LQFP-48_7x7mm_P0.5mm; LCSC C486681
Y1: 32.768kHz Q13FC13500004; Crystal_SMD_3215-2Pin_3.2x1.5mm; LCSC C32346
Y2: 16MHz X322516MLB4SI; Crystal_SMD_3225-4Pin_3.2x2.5mm; LCSC C13738

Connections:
+3V3: C29.1, C31.1, C33.1, C34.1, C35.1, C37.1, C38.1, D5.2 (A), DWM1.5 (VDDAON), DWM1.6 (VDD3V3), DWM1.7 (VDD3V3), J1.1 (VCC), R19.1, R21.2, R22.2, R23.2, U3.9 (VDDA), U3.24 (VDD), U3.36 (VDD), U3.48 (VDD); also elsewhere on the board
/BMS_INT: R21.1, U3.12 (PA2); also elsewhere on the board
/BMS_QONn: U3.11 (PA1); also elsewhere on the board
/BMS_SCL: R22.1, U3.30 (PA9); also elsewhere on the board
/BMS_SDL: R23.1, U3.31 (PA10); also elsewhere on the board
/Buck_EN: U3.2 (PC13); also elsewhere on the board
/MCU/3V3_sense: C36.1, R19.2, R20.1, U3.13 (PA3)
/MCU/BOOT0: R18.2, U3.44 (PH3)
/MCU/DWM_IRQ: DWM1.22 (IRQ/GPIO8), R25.1, U3.10 (PA0)
/MCU/DWM_nRST: DWM1.3 (~RST), U3.20 (PB2)
/MCU/EXTON: DWM1.1 (EXTON), U3.18 (PB0)
/MCU/NRST: C28.1, J1.3 (~RESET), U3.7 (NRST)
/MCU/RCC_OSC32_IN: C25.1, U3.3 (PC14), Y1.1
/MCU/RCC_OSC32_OUT: C26.1, U3.4 (PC15), Y1.2
/MCU/RCC_OSC_IN: C30.1, U3.5 (PH0), Y2.1
/MCU/RCC_OSC_OUT: C32.1, U3.6 (PH1), Y2.3
/MCU/SPI1_MISO: DWM1.19 (SPIMISO), U3.16 (PA6)
/MCU/SPI1_MOSI: DWM1.18 (SPIMOSI), U3.17 (PA7)
/MCU/SPI1_NSS: DWM1.17 (~SPICS), U3.14 (PA4)
/MCU/SPI1_SCK: DWM1.20 (SPICLK), U3.15 (PA5)
/MCU/SWCLK: J1.4 (SWCLK), U3.37 (PA14)
/MCU/SWDIO: J1.2 (SWDIO), U3.34 (PA13)
/MCU/SWO: J1.6 (SWO), U3.39 (PB3)
/MCU/WAKEUP: DWM1.2 (WAKEUP), U3.19 (PB1)
GND: C25.2, C26.2, C27.2, C28.2, C29.2, C30.2, C31.2, C32.2, C33.2, C34.2, C35.2, C36.2, C37.2, C38.2, DWM1.8 (VSS), DWM1.16 (VSS), DWM1.21 (VSS), DWM1.23 (VSS), DWM1.24 (VSS), J1.5 (GND), JP3.1 (A), JP4.1 (A), R18.1, R20.2, R25.2, U3.8 (VSSA), U3.23 (VSS), U3.35 (VSS), U3.47 (VSS), Y2.2 (G), Y2.4 (G); also elsewhere on the board
unnamed: C27.1, R17.1
unnamed: D5.1 (K), R17.2, U3.1 (VBAT)
unnamed: D6.2 (A), R24.2
unnamed: D6.1 (K), JP3.2 (B)
unnamed: D7.2 (A), R26.2
unnamed: D7.1 (K), JP4.2 (B)
unnamed: DWM1.15 (GPIO0/RXOKLED), R26.1
unnamed: DWM1.12 (GPIO3/TXLED), R24.1

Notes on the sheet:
VBAT ~500nA for RTC 100uF * (3.2V - 1.55V) / 500nA -> 5.5min 3.3V/100R = 3.3mA inrush 100R*500nA = 50uV -> VBAT @ 3.3V quicker with R below
The GPIOs can sink or source up to ±8 mA, and sink or source up to ± 20 mA (with a relaxed VOL/VOH).
C_L = 12.5pF C_stray = 5pF (12.5 - 5)*2 = 15pF
C_L = 9pF C_stray = 4pF (9-4)*2 = 10pF
High Resistors for low leakage. 5pF Internal sample and hold capacitor. Cuttoff @ ~3kHz
RSTn should never be driven high by an external source!
HSE crystal
Voltage Divider for sensing 3V3
Transiver and Ranging
LSE crystal
Main Microcontroller
Programming/Debug Interface

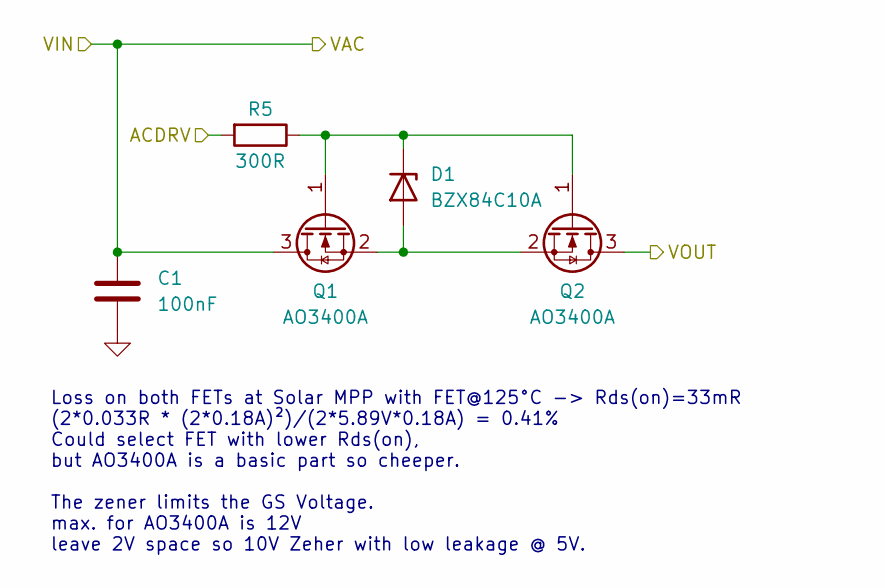
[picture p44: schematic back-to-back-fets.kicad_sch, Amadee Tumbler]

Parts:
C1: 100nF; C_0402_1005Metric_Pad0.74x0.62mm_HandSolder
D1: BZX84C10A; SOT-23; LCSC C5155278
Q1, Q2: AO3400A; SOT-23; LCSC C20917
R5: 300R; R_0402_1005Metric_Pad0.72x0.64mm_HandSolder

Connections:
/BMS/ACDRV1: R5.2; also elsewhere on the board
/Vbus: Q2.3 (D); also elsewhere on the board
GND: C1.2; also elsewhere on the board
unnamed: D1.1 (A), Q1.2 (S), Q2.2 (S)
unnamed: D1.3 (K), Q1.1 (G), Q2.1 (G), R5.1
VBUS: C1.1, Q1.3 (D); also elsewhere on the board

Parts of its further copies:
C2: 100nF; C_0402_1005Metric_Pad0.74x0.62mm_HandSolder
D2: BZX84C10A; SOT-23; LCSC C5155278
Q3, Q4: AO3400A; SOT-23; LCSC C20917
R6: 300R; R_0402_1005Metric_Pad0.72x0.64mm_HandSolder

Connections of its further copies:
/BMS/ACDRV2: R6.2; also elsewhere on the board
/BMS/VAC2: C2.1, Q3.3 (D); also elsewhere on the board
/Vbus: Q4.3 (D); also elsewhere on the board
GND: C2.2; also elsewhere on the board
unnamed: D2.1 (A), Q3.2 (S), Q4.2 (S)
unnamed: D2.3 (K), Q3.1 (G), Q4.1 (G), R6.1

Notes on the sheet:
Loss on both FETs at Solar MPP with FET@125°C -> Rds(on)=33mR (2*0.033R * (2*0.18A)²)/(2*5.89V*0.18A) = 0.41% Could select FET with lower Rds(on), but AO3400A is a basic part so cheeper. The zener limits the GS Voltage. max. for AO3400A is 12V leave 2V space so 10V Zeher with low leakage @ 5V.

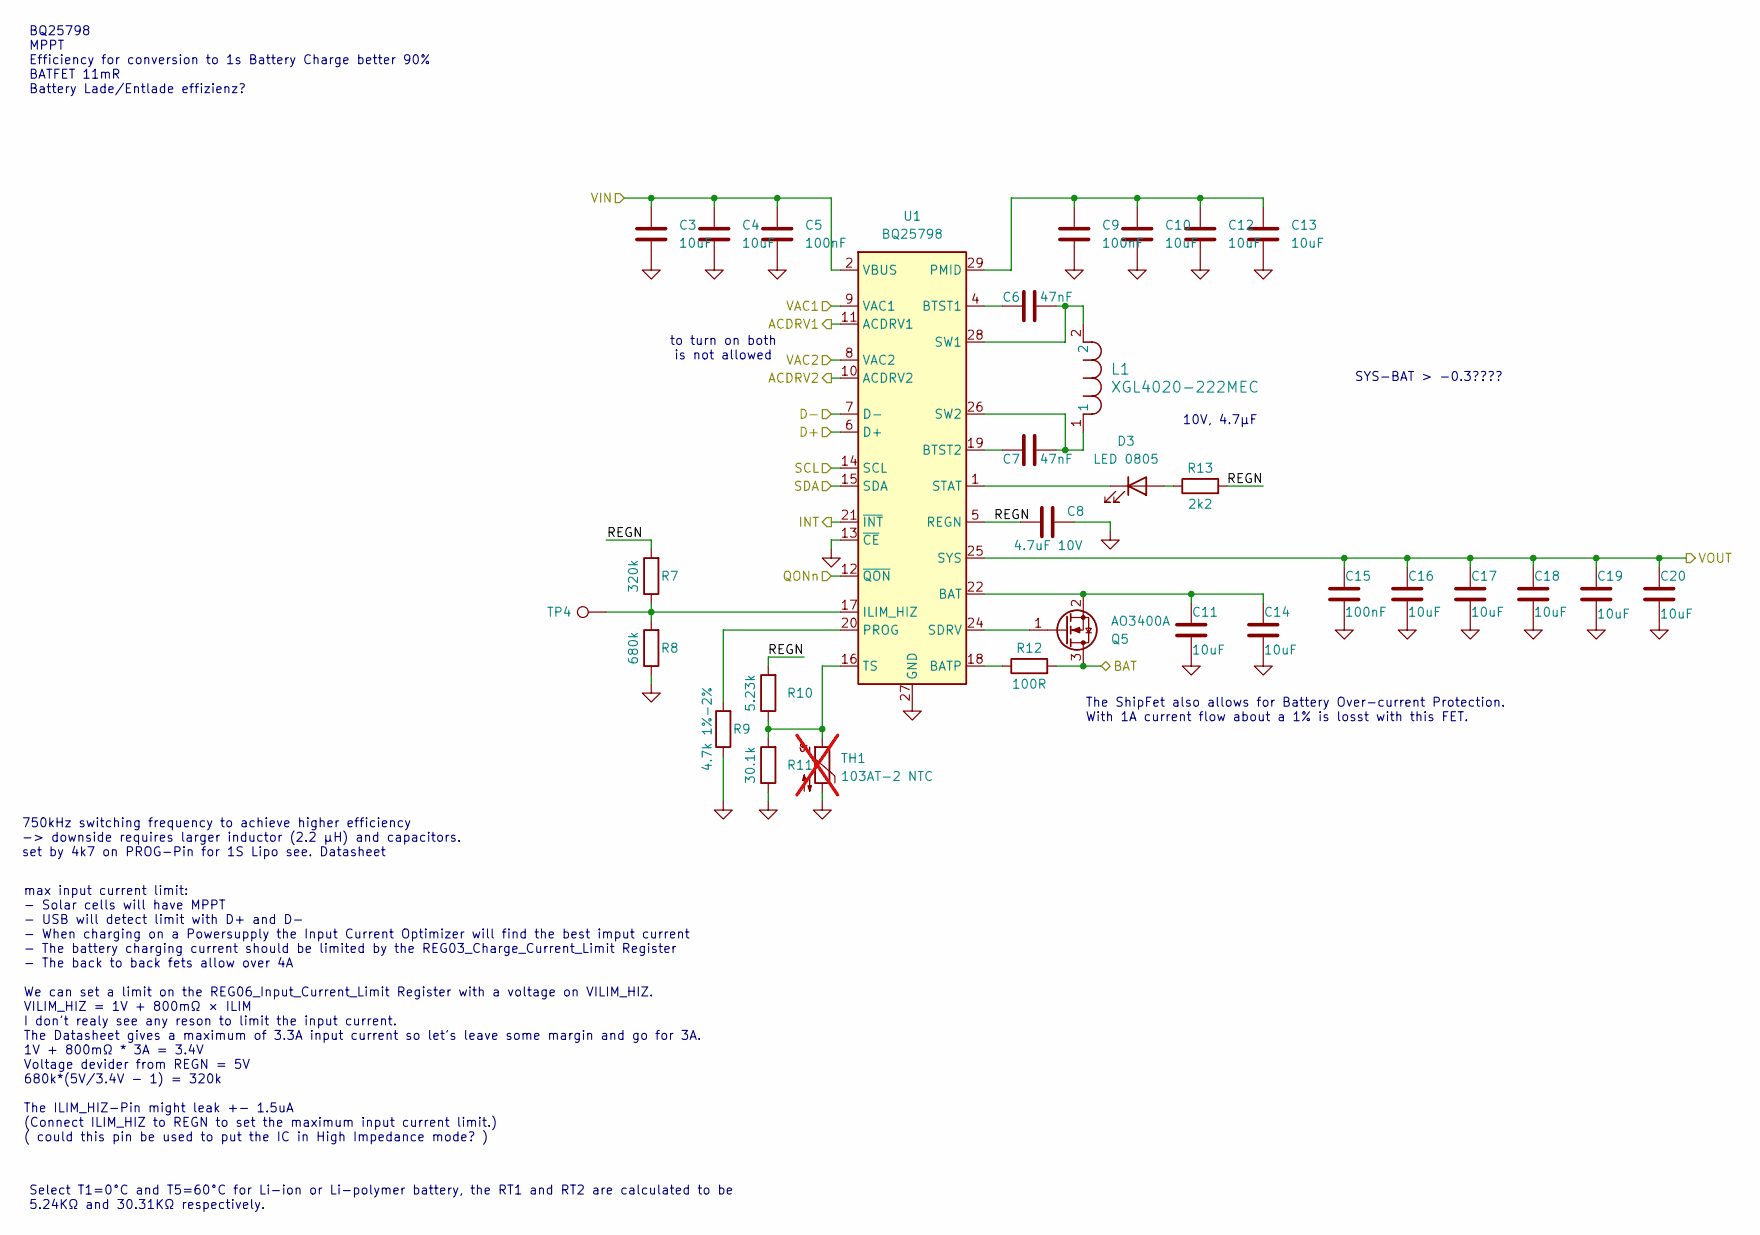
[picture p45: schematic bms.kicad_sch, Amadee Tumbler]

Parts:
C3, C4, C10, C11, C12, C13, C14, C16, C17, C18, C19, C20: 10uF; C_0402_1005Metric_Pad0.74x0.62mm_HandSolder
C5, C9, C15: 100nF; C_0402_1005Metric_Pad0.74x0.62mm_HandSolder
C6, C7: 47nF; C_0402_1005Metric_Pad0.74x0.62mm_HandSolder
C8: 4.7uF 10V; C_0402_1005Metric_Pad0.74x0.62mm_HandSolder
D3: LED 0805; LED_0805_2012Metric_Pad1.15x1.40mm_HandSolder; LCSC C2296
L1: XGL4020-222MEC; IND_XGL4020_COC
Q5: AO3400A; SOT-23; LCSC C20917
R7: 320k; R_0402_1005Metric_Pad0.72x0.64mm_HandSolder
R8: 680k; R_0402_1005Metric_Pad0.72x0.64mm_HandSolder
R9: 4.7k 1%-2%; R_0402_1005Metric_Pad0.72x0.64mm_HandSolder
R10: 5.23k; R_0402_1005Metric_Pad0.72x0.64mm_HandSolder
R11: 30.1k; R_0402_1005Metric_Pad0.72x0.64mm_HandSolder
R12: 100R; R_0402_1005Metric_Pad0.72x0.64mm_HandSolder
R13: 2k2; R_0402_1005Metric_Pad0.72x0.64mm_HandSolder
TH1: 103AT-2 NTC; PinHeader_1x02_P2.54mm_Vertical; not fitted
TP4: TestPoint; TestPoint_Pad_D1.0mm
U1: BQ25798; Texas_RQM0029A_VQFN-29_4x4mm_P0.4mm

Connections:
+BATT: Q5.3 (D), R12.2; also elsewhere on the board
/BMS/ACDRV1: U1.11 (ACDRV1); also elsewhere on the board
/BMS/ACDRV2: U1.10 (ACDRV2); also elsewhere on the board
/BMS/D+: U1.6 (D+); also elsewhere on the board
/BMS/D-: U1.7 (D-); also elsewhere on the board
/BMS/REGN: C8.1, R7.2, R10.2, R13.2, U1.5 (REGN)
/BMS/VAC2: U1.8 (VAC2); also elsewhere on the board
/BMS_INT: U1.21 (~INT); also elsewhere on the board
/BMS_QONn: U1.12 (~QON); also elsewhere on the board
/BMS_SCL: U1.14 (SCL); also elsewhere on the board
/BMS_SDL: U1.15 (SDA); also elsewhere on the board
/Vbus: C3.1, C4.1, C5.1, U1.2 (VBUS), U1.3 (VBUS); also elsewhere on the board
/Vsys: C15.1, C16.1, C17.1, C18.1, C19.1, C20.1, U1.25 (SYS); also elsewhere on the board
GND: C3.2, C4.2, C5.2, C8.2, C9.2, C10.2, C11.2, C12.2, C13.2, C14.2, C15.2, C16.2, C17.2, C18.2, C19.2, C20.2, R8.1, R9.1, R11.1, TH1.2, U1.13 (~CE), U1.27 (GND); also elsewhere on the board
unnamed: D3.2 (A), R13.1
unnamed: D3.1 (K), U1.1 (STAT)
unnamed: Q5.1 (G), U1.24 (SDRV)
unnamed: C11.1, C14.1, Q5.2 (S), U1.22 (BAT), U1.23 (BAT)
unnamed: R12.1, U1.18 (BATP)
unnamed: C6.1, U1.4 (BTST1)
unnamed: C7.1, U1.19 (BTST2)
unnamed: R7.1, R8.2, TP4.1 (1_1), U1.17 (ILIM_HIZ)
unnamed: C9.1, C10.1, C12.1, C13.1, U1.29 (PMID)
unnamed: R9.2, U1.20 (PROG)
unnamed: C6.2, L1.2, U1.28 (SW1)
unnamed: C7.2, L1.1, U1.26 (SW2)
unnamed: R10.1, R11.2, TH1.1, U1.16 (TS)
VBUS: U1.9 (VAC1); also elsewhere on the board

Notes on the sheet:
SYS-BAT > -0.3????
The ShipFet also allows for Battery Over-current Protection. With 1A current flow about a 1% is losst with this FET.
max input current limit: - Solar cells will have MPPT - USB will detect limit with D+ and D- - When charging on a Powersupply the Input Current Optimizer will find the best imput current - The battery charging current should be limited by the REG03_Charge_Current_Limit Register - The back to back f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
BQ25798 MPPT Efficiency for conversion to 1s Battery Charge better 90% BATFET 11mR Battery Lade/Entlade effizienz?
10V, 4.7μF
Select T1=0°C and T5=60°C for Li-ion or Li-polymer battery, the RT1 and RT2 are calculated to be 5.24KΩ and 30.31KΩ respectively.
750kHz switching frequency to achieve higher efficiency -> downside requires larger inductor (2.2 μH) and capacitors. set by 4k7 on PROG-Pin for 1S Lipo see. Datasheet
to turn on both is not allowed

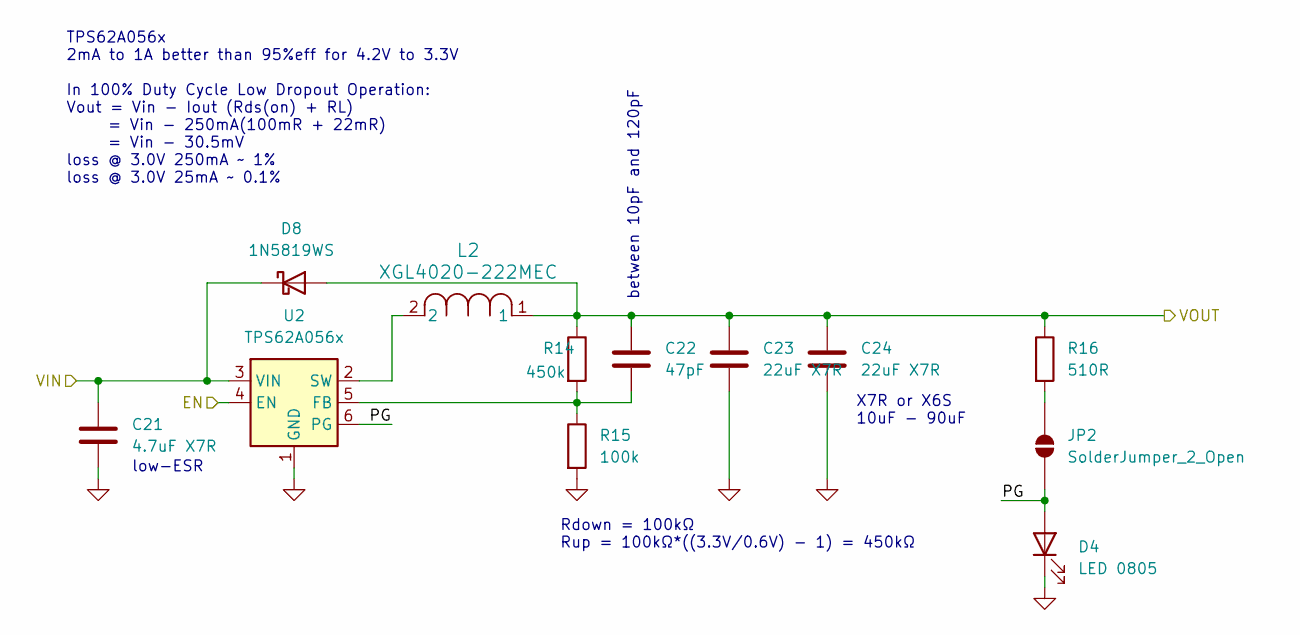
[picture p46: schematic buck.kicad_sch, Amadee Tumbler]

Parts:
C21: 4.7uF X7R; C_0805_2012Metric_Pad1.18x1.45mm_HandSolder; LCSC C49678
C22: 47pF; C_0402_1005Metric_Pad0.74x0.62mm_HandSolder
C23, C24: 22uF X7R; C_0805_2012Metric_Pad1.18x1.45mm_HandSolder
D4: LED 0805; LED_0805_2012Metric_Pad1.15x1.40mm_HandSolder; LCSC C2296
D8: 1N5819WS; D_SOD-323
JP2: SolderJumper_2_Open; SolderJumper-2_P1.3mm_Open_RoundedPad1.0x1.5mm
L2: XGL4020-222MEC; IND_XGL4020_COC
R14: 450k; R_0402_1005Metric_Pad0.72x0.64mm_HandSolder
R15: 100k; R_0402_1005Metric_Pad0.72x0.64mm_HandSolder
R16: 510R; R_0402_1005Metric_Pad0.72x0.64mm_HandSolder
U2: TPS62A056x; SOT-563

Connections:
+3V3: C22.1, C23.1, C24.1, D8.2 (A), L2.1, R14.1, R16.1; also elsewhere on the board
/Buck/PG: D4.2 (A), JP2.1 (A), U2.6 (PG)
/Buck_EN: U2.4 (EN); also elsewhere on the board
/Vsys: C21.1, D8.1 (K), U2.3 (VIN); also elsewhere on the board
GND: C21.2, C23.2, C24.2, D4.1 (K), R15.2, U2.1 (GND); also elsewhere on the board
unnamed: JP2.2 (B), R16.2
unnamed: C22.2, R14.2, R15.1, U2.5 (FB)
unnamed: L2.2, U2.2 (SW)

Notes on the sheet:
Rdown = 100kΩ Rup = 100kΩ*((3.3V/0.6V) - 1) = 450kΩ
low-ESR
TPS62A056x 2mA to 1A better than 95%eff for 4.2V to 3.3V In 100% Duty Cycle Low Dropout Operation: Vout = Vin - Iout (Rds(on) + RL) = Vin - 250mA(100mR + 22mR) = Vin - 30.5mV loss @ 3.0V 250mA ~ 1% loss @ 3.0V 25mA ~ 0.1%
between 10pF and 120pF
X7R or X6S 10uF - 90uF

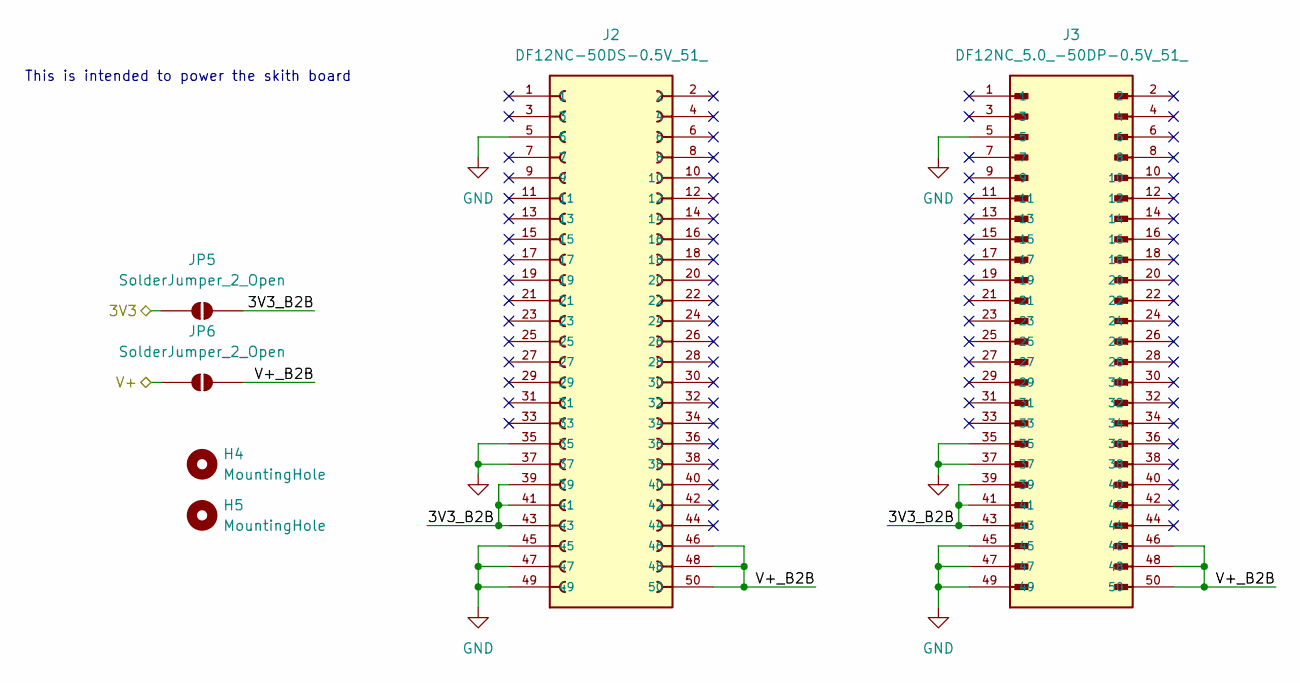
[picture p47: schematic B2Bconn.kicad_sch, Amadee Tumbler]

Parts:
H4, H5: MountingHole; MountingHole_3.2mm_M3_DIN965
J2: DF12NC-50DS-0.5V_51_; HRS_DF12NC-50DS-0.5V_51_; DigiKey_Part_Number 26-DF12NC-50DS-0.5V(51)CT-ND
J3: DF12NC_5.0_-50DP-0.5V_51_; HRS_DF12NC_5.0_-50DP-0.5V_51_; DigiKey_Part_Number 26-DF12NC(5.0)-50DP-0.5V(51)CT-ND
JP5, JP6: SolderJumper_2_Open; SolderJumper-2_P1.3mm_Open_RoundedPad1.0x1.5mm

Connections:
+3V3: JP5.2 (B); also elsewhere on the board
/BoardToBoardConnectors/3V3_B2B: J2.39, J2.41, J2.43, J3.39, J3.41, J3.43, JP5.1 (A)
/BoardToBoardConnectors/V+_B2B: J2.46, J2.48, J2.50, J3.46, J3.48, J3.50, JP6.1 (A)
/Vsys: JP6.2 (B); also elsewhere on the board
GND: J2.5, J2.35, J2.37, J2.45, J2.47, J2.49, J3.5, J3.35, J3.37, J3.45, J3.47, J3.49; also elsewhere on the board

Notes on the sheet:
This is intended to power the skith board

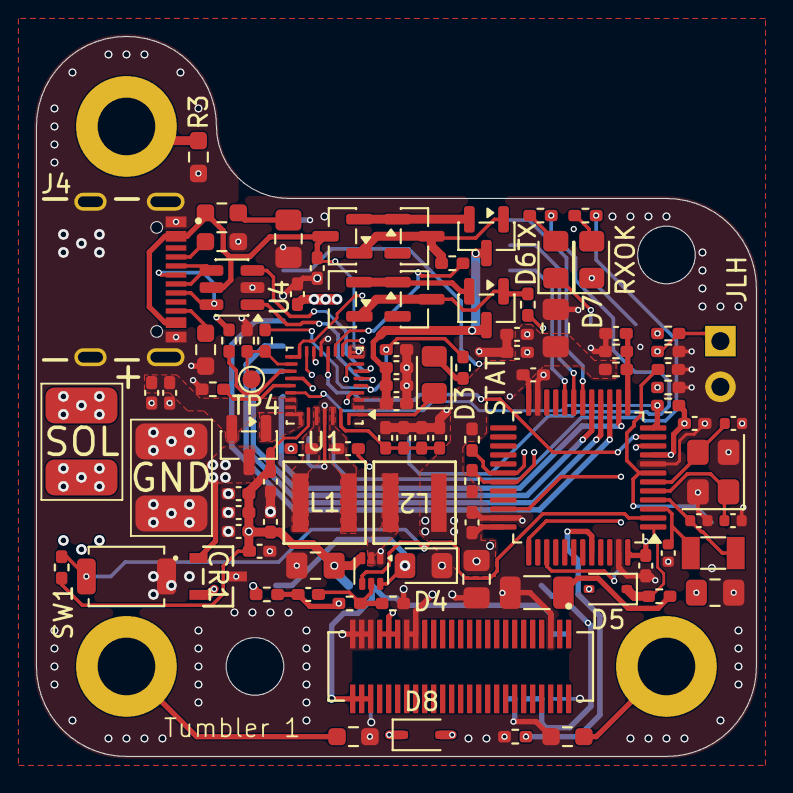
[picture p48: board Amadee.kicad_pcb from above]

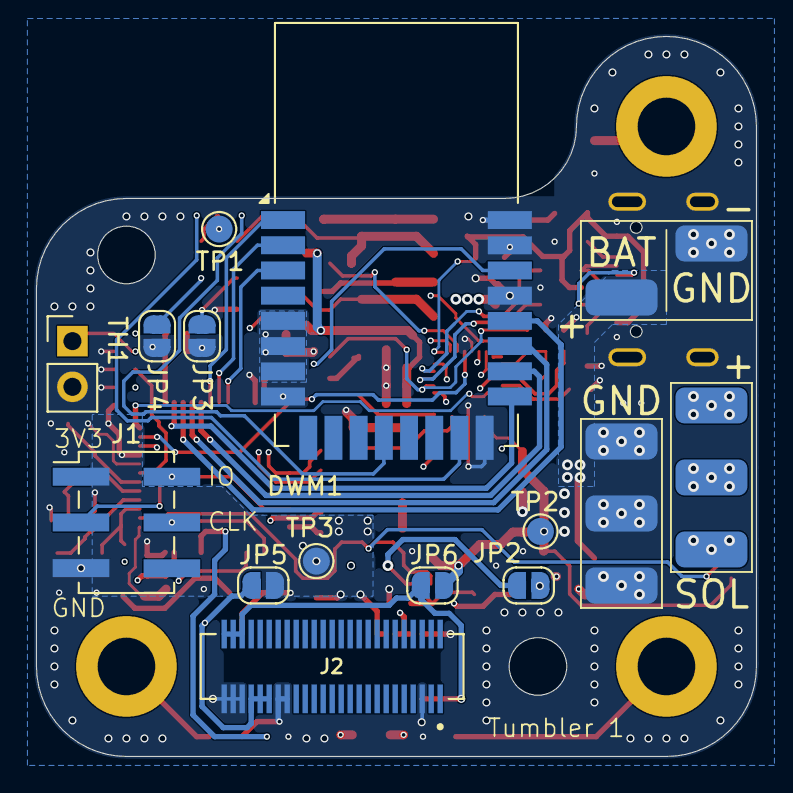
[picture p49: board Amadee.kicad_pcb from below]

Board: 4 copper layers, 40.0 x 40.0 mm, 123 parts (20 on the bottom side), 74 nets.

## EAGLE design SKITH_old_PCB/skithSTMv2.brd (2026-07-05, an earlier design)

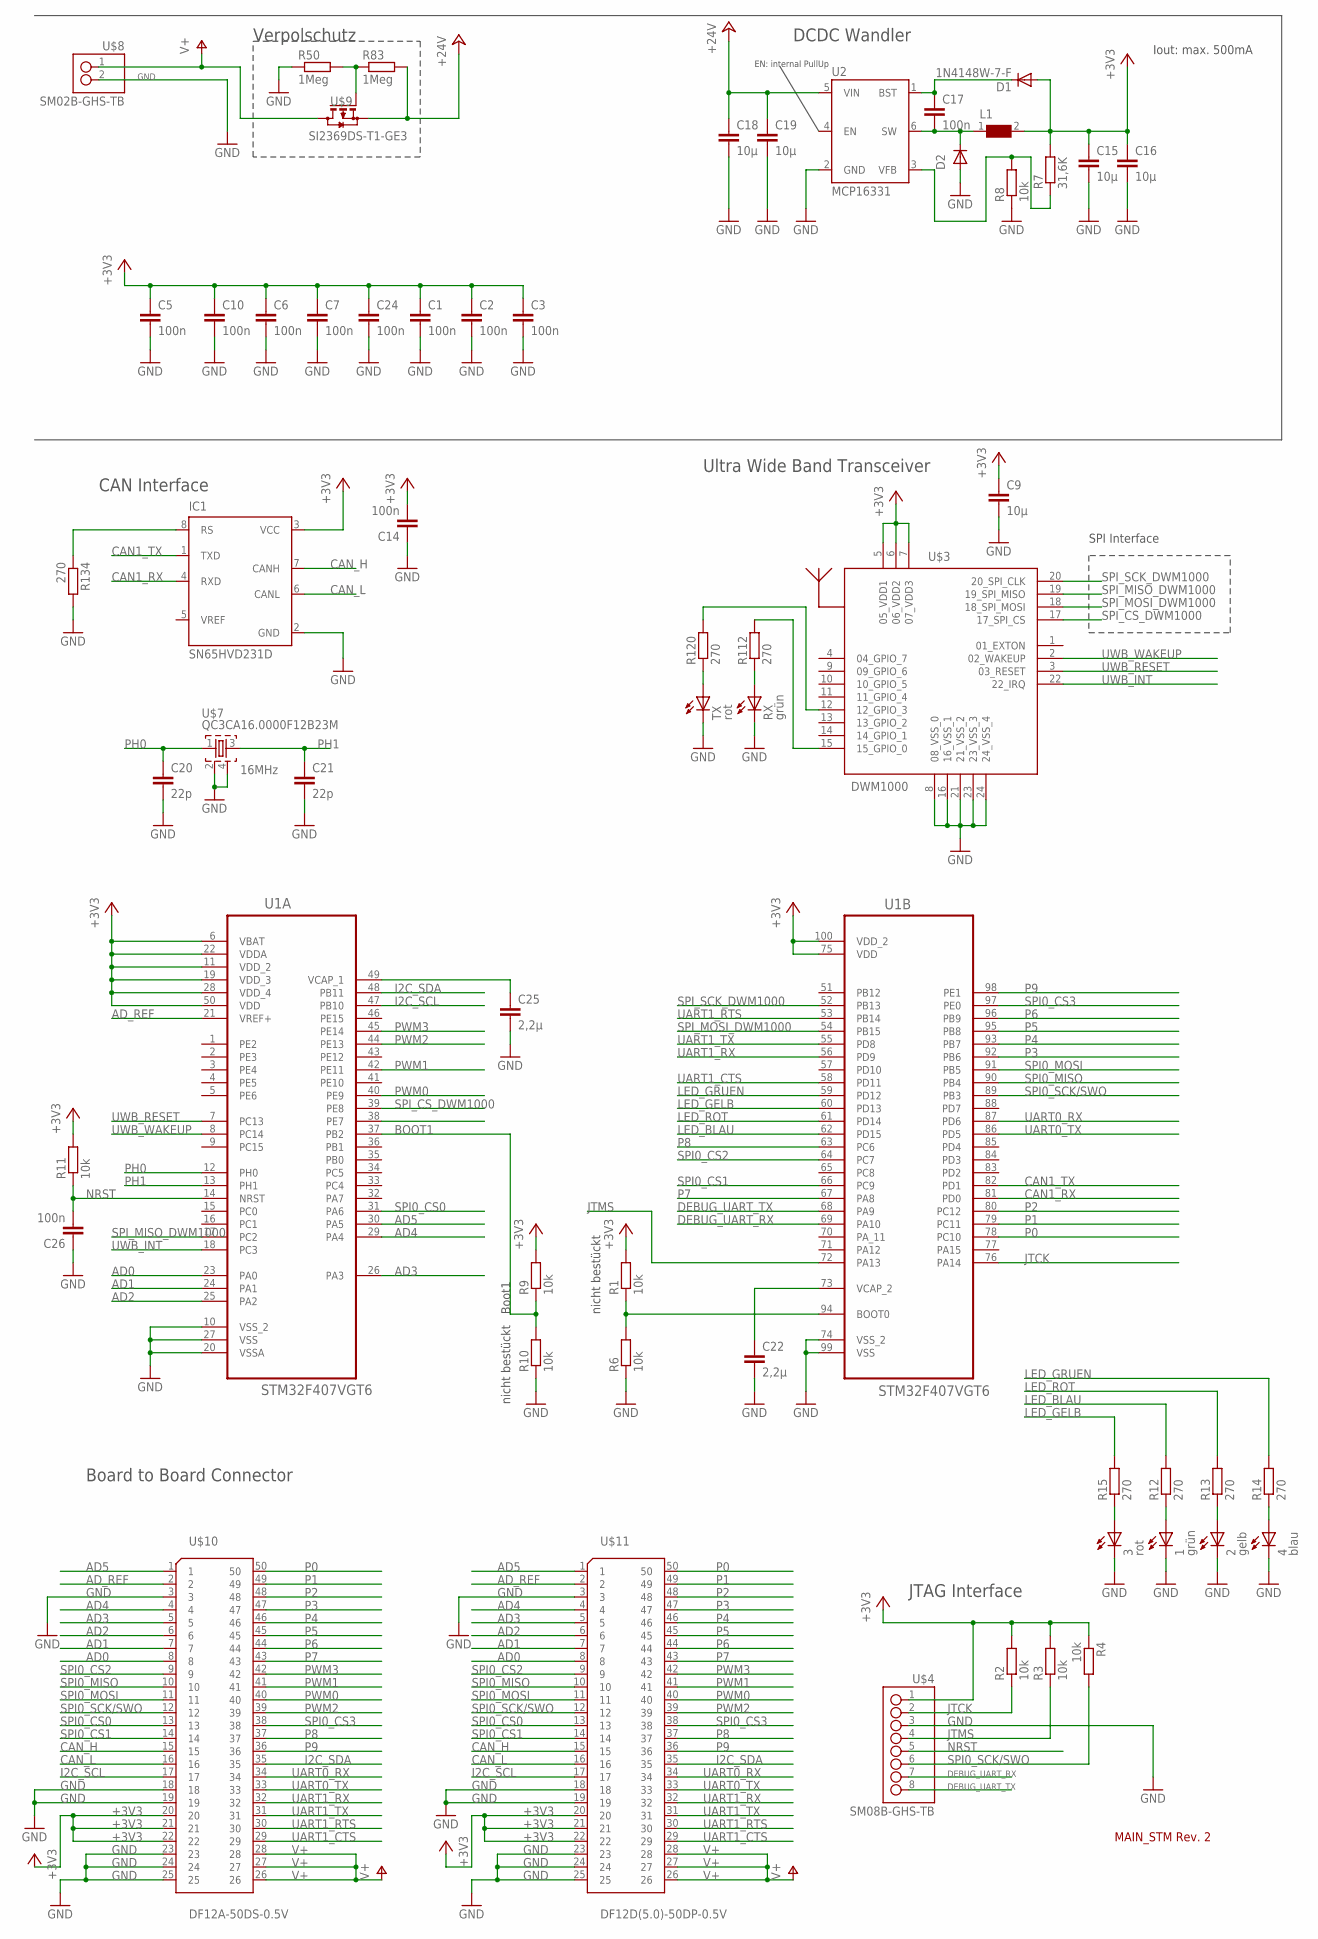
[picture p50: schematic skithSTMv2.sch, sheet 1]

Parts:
1: grün; SML0603
2: gelb; SML0603
3: rot; SML0603
4: blau; SML0603
C1, C2, C3, C5, C6, C7, C10, C14, C17, C24, C26: 100n; C0402
C9, C15, C16, C18, C19: 10µ; C0805
C20, C21: 22p; C0402
C22, C25: 2,2µ; C0402
D1: 1N4148W-7-F; SOD123
D2: DIODE-DO214AC; DO214AC
IC1: SN65HVD231D; SO8
L1: WE-TPC-744025150_2828; WE-TPC_2828
R1, R2, R3, R4, R6, R8, R9, R10, R11: 10k; R0402
R7: 31,6K; R0402
R12, R13, R14, R15, R112, R120, R134: 270; R0402
R50, R83: 1Meg; R0402
RX: grün; SML0603
TX: rot; SML0603
U1: STM32F407VGT6; QFP50P1600X1600X160-100N
U2: MCP16331; SOT23-6
U$3: DWM1000
U$4: SM08B-GHS-TB
U$7: QC3CA16.0000F12B23M; LFXTAL055998
U$8: SM02B-GHS-TB
U$9: SI2369DS-T1-GE3; SOT23
U$10: DF12A-50DS-0.5V
U$11: DF12D(5.0)-50DP-0.5V

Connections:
+3V3: C1.1, C2.1, C3.1, C5.1, C6.1, C7.1, C9.1, C10.1, C14.2, C15.1, C16.1, C24.1, D1.A, IC1.3 (VCC), L1.2, R1.2, R2.2, R3.2, R4.1, R7.2, R9.2, R11.2, U1.6 (VBAT), U1.11 (VDD_2), U1.19 (VDD_3), U1.22 (VDDA), U1.28 (VDD_4), U1.50 (VDD), U1.75 (VDD), U1.100 (VDD_2), U$3.5 (05_VDD1), U$3.6 (06_VDD2), U$3.7 (07_VDD3), U$4.1, U$10.20, U$10.21, U$10.22, U$11.20, U$11.21, U$11.22
+24V: C18.1, C19.1, R83.2, U2.5 (VIN), U$9.2 (S)
AD0: U1.23 (PA0), U$10.8, U$11.8
AD1: U1.24 (PA1), U$10.7, U$11.7
AD2: U1.25 (PA2), U$10.6, U$11.6
AD3: U1.26 (PA3), U$10.5, U$11.5
AD4: U1.29 (PA4), U$10.4, U$11.4
AD5: U1.30 (PA5), U$10.1, U$11.1
AD_REF: U1.21 (VREF+), U$10.2, U$11.2
BOOT1: R9.1, R10.2, U1.37 (PB2)
CAN1_RX: IC1.4 (RXD), U1.81 (PD0)
CAN1_TX: IC1.1 (TXD), U1.82 (PD1)
CAN_H: IC1.7 (CANH), U$10.15, U$11.15
CAN_L: IC1.6 (CANL), U$10.16, U$11.16
DEBUG_UART_RX: U1.69 (PA10), U$4.7
DEBUG_UART_TX: U1.68 (PA9), U$4.8
GND: 1.C, 2.C, 3.C, 4.C, C1.2, C2.2, C3.2, C5.2, C6.2, C7.2, C9.2, C10.2, C14.1, C15.2, C16.2, C18.2, C19.2, C20.2, C21.2, C22.2, C24.2, C25.2, C26.1, D2.A, IC1.2 (GND), R6.1, R8.1, R10.1, R50.1, R134.2, RX.C, TX.C, U1.10 (VSS_2), U1.20 (VSSA), U1.27 (VSS), U1.74 (VSS_2), U1.99 (VSS), U2.2 (GND), U$3.8 (08_VSS_0), U$3.16 (16_VSS_1), U$3.21 (21_VSS_2), U$3.23 (23_VSS_3), U$3.24 (24_VSS_4), U$4.3, U$7.2, U$7.4, U$8.2, U$10.3, U$10.18, U$10.19, U$10.23, U$10.24, U$10.25, U$11.3, U$11.18, U$11.19, U$11.23, U$11.24, U$11.25
I2C_SCL: U1.47 (PB10), U$10.17, U$11.17
I2C_SDA: U1.48 (PB11), U$10.35, U$11.35
JTCK: R2.1, U1.76 (PA14), U$4.2
JTMS: R3.1, U1.72 (PA13), U$4.4
LED_BLAU: R12.2, U1.62 (PD15)
LED_GELB: R15.2, U1.60 (PD13)
LED_GRUEN: R14.2, U1.59 (PD12)
LED_ROT: R13.2, U1.61 (PD14)
unnamed: C22.1, U1.73 (VCAP_2)
unnamed: R112.2, U$3.15 (15_GPIO_0)
unnamed: R7.1, R8.2, U2.3 (VFB)
unnamed: C17.1, D1.C, U2.1 (BST)
unnamed: C17.2, D2.C, L1.1, U2.6 (SW)
unnamed: 1.A, R12.1
unnamed: 2.A, R13.1
unnamed: 4.A, R14.1
unnamed: R1.1, R6.2, U1.94 (BOOT0)
unnamed: 3.A, R15.1
unnamed: C25.1, U1.49 (VCAP_1)
unnamed: IC1.8 (RS), R134.1
unnamed: R112.1, RX.A
unnamed: R120.1, TX.A
unnamed: R120.2, U$3.12 (12_GPIO_3)
unnamed: R50.2, R83.1, U$9.1 (G)
NRST: C26.2, R11.1, U1.14 (NRST), U$4.5
P0: U1.78 (PC10), U$10.50, U$11.50
P1: U1.79 (PC11), U$10.49, U$11.49
P2: U1.80 (PC12), U$10.48, U$11.48
P3: U1.92 (PB6), U$10.47, U$11.47
P4: U1.93 (PB7), U$10.46, U$11.46
P5: U1.95 (PB8), U$10.45, U$11.45
P6: U1.96 (PB9), U$10.44, U$11.44
P7: U1.67 (PA8), U$10.43, U$11.43
P8: U1.63 (PC6), U$10.37, U$11.37
P9: U1.98 (PE1), U$10.36, U$11.36
PH0: C20.1, U1.12 (PH0), U$7.1
PH1: C21.1, U1.13 (PH1), U$7.3
PWM0: U1.40 (PE9), U$10.40, U$11.40
PWM1: U1.42 (PE11), U$10.41, U$11.41
PWM2: U1.44 (PE13), U$10.39, U$11.39
PWM3: U1.45 (PE14), U$10.42, U$11.42
SPI0_CS0: U1.31 (PA6), U$10.13, U$11.13
SPI0_CS1: U1.66 (PC9), U$10.14, U$11.14
SPI0_CS2: U1.64 (PC7), U$10.9, U$11.9
SPI0_CS3: U1.97 (PE0), U$10.38, U$11.38
SPI0_MISO: U1.90 (PB4), U$10.10, U$11.10
SPI0_MOSI: U1.91 (PB5), U$10.11, U$11.11
SPI0_SCK/SWO: R4.2, U1.89 (PB3), U$4.6, U$10.12, U$11.12
SPI_CS_DWM1000: U1.39 (PE8), U$3.17 (17_SPI_CS)
SPI_MISO_DWM1000: U1.17 (PC2), U$3.19 (19_SPI_MISO)
SPI_MOSI_DWM1000: U1.54 (PB15), U$3.18 (18_SPI_MOSI)
SPI_SCK_DWM1000: U1.52 (PB13), U$3.20 (20_SPI_CLK)
UART0_RX: U1.87 (PD6), U$10.34, U$11.34
UART0_TX: U1.86 (PD5), U$10.33, U$11.33
UART1_CTS: U1.58 (PD11), U$10.29, U$11.29
UART1_RTS: U1.53 (PB14), U$10.30, U$11.30
UART1_RX: U1.56 (PD9), U$10.32, U$11.32
UART1_TX: U1.55 (PD8), U$10.31, U$11.31
UWB_INT: U1.18 (PC3), U$3.22 (22_IRQ)
UWB_RESET: U1.7 (PC13), U$3.3 (03_RESET)
UWB_WAKEUP: U1.8 (PC14), U$3.2 (02_WAKEUP)
V+: U$8.1, U$9.3 (D), U$10.26, U$10.27, U$10.28, U$11.26, U$11.27, U$11.28

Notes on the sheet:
DCDC Wandler
SPI Interface
Ultra Wide Band Transceiver
CAN Interface
EN: internal PullUp
Verpolschutz
16MHz
JTAG Interface
Board to Board Connector
Iout: max. 500mA
nicht bestückt
Boot1
MAIN_STM Rev. 2



Board: 4 copper layers, 30.5 x 30.5 mm, 61 parts (34 on the bottom side), 79 nets.

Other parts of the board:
U$1, U$5, U$6: 3,2

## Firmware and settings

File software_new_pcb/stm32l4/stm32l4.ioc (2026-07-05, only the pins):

Mcu.UserName=STM32L431CCTx
PA0.GPIO_Label=DWM_IRQ
PA0.Signal=GPXTI0
PA1.GPIO_Label=BMS_QONn
PA1.Signal=GPIO_Output
PA10.GPIO_Label=BMS_SDA
PA10.Signal=I2C1_SDA
PA2.GPIO_Label=BMS_INT
PA2.Signal=GPIO_Input
PA3.Signal=ADCx_IN8
PA4.GPIO_Label=SPI1_NSS
PA4.Signal=GPIO_Output
PA5.Signal=SPI1_SCK
PA6.Signal=SPI1_MISO
PA7.Signal=SPI1_MOSI
PA9.GPIO_Label=BMS_SCL
PA9.Signal=I2C1_SCL
PB0.GPIO_Label=EXTON
PB0.Signal=GPIO_Output
PB1.GPIO_Label=WAKEUP
PB1.Signal=GPIO_Output
PB2.GPIO_Label=DWM_nRST
PB2.Signal=GPIO_Output
PC13.GPIO_Label=Buck_EN
PC13.Signal=GPIO_Output

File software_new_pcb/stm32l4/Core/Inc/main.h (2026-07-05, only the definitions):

#define Buck_EN_Pin GPIO_PIN_13
#define Buck_EN_GPIO_Port GPIOC
#define DWM_IRQ_Pin GPIO_PIN_0
#define DWM_IRQ_GPIO_Port GPIOA
#define DWM_IRQ_EXTI_IRQn EXTI0_IRQn
#define BMS_QONn_Pin GPIO_PIN_1
#define BMS_QONn_GPIO_Port GPIOA
#define BMS_INT_Pin GPIO_PIN_2
#define BMS_INT_GPIO_Port GPIOA
#define SPI1_NSS_Pin GPIO_PIN_4
#define SPI1_NSS_GPIO_Port GPIOA
#define EXTON_Pin GPIO_PIN_0
#define EXTON_GPIO_Port GPIOB
#define WAKEUP_Pin GPIO_PIN_1
#define WAKEUP_GPIO_Port GPIOB
#define DWM_nRST_Pin GPIO_PIN_2
#define DWM_nRST_GPIO_Port GPIOB
#define BMS_SCL_Pin GPIO_PIN_9
#define BMS_SCL_GPIO_Port GPIOA
#define BMS_SDA_Pin GPIO_PIN_10
#define BMS_SDA_GPIO_Port GPIOA

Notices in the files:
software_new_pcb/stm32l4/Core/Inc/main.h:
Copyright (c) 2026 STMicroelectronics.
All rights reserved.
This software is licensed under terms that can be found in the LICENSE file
